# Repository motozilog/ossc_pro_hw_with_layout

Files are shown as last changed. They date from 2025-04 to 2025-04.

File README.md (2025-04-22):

# OSSC Pro HW with layout
==============

## No actual PCB was built from these files to validate the manufacturing.

This PCB full routing without DRC error, but I don't know how to make the trace length equal within a byte group. And the power doesn't optimized.

I share this PCB, may someone can finish it.

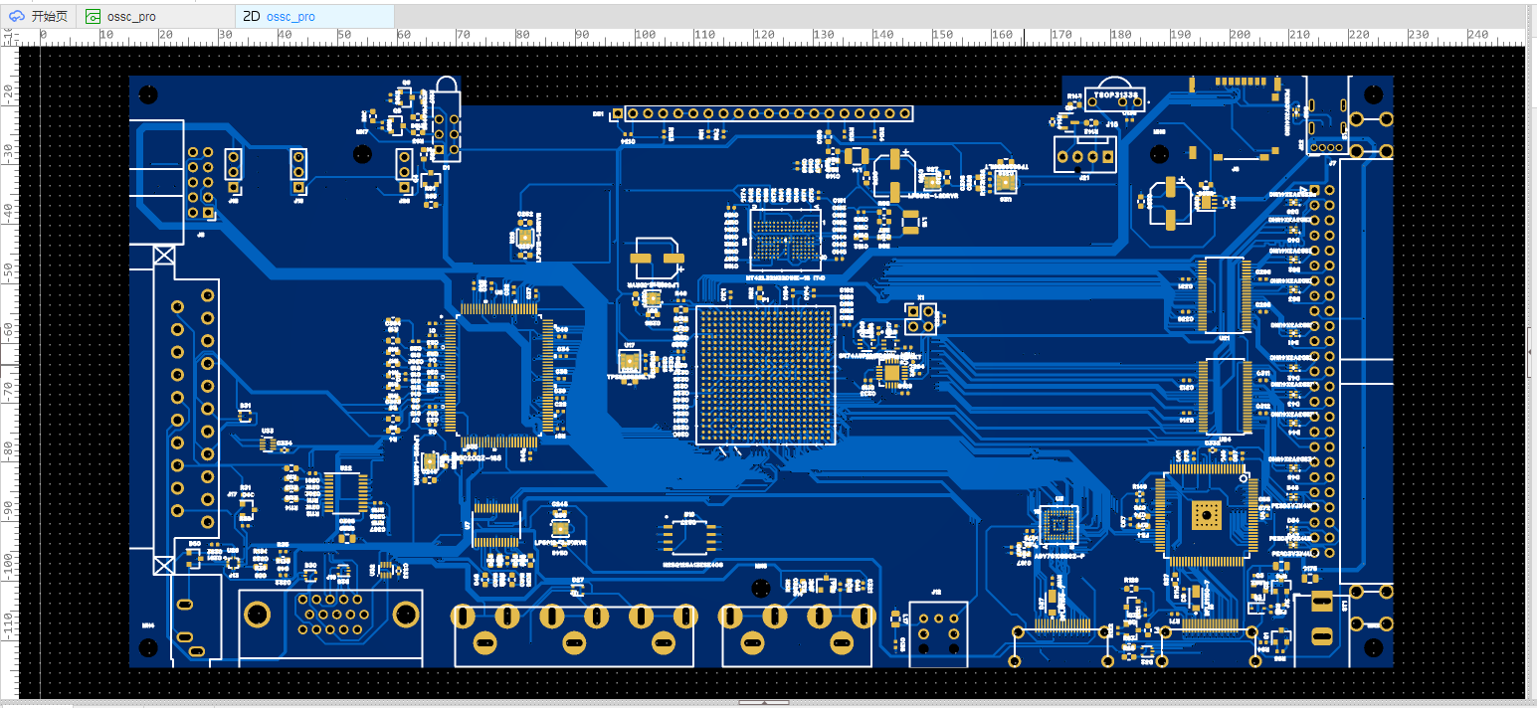
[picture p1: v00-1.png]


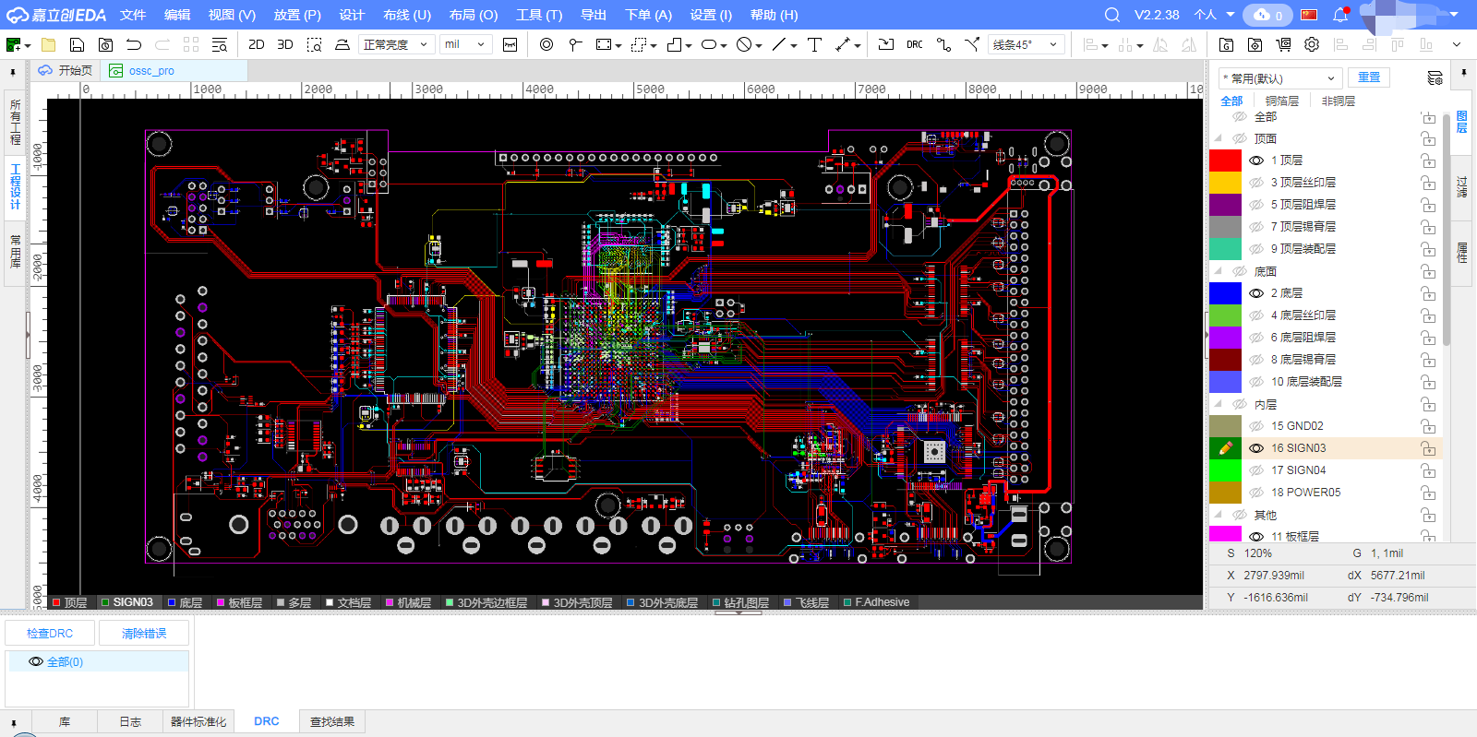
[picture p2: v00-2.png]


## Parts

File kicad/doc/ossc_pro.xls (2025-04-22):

Ref | Qnty | Value | Footprint | MPN | Alternative part | Supplier URL (if exists) | New part / updated MPN In v1.3 | New part / updated MPN In v1.4 | New part / updated MPN In v1.4-r2 | New part / updated MPN In v1.5 | New part / updated MPN In v1.6
C1, C2, C4, C22, C23, C24, C25, C26, C27, C28, C29, C32, C33, C34, C35, C36, C37, C38, C39, C40, C52, C55, C57, C58, C59, C60, C63, C64, C65, C67, C68, C70, C72, C73, C74, C75, C76, C79, C81, C82, C83, C87, C88, C89, C90, C95, C96, C97, C98, C99, C100, C101, C108, C109, C110, C111, C132, C133, C134, C135, C136, C137, C139, C140, C141, C142, C143, C144, C145, C146, C147, C148, C149, C151, C153, C154, C155, C156, C157, C158, C159, C160, C161, C162, C163, C164, C165, C166, C167, C168, C169, C170, C171, C172, C173, C174, C179, C180, C181, C182, C183, C184, C185, C186, C187, C188, C189, C190, C191, C192, C193, C194, C195, C198, C199, C200, C201, C202, C203, C204, C205, C206, C207, C208, C209, C210, C211, C212, C213, C214, C215, C216, C217, C219, C220, C221, C222, C223, C224, C225, C226, C227, C228, C229, C230, C231, C232, C233, C234, C235, C236, C237, C238, C239, C240, C241, C242, C243, C244, C256, C257, C258, C259, C260, C261, C269, C270, C271, C272, C274, C275, C276, C277, C278, C279, C280, C281, C282, C283, C284, C285, C291, C292, C293, C294, C295, C296, C298, C299, C301, C302, C303, C304, C309, C311, C312, C313, C314, C315, C316, C317, C324, C325, C326, C330, C331, C332, C333, C334, | 209 | 0.1u | Capacitor_SMD:C_0402_1005Metric | GCM155R71C104JA55D | CC0402JRX7R7BB104 | https://www.digikey.fi/product-detail/en/murata-electronics/GCM155R71C104JA55D/490-16433-1-ND/7363415
C7, C8, C9, C13, C14, C15, C16, C17, C18, C19, C20, C77, C78, C80, C84, C85, C86, C91, C92, C93, C94, C102, C103, C104, C300, C305, C318, C319, C320, C321, C322, C323, | 32 | 10n | Capacitor_SMD:C_0402_1005Metric | GCM155R71H103JA55D | CC0402JRX7R9BB103 | https://www.digikey.fi/product-detail/en/murata-electronics/GCM155R71H103JA55D/490-14352-1-ND/6606813
C45, C46, C47, C48, C49, C50, C53, C56, C61, C62, C69, C71, C105, C106, C107, C273, C327, | 17 | 10u | Capacitor_SMD:C_0603_1608Metric | GRM188R61A106KE69D | CC0603KRX5R6BB106 | https://www.digikey.fi/product-detail/en/murata-electronics/GRM188R61A106KE69D/490-10474-1-ND/5026392
C51, C54, C176, C177, C245, C246, C248, C249, C251, C252, C286, C287, | 12 | 2.2u | Capacitor_SMD:C_0603_1608Metric | GRM188R61E225KA12D | CC0603KRX5R8BB225 | https://www.digikey.fi/product-detail/en/murata-electronics/GRM188R61E225KA12D/490-10731-1-ND/5251369
C150, C152, C289, C290, | 4 | 4.7u | Capacitor_SMD:C_0603_1608Metric | GRM188R61C475KAAJD | CC0603KRX5R7BB475 | https://www.digikey.fi/product-detail/en/murata-electronics/GRM188R61C475KAAJD/490-10481-1-ND/5026399
C175, C306, | 2 | 47u | Capacitor_SMD:C_0805_2012Metric | GRM21BR61A476ME15L | CC0805MKX5R6BB476 | https://www.digikey.fi/product-detail/en/murata-electronics/GRM21BR61A476ME15L/490-9961-1-ND/5026442
C196, C197, C218, | 3 | 100u | Capacitor_SMD:CP_Elec_6.3x5.4 | EEE-0JA101SP |  | https://www.digikey.fi/product-detail/en/panasonic-electronic-components/EEE-0JA101SP/PCE3852CT-ND/766228
C254, C329, | 2 | 10u | Capacitor_SMD:C_0805_2012Metric | GRM21BR71A106KA73K | CC0805KKX7R6BB106 | https://www.digikey.fi/product-detail/en/murata-electronics/GRM21BR71A106KA73K/490-14381-1-ND/6606842
C255, C328, | 2 | 22u | Capacitor_SMD:C_0805_2012Metric | GRM21BR61A226ME51L | CC0805MKX5R6BB226 | https://www.digikey.fi/product-detail/en/murata-electronics/GRM21BR61A226ME51L/490-10511-1-ND/5026441
C307, C308, | 2 | 22p | Capacitor_SMD:C_0402_1005Metric | GCM1555C1H220JA16D | CC0402JRNPO9BN220 | https://www.digikey.fi/product-detail/en/murata-electronics/GCM1555C1H220JA16D/490-9648-1-ND/4879138
D1, | 1 | 5640100833F |  | 5640100833F |  | https://www.digikey.fi/products/en?keywords=5640100833F | X
D3, | 1 | BZX84C5V1/SOT | Package_TO_SOT_SMD:SOT-23 | BZX84C5V1-7-F |  | https://www.digikey.fi/product-detail/en/diodes-incorporated/BZX84C5V1-7-F/BZX84C5V1-FDICT-ND/827988
D5, D37, | 2 | DFLS1150-7 |  | DFLS1150-7 |  | https://www.digikey.fi/product-detail/en/diodes-incorporated/DFLS1150-7/DFLS1150DICT-ND/765635
D8, D9, D10, D11, | 4 | CPDA10R5V0P-HF |  | CPDA10R5V0P-HF | TPD4E02B04DQAR | https://www.digikey.fi/product-detail/en/comchip-technology/CPDA10R5V0P-HF/641-1750-1-ND/5400853 |  |  |  | X
D27, D28, D31, | 3 | PESD5V0U4BW | Package_TO_SOT_SMD:SOT-665 | PESD5V0U4BW,115 |  | https://www.digikey.fi/product-detail/en/nexperia-usa-inc/PESD5V0U4BW-115/1727-5804-1-ND/2697692
D30, D32, D33, | 3 | PESD5V0V4UW | Package_TO_SOT_SMD:SOT-665 | PESD5V0V4UW,115 |  | https://www.digikey.fi/product-detail/en/nexperia-usa-inc/PESD5V0V4UW-115/1727-5811-1-ND/2697758
D34, D35, D36, D38, D39, D40, D41, D42, D43, D44, D45, D46, D47, D48, D52, D53, D54, | 17 | PESD3V3X4UHC |  | PESD3V3X4UHCYL |  | https://www.digikey.fi/product-detail/en/nexperia-usa-inc/PESD3V3X4UHCYL/1727-8587-1-ND/10261013
D49, D50, D51, | 3 | PESD12VL2BT | Package_TO_SOT_SMD:SOT-23 | PESD12VL2BT,215 |  | https://www.digikey.fi/product-detail/en/nexperia-usa-inc/PESD12VL2BT-215/1727-3809-1-ND/1530813
DS1, | 1 | NHD-0220CW-AW3 | Connector_PinHeader_2.54mm:PinHeader_1x20_P2.54mm_Vertical | TSW-120-15-T-S |  | https://www.digikey.fi/product-detail/en/samtec-inc/TSW-120-15-T-S/SAM10361-ND/6679098
F1, | 1 | MF-FSMF020X-2 | Fuse:Fuse_0603_1608Metric | MF-FSMF020X-2 |  | https://www.digikey.fi/product-detail/en/bourns-inc/MF-FSMF020X-2/MF-FSMF020X-2CT-ND/2039387
FB1, FB2, FB3, FB4, FB5, FB6, FB7, | 7 | MPZ1608R391ATA00 | Inductor_SMD:L_0603_1608Metric | MPZ1608R391ATA00 |  | https://www.digikey.fi/product-detail/en/tdk-corporation/MPZ1608R391ATA00/445-2982-1-ND/1084525 |  | X
J2, J3, | 2 | 10029449-111RLF | custom_components:HDMI_CONN-10029449-111RLF | 10029449-111RLF |  | https://www.digikey.fi/product-detail/en/amphenol-icc-fci/10029449-111RLF/609-4614-1-ND/2785376
J5, | 1 | 503182-1852 | custom_components:MOLEX_503182-1852 | 503182-1852 |  | https://www.digikey.fi/product-detail/en/molex/5031821852/WM12834CT-ND/5823232
J7, | 1 | 30350-5002HB | Connector_IDC:IDC-Header_2x25_P2.54mm_Horizontal | 30350-5002HB |  | https://www.digikey.fi/products/en?keywords=30350-5002HB | X
J8, | 1 | 30310-5002HB | Connector_IDC:IDC-Header_2x05_P2.54mm_Horizontal | 30310-5002HB |  | https://www.digikey.fi/products/en?keywords=30310-5002HB
J10, | 1 | ICD15S13E4GX00LF | custom_components:VGA_CONN | ICD15S13E4GV00LF |  | https://www.digikey.fi/products/en?keywords=ICD15S13E4GV00LF |  |  |  | X
J11, | 1 | PJRAN3X1U03X | custom_components:3xRCA_CONN | PJRAN3X1U03X |  | https://www.digikey.fi/products/en?keywords=PJRAN3X1U03X
J12, | 1 | EAPLRAA4 | custom_components:EAPLRAA4 | FCR684208R |  | https://www.digikey.fi/products/en?keywords=FCR684208R |  |  |  | X
J13, | 1 | SJ1-3533NG | Connector_Audio:Jack_3.5mm_CUI_SJ1-3533NG_Horizontal | SJ1-3533NG |  | https://www.digikey.fi/products/en?keywords=SJ1-3533NG
J14, | 1 | PJRAN2X1U01X | custom_components:2xRCA_CONN | PJRAN2X1U02X |  | https://www.digikey.fi/products/en?keywords=PJRAN2X1U02X |  | X
J15, | 1 | TSOP31338 | custom_components:TSOP31..._1 | TSOP31338 |  | https://www.digikey.fi/products/en?keywords=TSOP31338
J16, | 1 | PJ-037A | Connector_BarrelJack:BarrelJack_Horizontal | PJ-037A |  | https://www.digikey.fi/product-detail/en/cui-devices/PJ-037A/CP-037A-ND/1644545 |  | X
J17, | 1 | K-SCARTX-022 | custom_components:SCART_CONN | SCART-17 NINIGI | K-SCARTX-022 | https://www.tme.eu/fi/en/details/scart-17/euro-hdmi-connectors/ninigi/ |  |  |  | X
J21, | 1 | 470531000 | Conn_01x04_Male | 470531000 |  | https://www.digikey.fi/fi/products/detail/molex/0470531000/2421261?s=N4IgTCBcDaIAwBYDscCsBmAjHHIC6AvkA |  |  | X
J22 | 1 | 673298000 | 673298000 | 673298000 |  | https://www.digikey.fi/en/products/detail/molex/0673298000/1243712?s=N4IgTCBcDaIAwDYDsBmMBOAHHHIC6AvkA |  |  |  | X
L14, L15, | 2 | 10u | Inductor_SMD:L_1210_3225Metric | LQH3NPN100MMEL |  | https://www.digikey.fi/product-detail/en/murata-electronics/LQH3NPN100MMEL/490-15945-1-ND/6800610
L17, | 1 | 47u | Inductor_SMD:L_0805_2012Metric | MLZ2012M470WT000 |  | https://www.digikey.fi/product-detail/en/tdk-corporation/MLZ2012M470WT000/445-6400-1-ND/2465726
P1, | 1 | 5CEFA5F23 | custom_components:5CEFA5F23 | 5CEFA5F23I7N |  | https://www.win-source.net/products/detail/altera/5cefa5f23i7n.html |  | X | X | X
Q1, Q2, Q7, | 3 | AOSS21115C | Package_TO_SOT_SMD:SOT-23 | AOSS21115C |  | https://www.digikey.fi/product-detail/en/alpha-omega-semiconductor-inc/AOSS21115C/785-AOSS21115CCT-ND/12327570 |  | X
Q3, | 1 | DSS20200L-7 | Package_TO_SOT_SMD:SOT-23 | DSS20200L-7 |  | https://www.digikey.fi/product-detail/en/diodes-incorporated/DSS20200L-7/DSS20200LDICT-ND/2044547 |  | X
Q4, Q5, Q6, Q8, Q9, | 5 | BC847 | Package_TO_SOT_SMD:SOT-23 | BC847C,215 |  | https://www.digikey.fi/product-detail/en/nexperia-usa-inc/BC847C-215/1727-2924-6-ND/1857745
R4, R5, R6, R10, R12, R13, R14, R17, R18, R19, R110, R113, R114, | 13 | 75 | Resistor_SMD:R_0603_1608Metric | RG1608P-750-D-T5 | RT0603DRE0775RL | https://www.digikey.fi/products/en?keywords=RG1608P-750-D-T5
R15, R111, R112, | 3 | 500 | Resistor_SMD:R_0402_1005Metric | RR0510P-4990-D | RC0402FR-07499RL | https://www.digikey.fi/product-detail/en/susumu/RR0510P-4990-D/RR05P499DCT-ND/969117
R52, R81, R123, R140, | 4 | 1k | Resistor_SMD:R_0402_1005Metric | RR0510P-102-D | RC0402DR-071KL | https://www.digikey.fi/product-detail/en/susumu/RR0510P-102-D/RR05P1-0KDCT-ND/432937
R31, R32, R33, R34, R35, R36, R98, R136, R137, R141, | 10 | 100k | Resistor_SMD:R_0402_1005Metric | RR0510P-104-D | RT0402DRE07100KL | https://www.digikey.fi/product-detail/en/susumu/RR0510P-104-D/RR05P100KDCT-ND/432982
R37, | 1 | 4.02k | Resistor_SMD:R_0603_1608Metric | RR0816P-4021-D-59H | RT0603DRD074K02L | https://www.digikey.fi/product-detail/en/susumu/RR0816P-4021-D-59H/RR08P4-02KDCT-ND/567286 |  | X
R45, R46, R49, R50, R51, R53, R54, R55, R56, R57, R58, R59, R63, R64, R71, R89, R91, R103, R104, R108, R121, R122, R124, R125, R126, R127, R128, R144, | 28 | 10k | Resistor_SMD:R_0402_1005Metric | CRCW040210K0FKEDC | RC0402FR-0710KL | https://www.digikey.fi/product-detail/en/vishay-dale/CRCW040210K0FKEDC/541-3959-1-ND/7928642
R47, R60, R61, R62, | 4 | 2.2k | Resistor_SMD:R_0402_1005Metric | RR0510P-222-D | RT0402DRE072K2L | https://www.digikey.fi/product-detail/en/susumu/RR0510P-222-D/RR05P2-2KDCT-ND/432944
R65, R66, R106, R107, R143, | 5 | 300 | Resistor_SMD:R_0603_1608Metric | CRCW0603300RFKEA | RC0603FR-07300RL | https://www.digikey.fi/product-detail/en/vishay-dale/CRCW0603300RFKEA/541-300HCT-ND/1179747
R67, R68, R100, R120, R142, | 5 | 2k | Resistor_SMD:R_0603_1608Metric | RR0816P-202-D | RC0603DR-072KL | https://www.digikey.fi/product-detail/en/susumu/RR0816P-202-D/RR08P2-0KDCT-ND/432731
R69, R70, R138, | 3 | 47k | Resistor_SMD:R_0402_1005Metric | RR0510P-473-D | RT0402DRD0747KL | https://www.digikey.fi/product-detail/en/susumu/RR0510P-473-D/RR05P47-0KDCT-ND/432975
R77, R78, R82, | 3 | 240 | Resistor_SMD:R_0603_1608Metric | RR0816P-241-D | RT0603DRE07240RL | https://www.digikey.fi/product-detail/en/susumu/RR0816P-241-D/RR08P240DCT-ND/432709
R79, | 1 | 4.7k | Resistor_SMD:R_0402_1005Metric | RR0510P-472-D | RT0402DRE074K7L | https://www.digikey.fi/product-detail/en/susumu/RR0510P-472-D/RR05P4-7KDCT-ND/432952
R83, R84, R87, R88, R117, | 5 | 1.5k | Resistor_SMD:R_0603_1608Metric | RR0816P-152-D | RT0603DRD071K5L | https://www.digikey.fi/product-detail/en/susumu/RR0816P-152-D/RR08P1-5KDCT-ND/432728
R85, R86, | 2 | 1 | Resistor_SMD:R_0603_1608Metric | CRCW06031R00FKEA | RC0603FR-071RL | https://www.digikey.fi/product-detail/en/vishay-dale/CRCW06031R00FKEA/541-1-00HHCT-ND/1961997
R92, R93, | 2 | 100 | Resistor_SMD:R_0603_1608Metric | RR0816P-101-D | RT0603DRE07100RL | https://www.digikey.fi/product-detail/en/susumu/RR0816P-101-D/RR08P100DCT-ND/432700 | X
R94, R95, R118, R119, | 4 | 27k | Resistor_SMD:R_0402_1005Metric | RR0510P-273-D | RT0402DRE0727KL | https://www.digikey.fi/product-detail/en/susumu/RR0510P-273-D/RR05P27-0KDCT-ND/432969
R96, | 1 | 330 | Resistor_SMD:R_0805_2012Metric | CRCW0805330RFKEAHP |  | https://www.digikey.fi/product-detail/en/vishay-dale/CRCW0805330RFKEAHP/541-330TCT-ND/5326905 | X
R97, R99, | 2 | 6.8k | Resistor_SMD:R_0402_1005Metric | RR0510P-682-D | RC0402DR-076K8L | https://www.digikey.fi/product-detail/en/susumu/RR0510P-682-D/RR05P6-8KDCT-ND/432956
R115, R116, R129, R130, R131, R132, R133, R134, | 8 | 100 | Resistor_SMD:R_0402_1005Metric | RR0510P-101-D | RC0402DR-07100RL | https://www.digikey.fi/product-detail/en/susumu/RR0510P-101-D/RR05P100DCT-ND/432914
R135, | 1 | 37.4k | Resistor_SMD:R_0402_1005Metric | RT0402BRD0737K4L | RT0402BRD0737K4L | https://www.digikey.fi/product-detail/en/yageo/RT0402BRD0737K4L/YAG4250CT-ND/6616406 | X
R145, R146, | 2 | 15k | Resistor_SMD:R_0402_1005Metric | RC0402FR-0715KL |  | https://www.digikey.fi/en/products/detail/yageo/RC0402FR-0715KL/726541 |  |  |  | X
ST1, ST2, | 2 | 7774 |  | 7774 |  | https://www.digikey.fi/product-detail/en/keystone-electronics/7774/36-7774-ND/2745944 |  | X | X
U2, | 1 | Si5351C | custom_components:QFN-20-1EP_4x4mm_Pitch0.5mm_Handsoldering | SI5351C-B-GM |  | https://www.digikey.fi/product-detail/en/silicon-labs/SI5351C-B-GM/336-2402-ND/3679850
U3, | 1 | ADV7610BBCZ-P | custom_components:ADV7610BBCZ | ADV7610BBCZ-P-RL |  | https://www.digikey.fi/products/en?keywords=ADV7610BBCZ-P-RL
U4, | 1 | SiI1136 | custom_components:TQFP-100_thermal | SII1136CTU |  | https://www.digikey.fi/products/en?keywords=SiI1136 |  | X
U7, | 1 | PCM1863 | Package_SO:TSSOP-30_4.4x7.8mm_P0.5mm | PCM1863DBTR |  | https://www.digikey.fi/product-detail/en/texas-instruments/PCM1863DBTR/296-47817-1-ND/8133166
U8, | 1 | ISL51002CQZ-165 | custom_components:ISL51002CQZ-165 | ISL51002CQZ-165 | ISL51002CQZ-150 | https://www.win-source.net/data-acquisition-analog-front-endafe-isl51002cqz-165.html |  |  |  | X
U9, | 1 | MT42L64M32D2HE-18 AAT:D | custom_components:EDB1332BDBH-1DAAT-F | MT42L32M32D1HE-18 IT:D | MT42L32M32D1HE-18 AAT:D | https://www.digikey.fi/en/products/detail/micron-technology-inc/MT42L32M32D1HE-18-IT-D/11193910 | X |  |  | X
U10, | 1 | N25Q128A13ESE40G | custom_components:N25Q128A13ESE40G | MT25QL128ABA1ESE-0SIT | N25Q128A13ESE40G | https://www.digikey.fi/product-detail/en/micron-technology-inc/MT25QL128ABA1ESE-0SIT-TR/557-1772-1-ND/6595653 |  |  | X
U17, U26 | 2 | TPS82085SILT | custom_components:TPS82084SILT | TPS82085SILT |  | https://www.digikey.fi/product-detail/en/texas-instruments/TPS82085SILT/296-42112-1-ND/5253913 | X |  | X
U19, | 1 | AP7361C-33FGE-7 |  | AP7361C-33FGE-7 |  | https://www.digikey.fi/product-detail/en/diodes-incorporated/AP7361C-33FGE-7/AP7361C-33FGE-7DICT-ND/5638334
U20, | 1 | FSA2275UMX |  | FSA2275UMX |  | https://www.digikey.fi/product-detail/en/on-semiconductor/FSA2275UMX/FSA2275UMXCT-ND/5322308
U21, U24, | 2 | SN74AVC16T245DGGR | Package_SO:TSSOP-48_6.1x12.5mm_P0.5mm | SN74AVC16T245DGGR |  | https://www.digikey.fi/product-detail/en/texas-instruments/SN74AVC16T245DGGR/296-18197-1-ND/770751
U22, | 1 | THS7353 | Package_SO:TSSOP-20_4.4x6.5mm_P0.65mm | THS7353PWR |  | https://www.digikey.fi/product-detail/en/texas-instruments/THS7353PWR/296-31937-1-ND/3506189
U23, U25, | 2 | SN74AUP1G17DCKT | DCK5_TEX | SN74AUP1G17DCKT |  | https://www.digikey.fi/product-detail/en/texas-instruments/SN74AUP1G17DCKT/296-SN74AUP1G17DCKTCT-ND/10665699
U27, | 1 | LP5912-1.2DRVR | custom_components:LP5912-1.2DRVR | LP5912-1.2DRVR |  | https://www.digikey.fi/product-detail/en/texas-instruments/LP5912-1-2DRVR/296-48301-1-ND/8347720
U28, U29, | 2 | LP5912-1.8DRVR | custom_components:LP5912-1.2DRVR | LP5912-1.8DRVR |  | https://www.digikey.fi/product-detail/en/texas-instruments/LP5912-1-8DRVR/296-47213-1-ND/7688223
U30, | 1 | LP5912-3.3DRVR | custom_components:LP5912-1.2DRVR | LP5912-3.3DRVR |  | https://www.digikey.fi/product-detail/en/texas-instruments/LP5912-3-3DRVR/296-47214-1-ND/7688224
U31, | 1 | LP5912-2.5DRVR | custom_components:LP5912-1.2DRVR | LP5912-2.5DRVR |  | https://www.digikey.fi/product-detail/en/texas-instruments/LP5912-2-5DRVR/296-53181-1-ND/9860179
U32, U33, | 2 | SN74LVC2G17 |  | SN74LVC2G17DCKR |  | https://www.digikey.fi/fi/products/detail/texas-instruments/SN74LVC2G17DCKR/479737 |  |  |  |  | X
X1, | 1 | FNSURV027 |  | FNSURV027 |  | https://www.digikey.fi/product-detail/en/diodes-incorporated/FNSURV027/FNSURV027CT-ND/2273416
Display assembly
DS-DS1 | 1 |  |  | REA002002A | NHD-0220CW-AB3 | https://www.raystar-optronics.com/oled-character-display-module/2.93-oled.html |  |  |  | X
DS-J1 | 1 |  |  | PPTC201LGBN-RC |  | https://www.digikey.fi/product-detail/en/sullins-connector-solutions/PPTC201LGBN-RC/S5456-ND/775914
Button panel assembly
J18, J19, J20, | 3 | TSW-101-08-T-T-RA | Connector_PinHeader_2.54mm:PinHeader_1x03_P2.54mm_Vertical | TSW-101-08-T-T-RA | TSW-101-08-G-T-RA | https://www.digikey.fi/products/en?KeyWords=TSW-101-08-T-T-RA | X
BP-SW1 | 1 |  |  | 311110004 | SKQUCAA010 | https://www.digikey.fi/products/en?keywords=311110004
BP-SW2 | 1 |  |  | B3F-4050 |  | https://www.digikey.fi/products/en?keywords=B3F-4050 | X
BP-CV1 | 1 |  |  | 4697 |  | https://www.digikey.fi/product-detail/en/adafruit-industries-llc/4697/1528-4697-ND/12760929
BP-CV2 | 1 |  |  | B32-1610 |  | https://www.digikey.fi/products/en?keywords=B32-1610 | X
Heatsinks
HS-P1 | 1 |  |  | HSB18-232310 | ATS-52230B-C1-R0 | https://www.digikey.fi/en/products/detail/cui-devices/HSB18-232310/14567081 |  |  |  | X
HS-U8 | 1 |  |  | GD024 |  | https://www.aliexpress.com/item/32245171440.html |  |  |  | X

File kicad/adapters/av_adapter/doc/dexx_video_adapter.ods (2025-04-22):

Ref | Qnty | Value | MPN | Vendor URL
D1, | 1 | 1N4148W | 1N4148W | https://www.digikey.fi/en/products/detail/diotec-semiconductor/1N4148W/18833653
J1, | 1 | SCART-F | SCART-17 | https://www.tme.eu/en/details/scart-17/euro-hdmi-connectors/ninigi/
J2, | 1 | Pr | RCJ-022 | https://www.digikey.fi/en/products/detail/cui-devices/RCJ-022/408494
J3, | 1 | Y | RCJ-026 | https://www.digikey.fi/en/products/detail/cui-devices/RCJ-026/408498
J4, | 1 | Pb | RCJ-025 | https://www.digikey.fi/en/products/detail/cui-devices/RCJ-025/408497
J5, | 1 | AudioJack3 | SJ1-3533NG | https://www.digikey.fi/en/products/detail/cui-devices/SJ1-3533NG/738701
J6, | 1 | DB15_Female_HighDensity | ICD15S13E4GV00LF | https://www.digikey.fi/en/products/detail/amphenol-cs-fci/ICD15S13E4GV00LF/1536418
R1 | 1 | 150 | RC0603FR-07150RL | https://www.digikey.fi/en/products/detail/yageo/RC0603FR-07150RL/726958
R2 | 1 | 470 | RC0603FR-07470RL | https://www.digikey.fi/fi/products/detail/yageo/RC0603FR-07470RL/727256
SW1, SW2 | 1 | SW_DPDT | OS202011MA0QS1 | https://www.digikey.fi/en/products/detail/c-k/OS202011MA0QS1/1981435

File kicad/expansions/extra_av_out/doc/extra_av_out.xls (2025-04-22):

Source: | /home/markus/Code/ossc_pro/pcb/expansions/extra_av_out/extra_av_out.kicad_sch
Date: | 2023-12-11T22:49:20 EET
Tool: | Eeschema 7.0.8+dfsg-1
Generator: | /usr/share/kicad/plugins/bom_csv_grouped_by_value_with_fp.py
Component Count: | 48
Ref | Qnty | Value | Footprint | MPN | Supplier URL (if exists)
C1, C3, C5, C8, C10, C15, C16, C18, C21, C22, | 10 | 0.1u | custom_components:SM0603_Capa_libcms | CC0603JRX7R7BB104 | https://www.digikey.fi/product-detail/en/yageo/CC0603JRX7R7BB104/311-1776-1-ND/5195678
C2, C17, C19, | 3 | 10n | custom_components:SM0603_Capa_libcms | CC0603JRX7R9BB103 | https://www.digikey.fi/product-detail/en/yageo/CC0603JRX7R9BB103/311-1778-1-ND/5195680
C4 | 1 | 10u | custom_components:SM0603_Capa_libcms | CC0603MPX5R5BB106 | https://www.digikey.fi/product-detail/en/yageo/CC0603MPX5R5BB106/13-CC0603MPX5R5BB106CT-ND/13900022
C7, C9, | 2 | 2.2u | custom_components:SM0603_Capa_libcms | CC0603KRX5R5BB225 | https://www.digikey.fi/product-detail/en/yageo/CC0603KRX5R5BB225/311-1449-2-ND/2833614
C11, C13, | 2 | 2.2n | custom_components:SM0603_Capa_libcms | CC0603JRX7R9BB222 | https://www.digikey.fi/product-detail/en/yageo/CC0603JRX7R9BB222/311-3618-1-ND/7648545
C20, | 1 | 1u | custom_components:SM0603_Capa_libcms | CC0603JRX7R6BB105 | https://www.digikey.fi/product-detail/en/yageo/CC0603JRX7R6BB105/311-3484-1-ND/7164505
D1, | 1 | AD1580 | Package_TO_SOT_SMD:SOT-23_Handsoldering | AD1580BRTZ-REEL7 | https://www.digikey.fi/product-detail/en/analog-devices-inc/AD1580BRTZ-REEL7/AD1580BRTZ-REEL7CT-ND/936749
D2 | 1 | PESD5V0V4UW | Package_TO_SOT_SMD:SOT-665 | PESD5V0V4UW,115 | https://www.digikey.fi/en/products/detail/nexperia-usa-inc/PESD5V0V4UW-115/1157473
D3 | 1 | PESD12VL2BT | Package_TO_SOT_SMD:SOT-23 | PESD12VL2BT,215 | https://www.digikey.fi/en/products/detail/nexperia-usa-inc/PESD12VL2BT-215/1157413
D4 | 1 | PESD5V0U4BW | Package_TO_SOT_SMD:SOT-665 | PESD5V0U4BW,115 | https://www.digikey.fi/en/products/detail/nexperia-usa-inc/PESD5V0U4BW-115/2119845
FB1, FB2 | 2 | MPZ1608S102ATA00 | custom_components:SM0603_Resistor_libcms | MPZ1608S102ATA00 | https://www.digikey.fi/en/products/detail/tdk-corporation/MPZ1608S102ATA00/3078621
J1, | 1 | Conn_02x25_Odd_Even | Connector_PinSocket_2.54mm:PinSocket_2x25_P2.54mm_Horizontal | SFH11-PBPC-D25-RA-BK | https://www.digikey.fi/product-detail/en/sullins-connector-solutions/SFH11-PBPC-D25-RA-BK/S9209-ND/1990102
J2, | 1 | SJ1-3533NG | Connector_Audio:Jack_3.5mm_CUI_SJ1-3533NG_Horizontal | SJ1-3533NG | https://www.digikey.fi/products/en?keywords=SJ1-3533NG
J3, | 1 | PLT133/T10W | custom_components:EAPLRAA4 | PLT133/T10W | https://www.digikey.fi/products/en?keywords=PLT133%2FT10W
J4, | 1 | VGA | custom_components:VGA_CONN | ICD15S13E4GV00LF | https://www.digikey.fi/products/en?keywords=ICD15S13E4GX00LF
Q1 | 1 | BC847 | Package_TO_SOT_SMD:SOT-23_Handsoldering | BC847C,215 | https://www.digikey.fi/en/products/detail/nexperia-usa-inc/BC847C-215/763240
R1, R12 | 2 | 10k | custom_components:SM0603_Resistor_libcms | RC0603FR-0710KL | https://www.digikey.fi/product-detail/en/yageo/RC0603FR-0710KL/311-10-0KHRCT-ND/729827
R2, R3, | 2 | 470 | custom_components:SM0603_Resistor_libcms | RC0603FR-07470RL | https://www.digikey.fi/product-detail/en/yageo/RC0603FR-07470RL/311-470HRCT-ND/730203
R4, | 1 | 530 | custom_components:SM0603_Resistor_libcms | RN73R1JTTD5300F100 | https://www.digikey.fi/product-detail/en/koa-speer-electronics-inc/RN73R1JTTD5300F100/2019-RN73R1JTTD5300F100CT-ND/12573885
R5, R6, R7, | 3 | 75 | custom_components:SM0603_Resistor_libcms | RG1608P-750-D-T5 | https://www.digikey.fi/products/en?keywords=RG1608P-750-D-T5
R8, | 1 | 1k | custom_components:SM0603_Resistor_libcms | RC0603FR-071KL | https://www.digikey.fi/product-detail/en/yageo/RC0603FR-071KL/311-1-00KHRCT-ND/729790
R9, R10, R11 | 3 | 47 | custom_components:SM0603_Resistor_libcms | RC0603FR-0747RL | https://www.digikey.fi/en/products/detail/yageo/RC0603FR-0747RL/727252
R13 | 1 | 4.7k | custom_components:SM0603_Resistor_libcms | RC0603FR-074K7L | https://www.digikey.fi/en/products/detail/yageo/RC0603FR-074K7L/727212
ST1, ST2, | 2 | Screw_Terminal_01x01 | custom_components:7773 | 7773 | https://www.digikey.fi/product-detail/en/keystone-electronics/7773/36-7773-ND/4499350
U1, | 1 | ADV7125KSTZ140 | Package_QFP:LQFP-48_7x7mm_P0.5mm | ADV7125KSTZ140 | https://www.digikey.fi/products/en?keywords=ADV7125KSTZ140
U2, | 1 | PCM5142PW | Package_SO:TSSOP-28_4.4x9.7mm_P0.65mm | PCM5142PWR | https://www.digikey.fi/product-detail/en/texas-instruments/PCM5142PWR/296-35528-1-ND/3789781
U3, | 1 | 74HCT2G17GW | Package_SO:TSOP-6_1.65x3.05mm_P0.95mm | 74HCT2G17GV,125 | https://www.digikey.fi/product-detail/en/nexperia-usa-inc/74HCT2G17GV-125/1727-8407-1-ND/9747975
screw | 2 |  |  | 21403 | https://www.digikey.fi/product-detail/en/keystone-electronics/21403/36-21403-ND/13968029

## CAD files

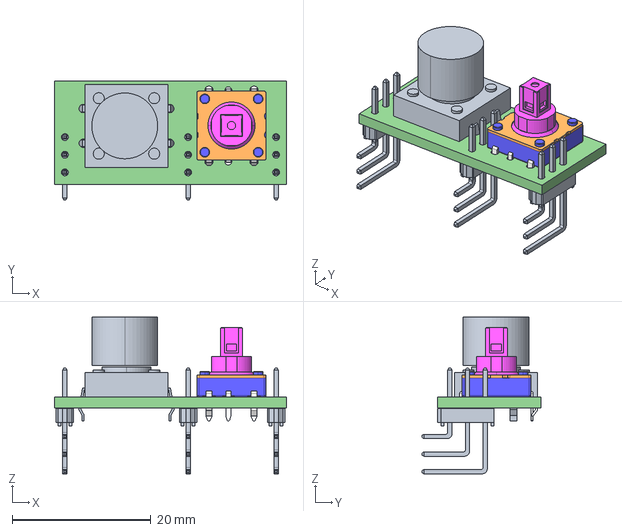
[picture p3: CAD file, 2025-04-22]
kicad/buttonpanel/panel.step
33.5 x 17.2 x 22.6 mm

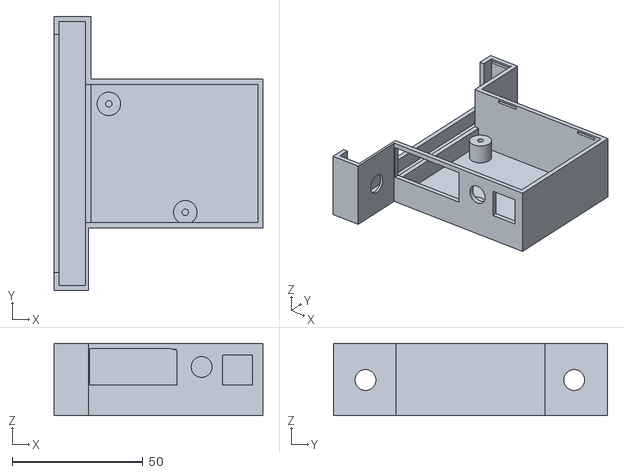
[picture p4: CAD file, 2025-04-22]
kicad/expansions/extra_av_out/case/extra_av_bot.stl
80.0 x 105.0 x 27.6

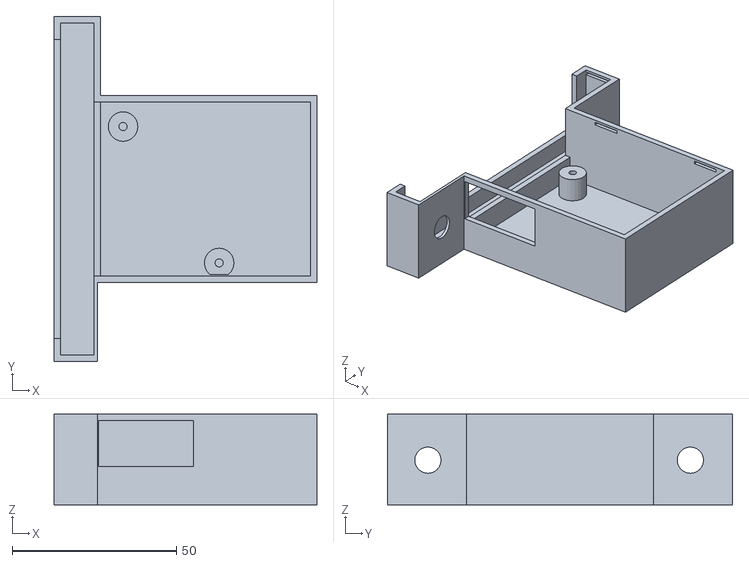
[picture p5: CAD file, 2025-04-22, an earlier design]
kicad/expansions/legacy_av_in/case/legacy_av_in_bot.stl
80.0 x 105.0 x 27.6

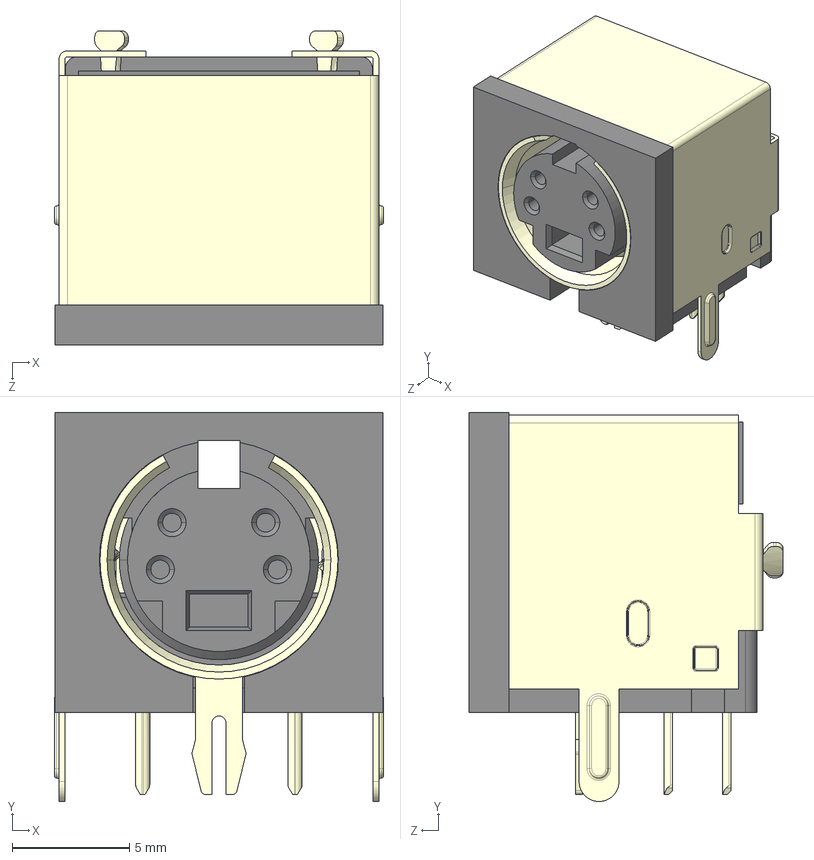
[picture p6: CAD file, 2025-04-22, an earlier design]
kicad/expansions/legacy_av_in/model-3d/CUI_DEVICES_MD-40SM.step
14.1 x 16.6 x 13.4 mm

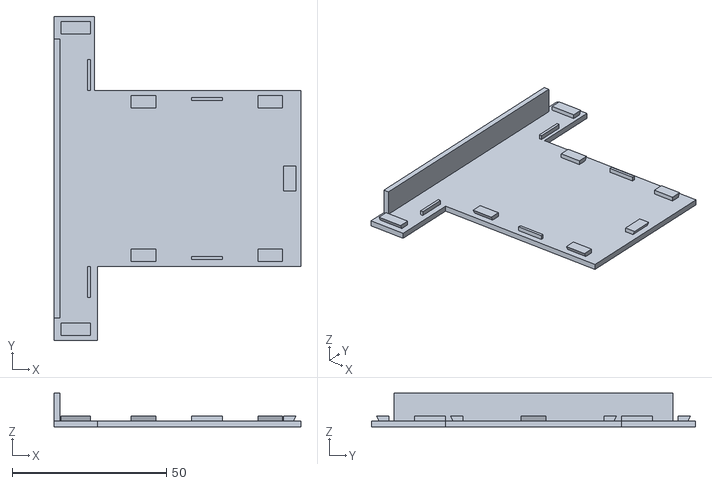
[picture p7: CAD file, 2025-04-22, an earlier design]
kicad/expansions/legacy_av_in/case/legacy_av_in_top.stl
80.0 x 105.0 x 11.0

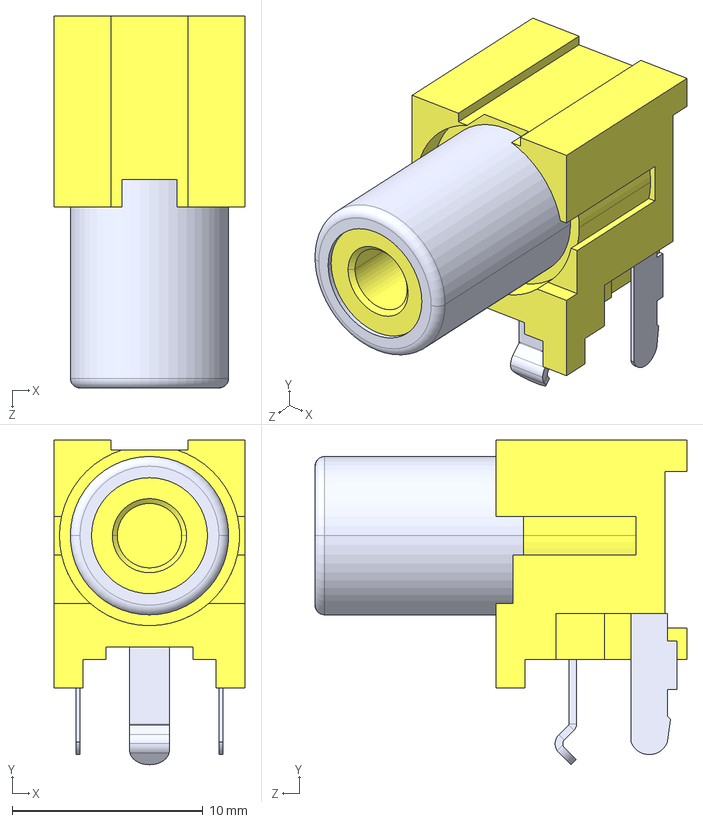
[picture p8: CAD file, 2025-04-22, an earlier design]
kicad/expansions/legacy_av_in/model-3d/PJRAN1X1U04X.step
10.0 x 17.0 x 19.5 mm

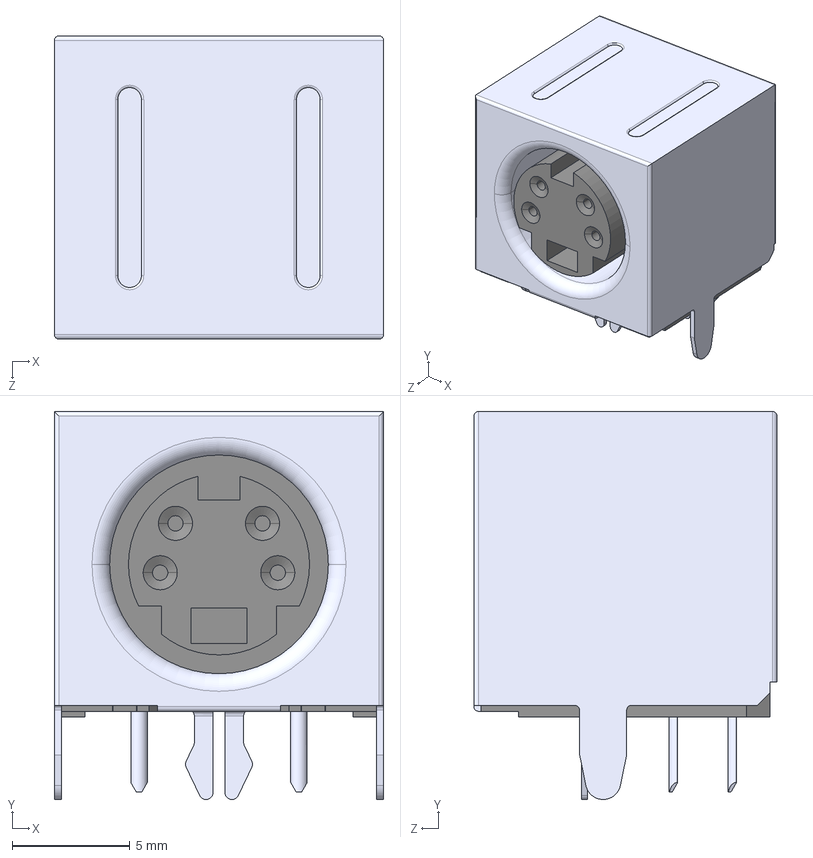
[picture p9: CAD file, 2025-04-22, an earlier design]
kicad/expansions/legacy_av_in/model-3d/KMDGX-4S-BS_rC6.STEP
14.0 x 16.5 x 12.9 mm

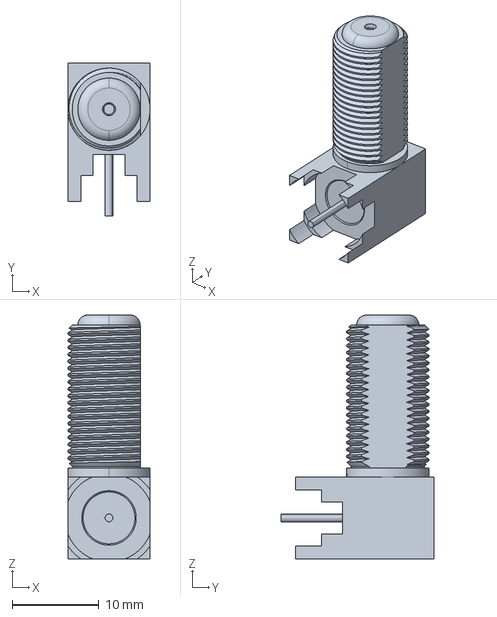
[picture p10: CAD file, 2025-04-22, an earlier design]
kicad/expansions/legacy_av_in/model-3d/733300030.stp
9.50 x 17.7 x 28.2 mm

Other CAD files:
kicad/expansions/extra_av_out/case/extra_av_top.stl

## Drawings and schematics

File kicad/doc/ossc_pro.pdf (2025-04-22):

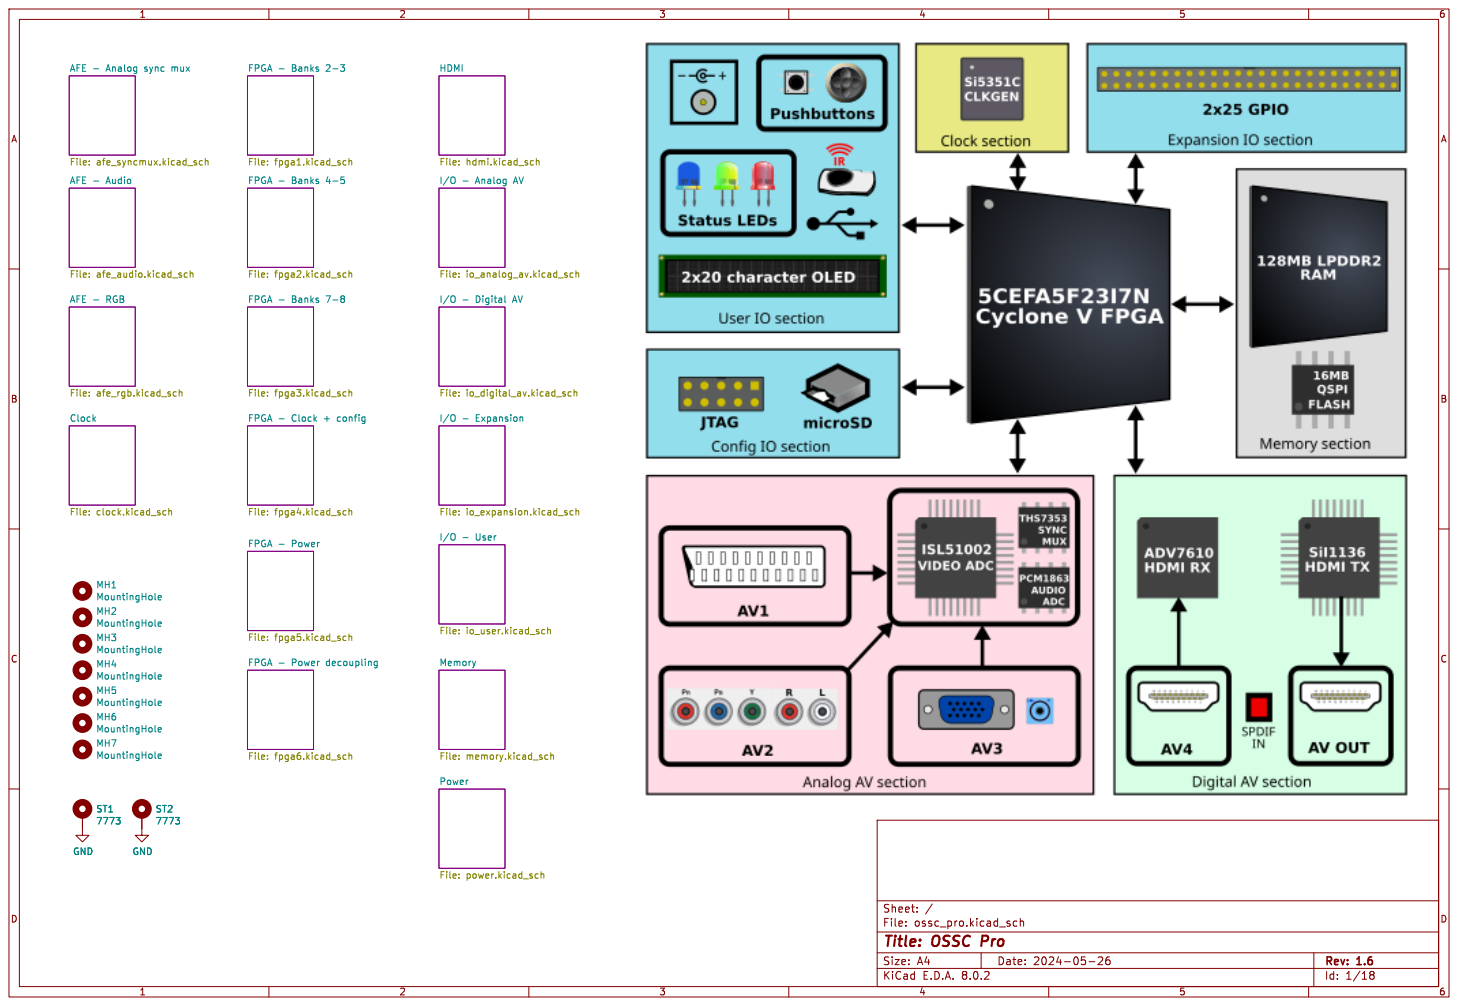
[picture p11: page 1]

AFE - Audio File: afe_audio.kicad_sch AFE - RGB

7773 MH1 MountingHole ST1
7773 MH7 MountingHole GND MH6 MountingHole MH4 MountingHole MH5 MountingHole GND MH2 MountingHole MH3 MountingHole GND

File: ossc_pro.kicad_sch Sheet: /
Id: 1/18 Title: OSSC Pro

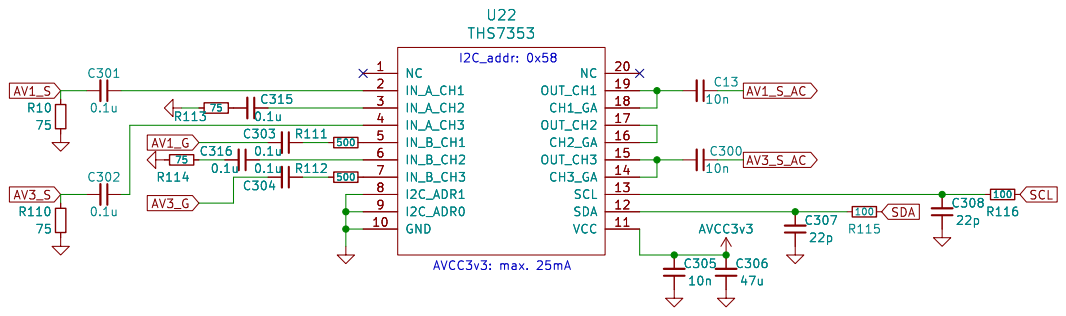
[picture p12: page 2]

File: afe_syncmux.kicad_sch Sheet: /AFE - Analog sync mux/
Id: 2/18 Title: OSSC Pro

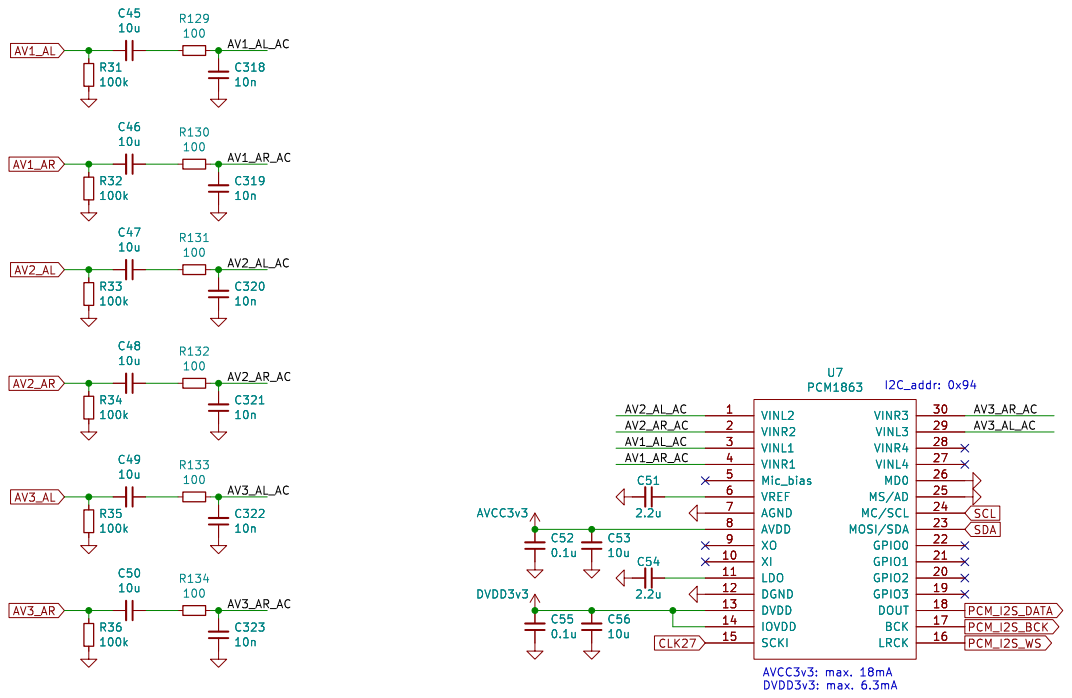
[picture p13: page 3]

File: afe_audio.kicad_sch Sheet: /AFE - Audio/
Id: 3/18 Title: OSSC Pro

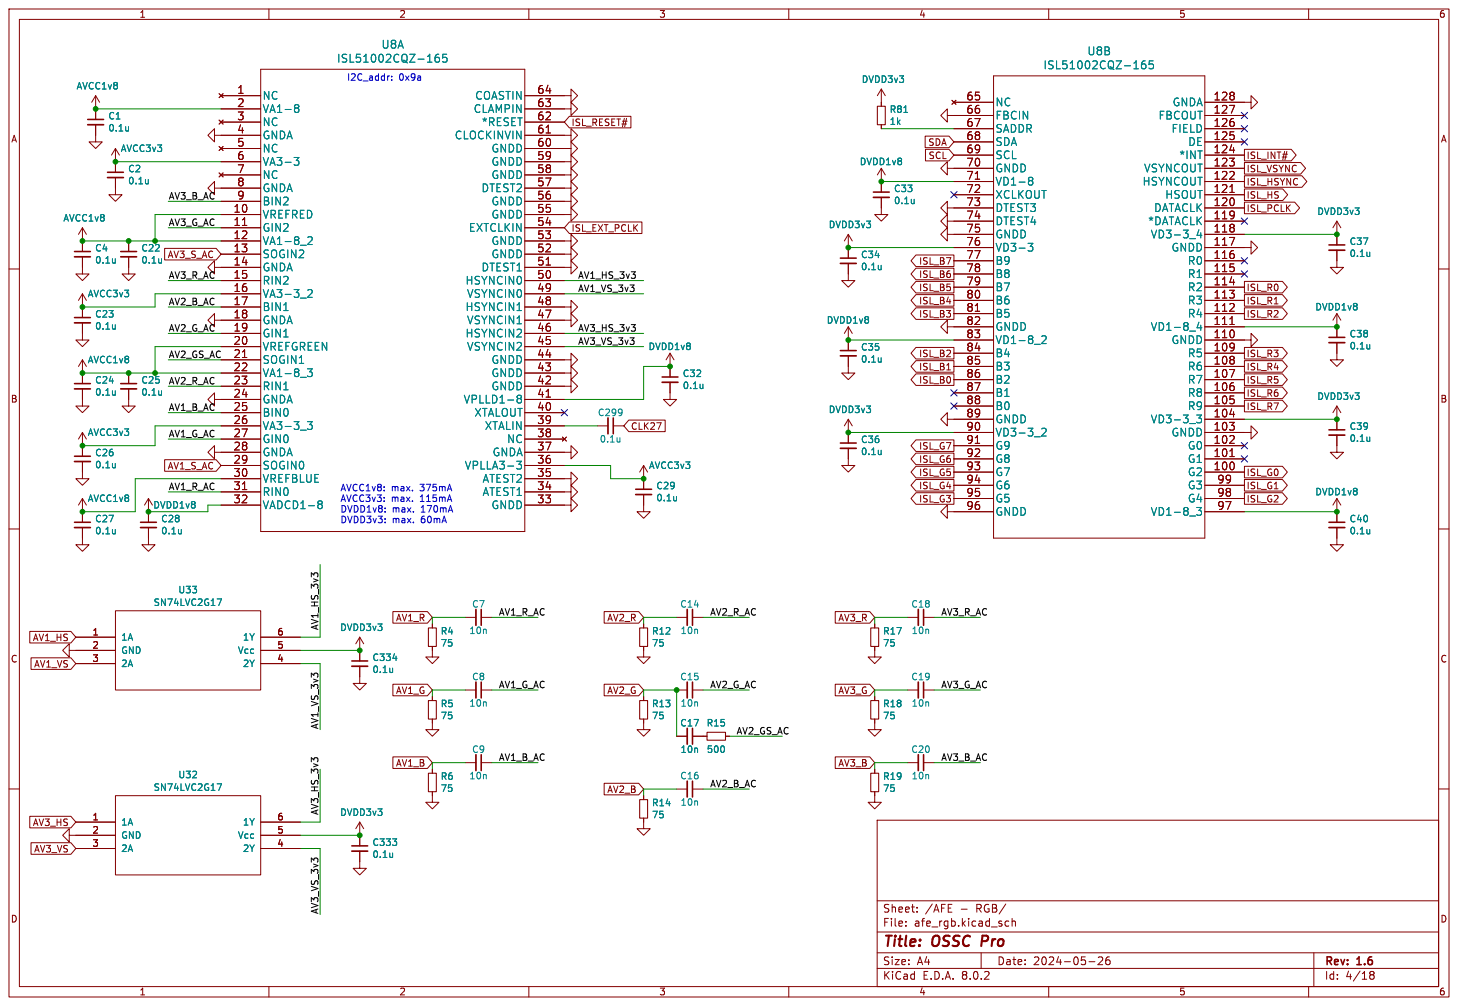
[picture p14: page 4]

Id: 4/18 Title: OSSC Pro

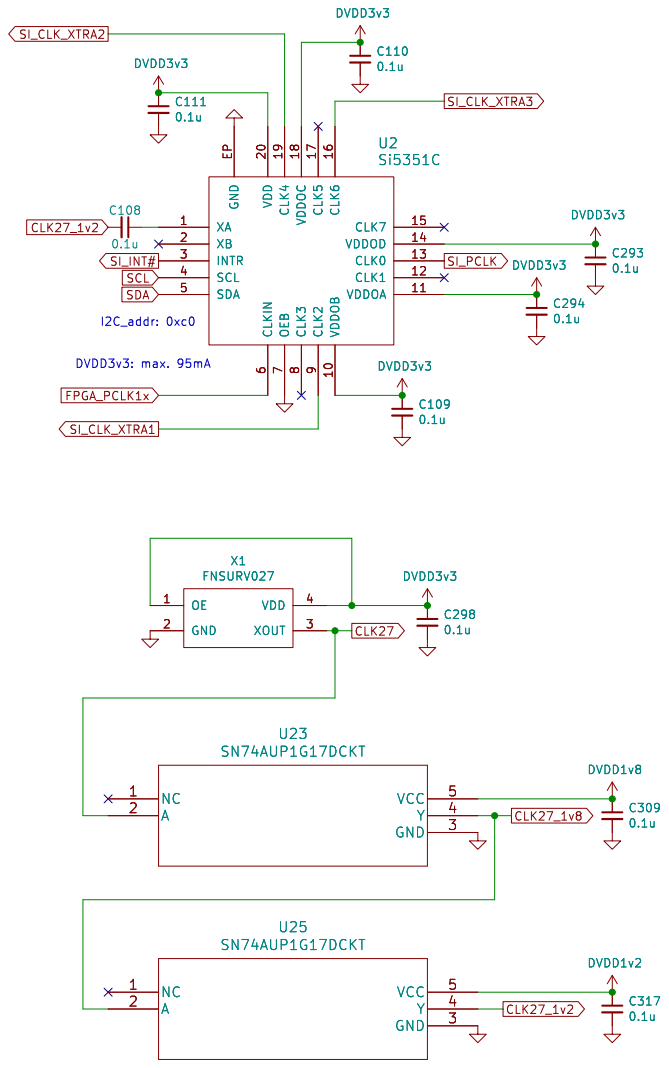
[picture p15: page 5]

File: clock.kicad_sch Sheet: /Clock/
Id: 5/18 Title: OSSC Pro

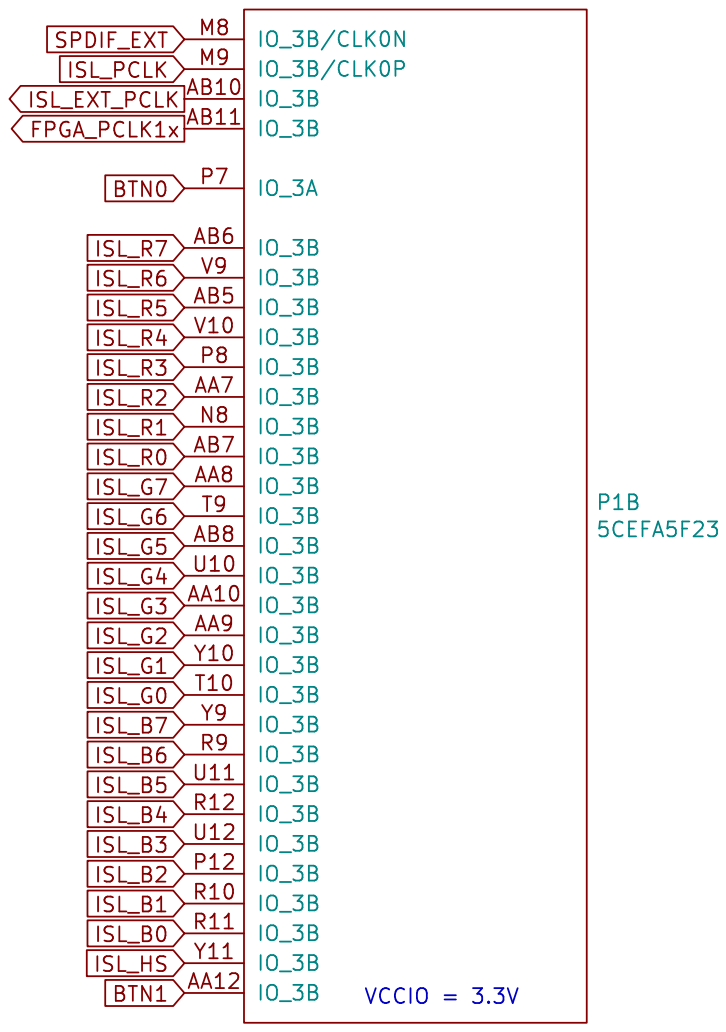
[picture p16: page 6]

Id: 6/18 Title: OSSC Pro

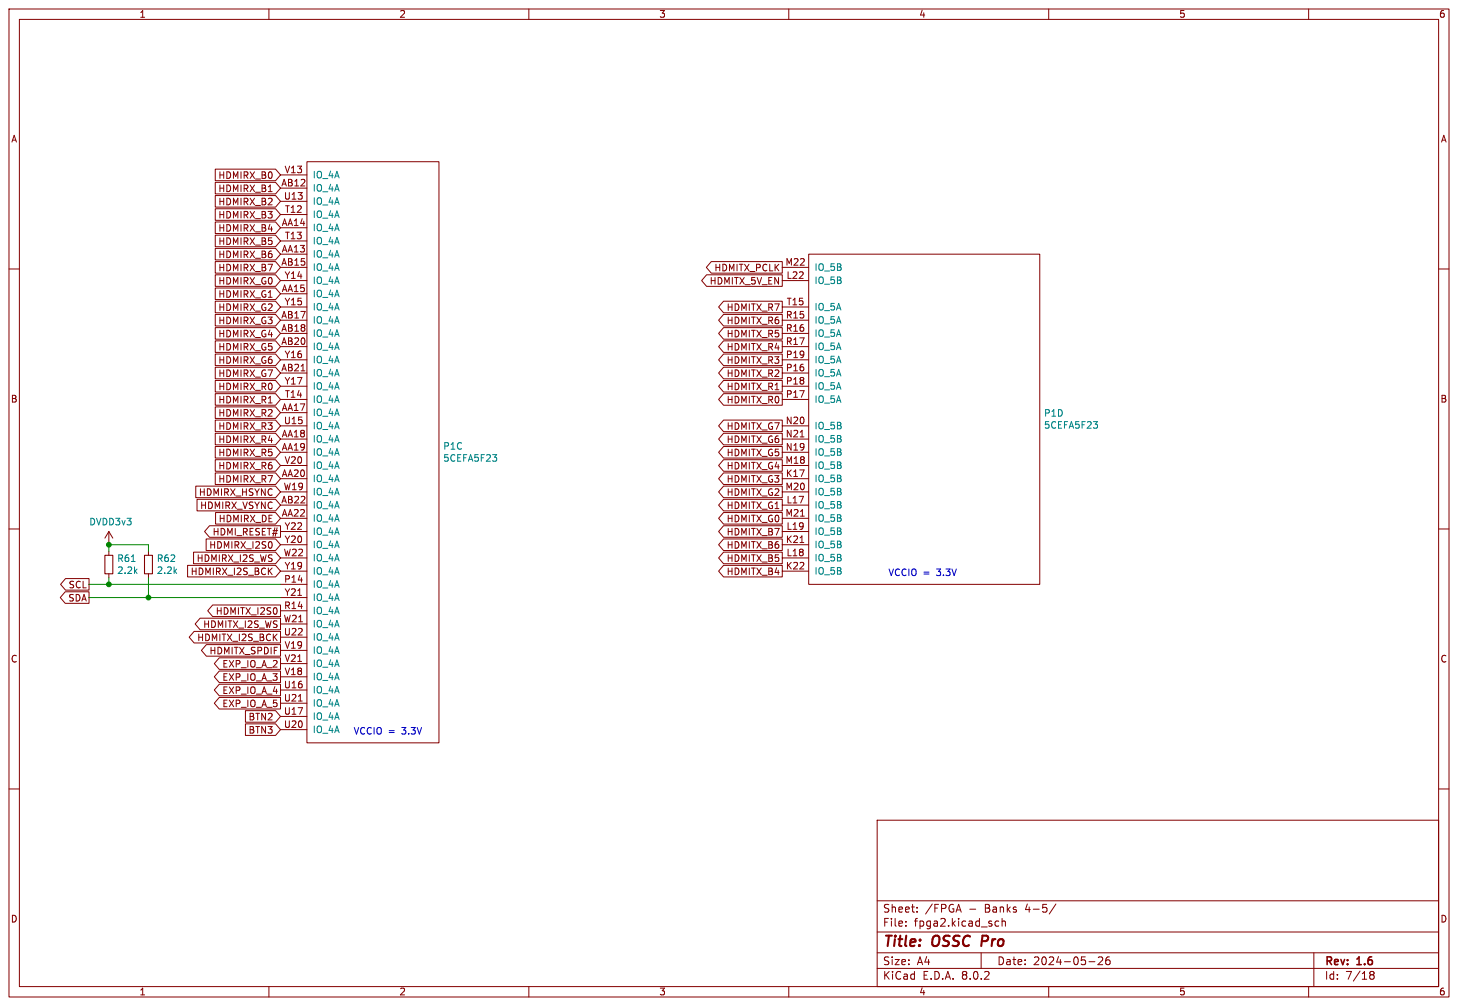
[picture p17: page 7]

Id: 7/18 Title: OSSC Pro

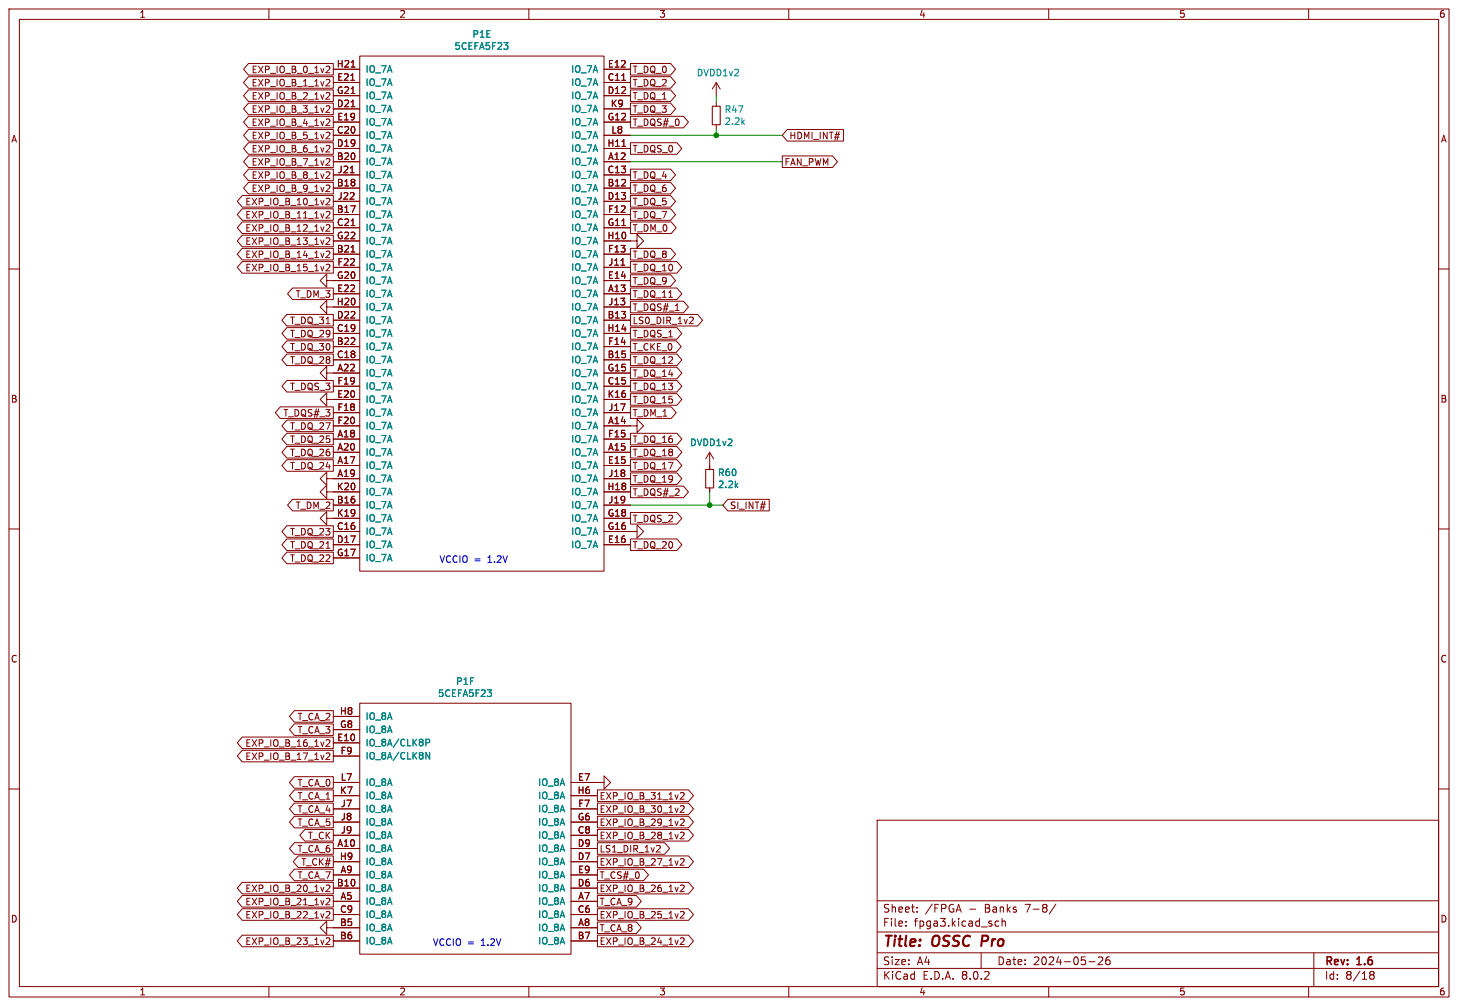
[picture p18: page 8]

Id: 8/18 Title: OSSC Pro

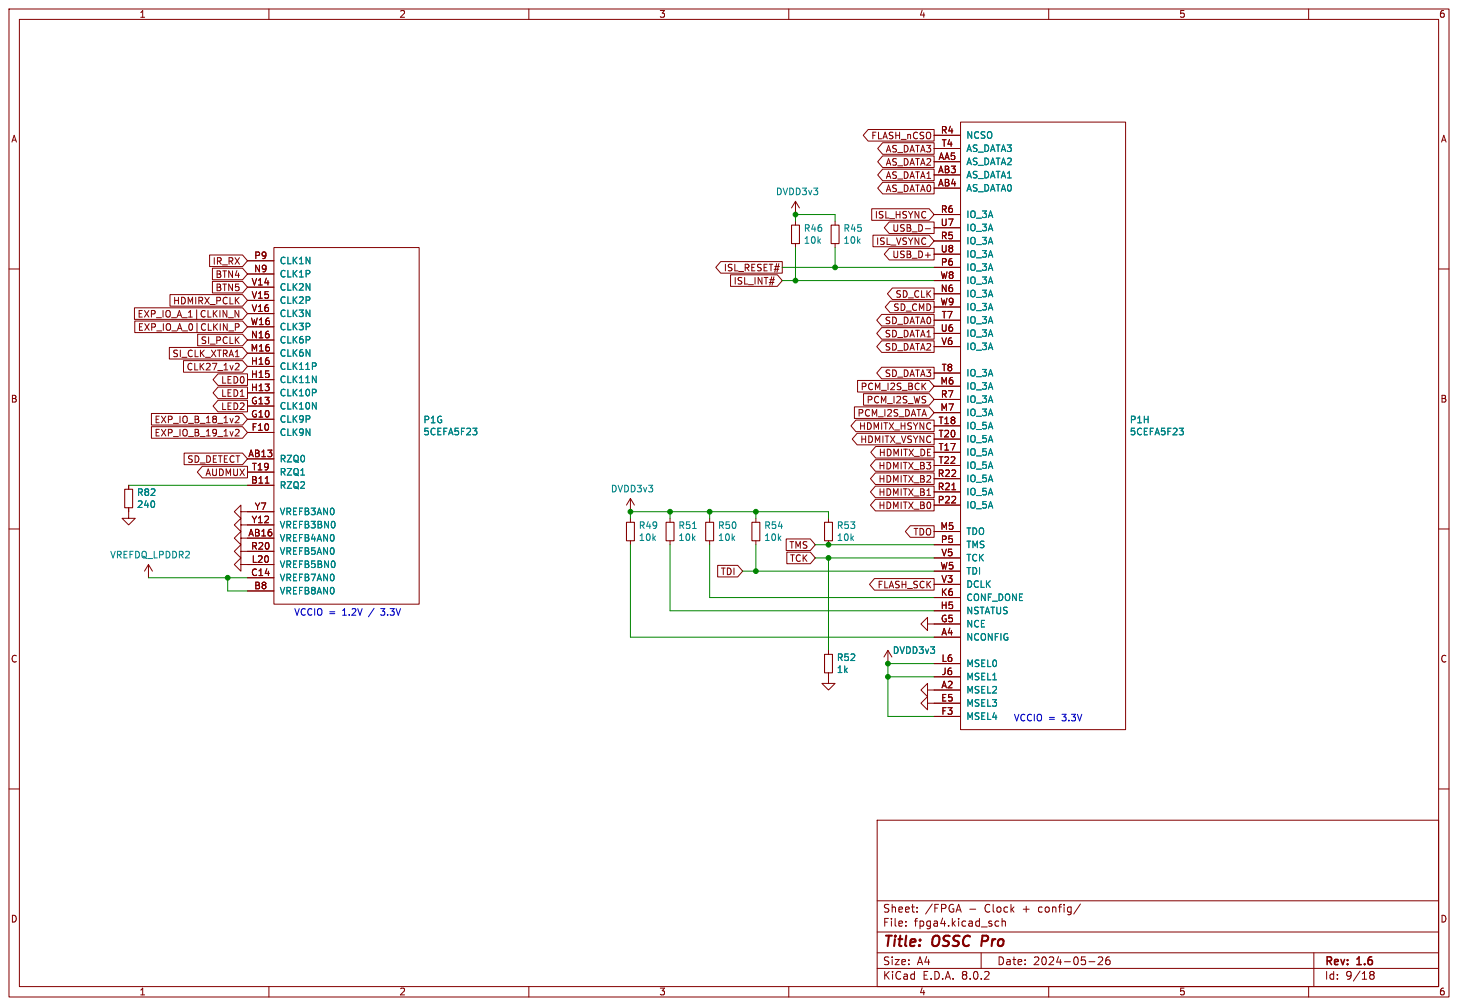
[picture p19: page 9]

Id: 9/18 Title: OSSC Pro

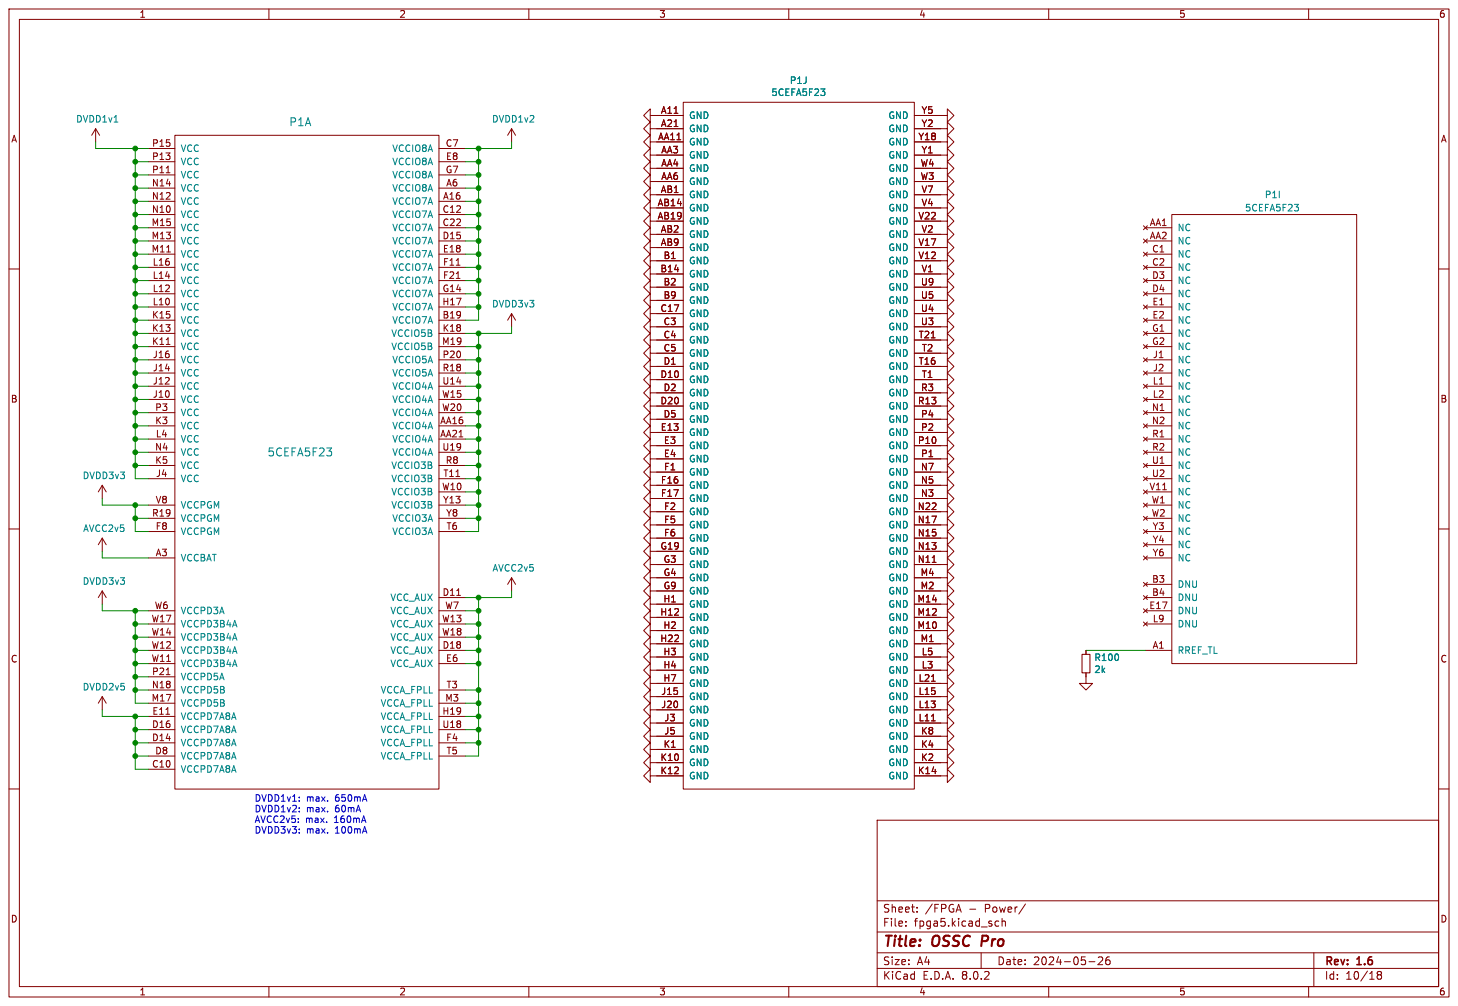
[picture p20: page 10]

Id: 10/18 Title: OSSC Pro

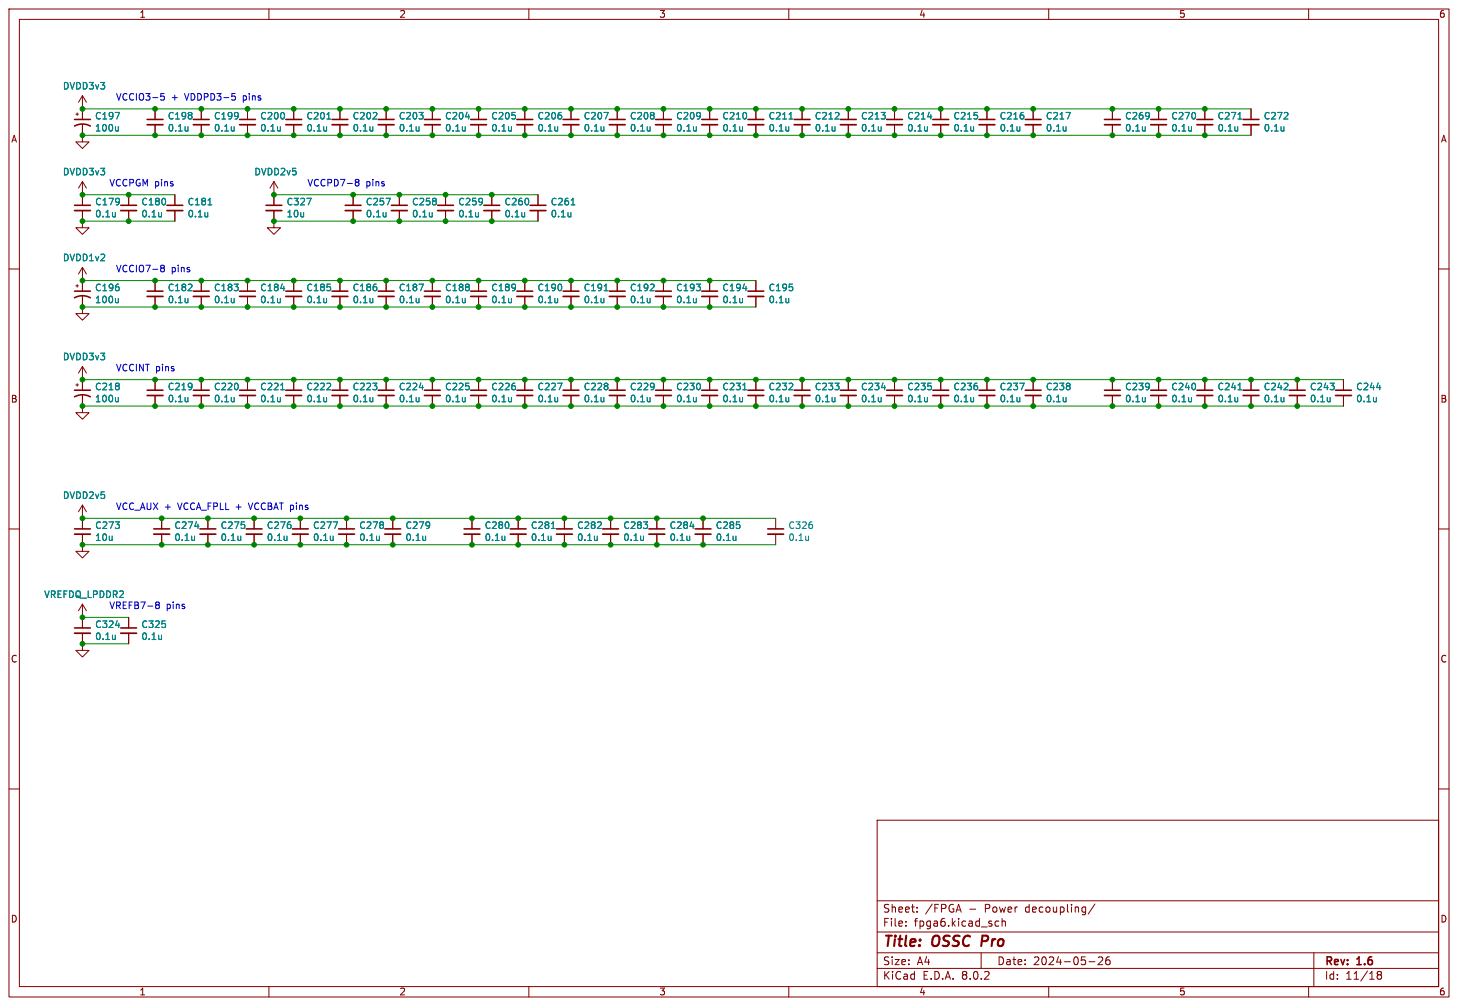
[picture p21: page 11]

Id: 11/18 Title: OSSC Pro

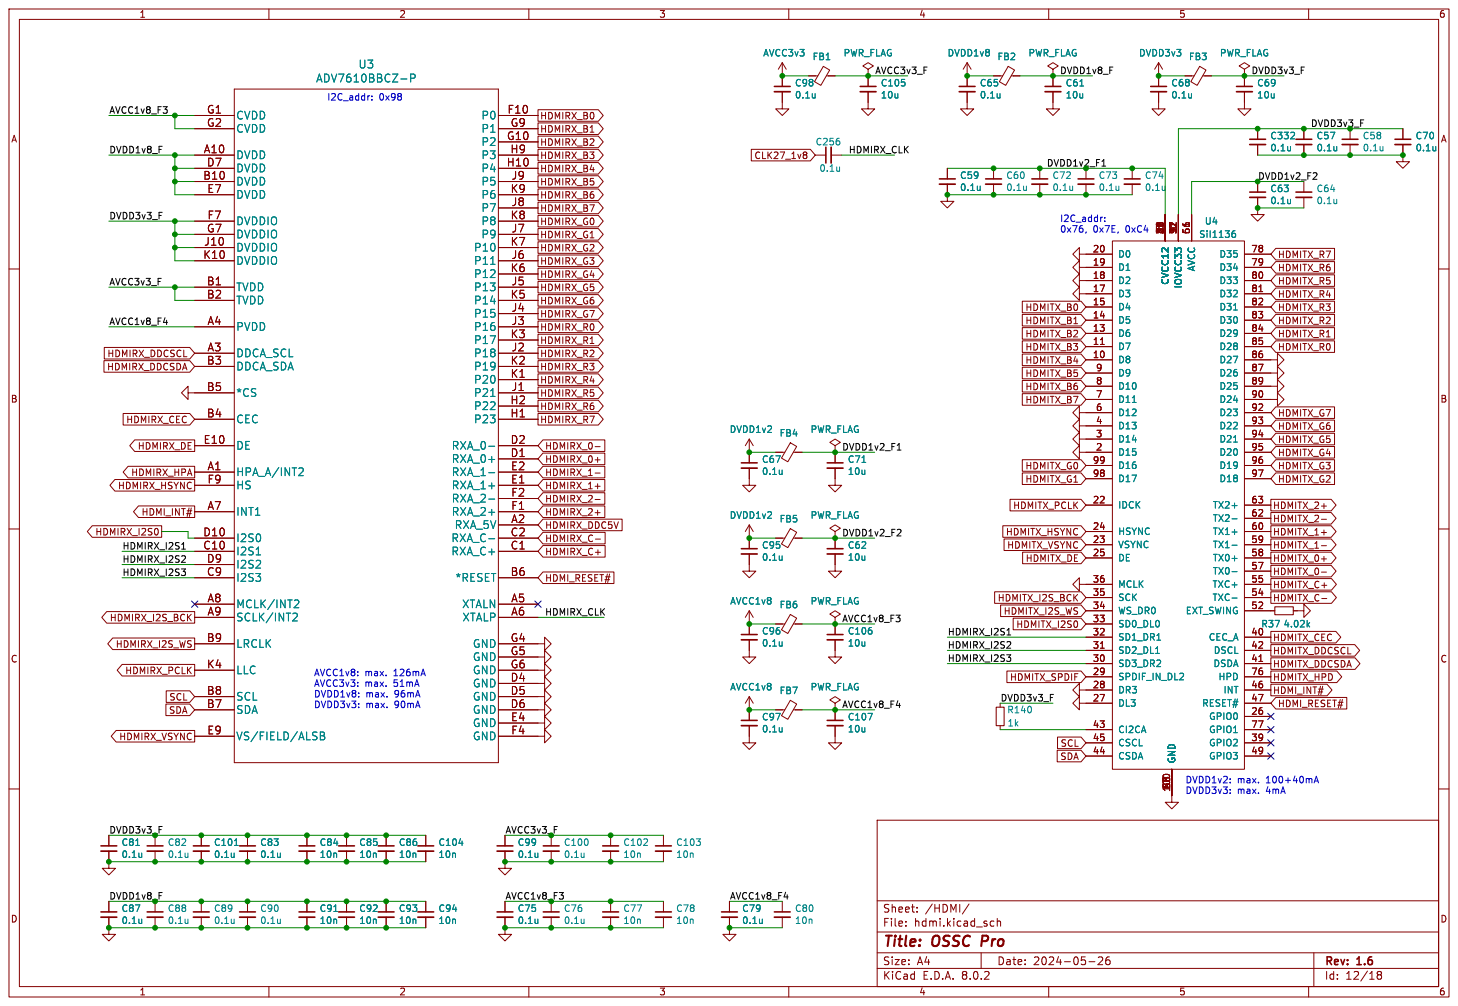
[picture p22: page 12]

File: hdmi.kicad_sch Sheet: /HDMI/ PWR_FLAG

5 EXT_SWING 52 GND 53 TXC- 54 TXC+ 55 AVCC 56 TX0- 57 TX0+ 58 TX1- 59 D12 6 TX1+ 60 AVCC 61 TX2- 62 TX2+ 63 D11 7 HPD 76 GPIO1 77

Id: 12/18 Title: OSSC Pro


Id: 13/18 Title: OSSC Pro


Id: 14/18 Title: OSSC Pro


Id: 15/18 Title: OSSC Pro


Id: 16/18 Title: OSSC Pro


File: memory.kicad_sch Sheet: /Memory/ VREFDQ_LPDDR2 C168

Id: 17/18 Title: OSSC Pro


2 3 Q3 DSS20200L-7 OUT 1 NC 2 PG 3 EN 4 GND 5

output draw rated up to 3A

File: power.kicad_sch Sheet: /Power/
Id: 18/18 Title: OSSC Pro

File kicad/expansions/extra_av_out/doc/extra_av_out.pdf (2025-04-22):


2 3 U1 ADV7125KSTZ140 GND 1 G7 10 BLANK* 11 SYNC* 12 VAA 13 GND 14 GND 15 B0 16 B1 17 B2 18 B3 19 GND 2 B4 20 B5 21 B6 22 B7 23 CLOCK 24 GND 25 GND 26 IOB* 27 IOB 28 VAA 29 G0 3 VAA 30 IOG* 31 IOG 32 IOR* 33 IOR 34 COMP 35 VREF 36 RSET 37 PSAVE* 38 GND 39 G1 4 GND 40 R0 41 R1 42 R2 43 R3 44 R4 45 R5 46 R6 47 R7 48 G2 5 G3 6 G4 7 G5 8 G6 9

LDOO 26 DGND 27 DVDD 28 CPGND

1 VCOM/DEMP 10 SDA/MOSI/ATT2 11 SCL/MC/ATT1 12 GPIO5/ATT0 13 GPIO4/MAST 14 GPIO3/AGNS 15 ADR2/GPIO2/DOUT 16 MODE1 17 MODE2/MS 18 GPIO6/FLT 19 CAPP 2 SCK 20 BCK 21 DIN 22

3 CAPM 4 VNEG 5 OUTL 6 OUTR 7 AVDD

Id: 1/1 Title: Extra AV out board

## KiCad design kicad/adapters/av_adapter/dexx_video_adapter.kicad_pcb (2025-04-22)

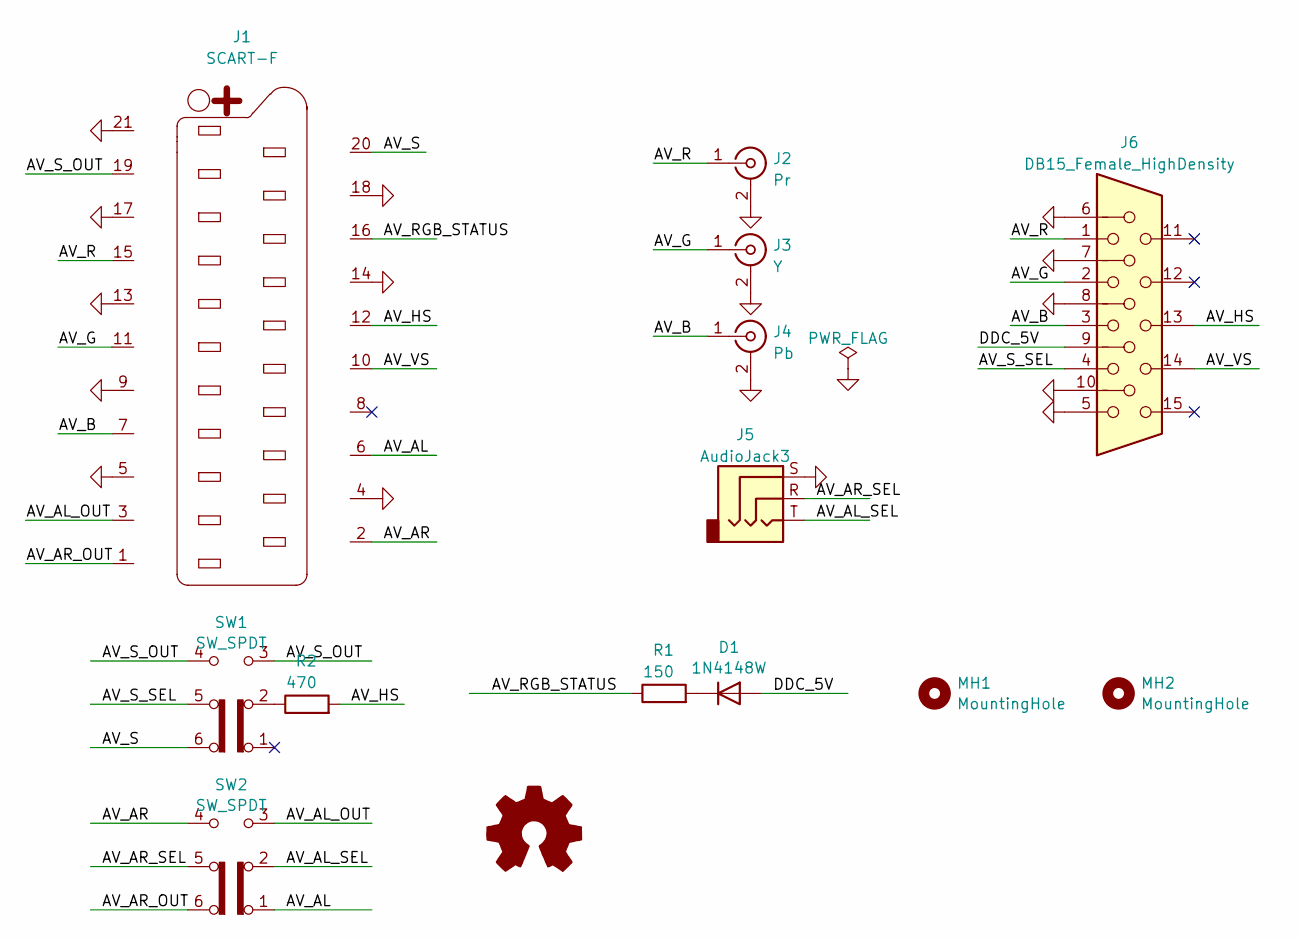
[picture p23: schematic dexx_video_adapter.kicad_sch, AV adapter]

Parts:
D1: 1N4148W; D_SOD-123
J1: SCART-F; SCART_CONN
J2: Pr; CUI_RCJ-022
J3: Y; CUI_RCJ-022
J4: Pb; CUI_RCJ-022
J5: AudioJack3; Jack_3.5mm_CUI_SJ1-3533NG_Horizontal
J6: DB15_Female_HighDensity; VGA_CONN
MH1, MH2: MountingHole; MountingHole_3.2mm_M3_ISO14580_Pad
R1: 150; SM0603_Resistor_libcms
R2: 470; SM0603_Resistor_libcms
SW1, SW2: SW_SPDT; SW6_OS202011MA0QS1_CNK
SYM1: Logo_Open_Hardware_Small; WEEE-Logo_4.2x6mm_SilkScreen

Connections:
/AV_AL: J1.6, SW2.1 (A)
/AV_AL_OUT: J1.3, SW2.3 (C)
/AV_AL_SEL: J5.T, SW2.2 (B)
/AV_AR: J1.2, SW2.4 (A)
/AV_AR_OUT: J1.1, SW2.6 (C)
/AV_AR_SEL: J5.R, SW2.5 (B)
/AV_B: J1.7, J4.1 (In), J6.3
/AV_G: J1.11, J3.1 (In), J6.2
/AV_HS: J1.12, J6.13, R2.2
/AV_R: J1.15, J2.1 (In), J6.1
/AV_RGB_STATUS: J1.16, R1.1
/AV_S: J1.20, SW1.6 (C)
/AV_S_OUT: J1.19, SW1.3 (C), SW1.4 (A)
/AV_S_SEL: J6.4, SW1.5 (B)
/AV_VS: J1.10, J6.14
/DDC_5V: D1.2 (A), J6.9
GND: J1.4, J1.5, J1.9, J1.13, J1.14, J1.17, J1.18, J1.21, J2.2 (Ext), J3.2 (Ext), J4.2 (Ext), J5.S, J6.5, J6.6, J6.7, J6.8, J6.10
unnamed: D1.1 (K), R1.2
unnamed: R2.1, SW1.2 (B)

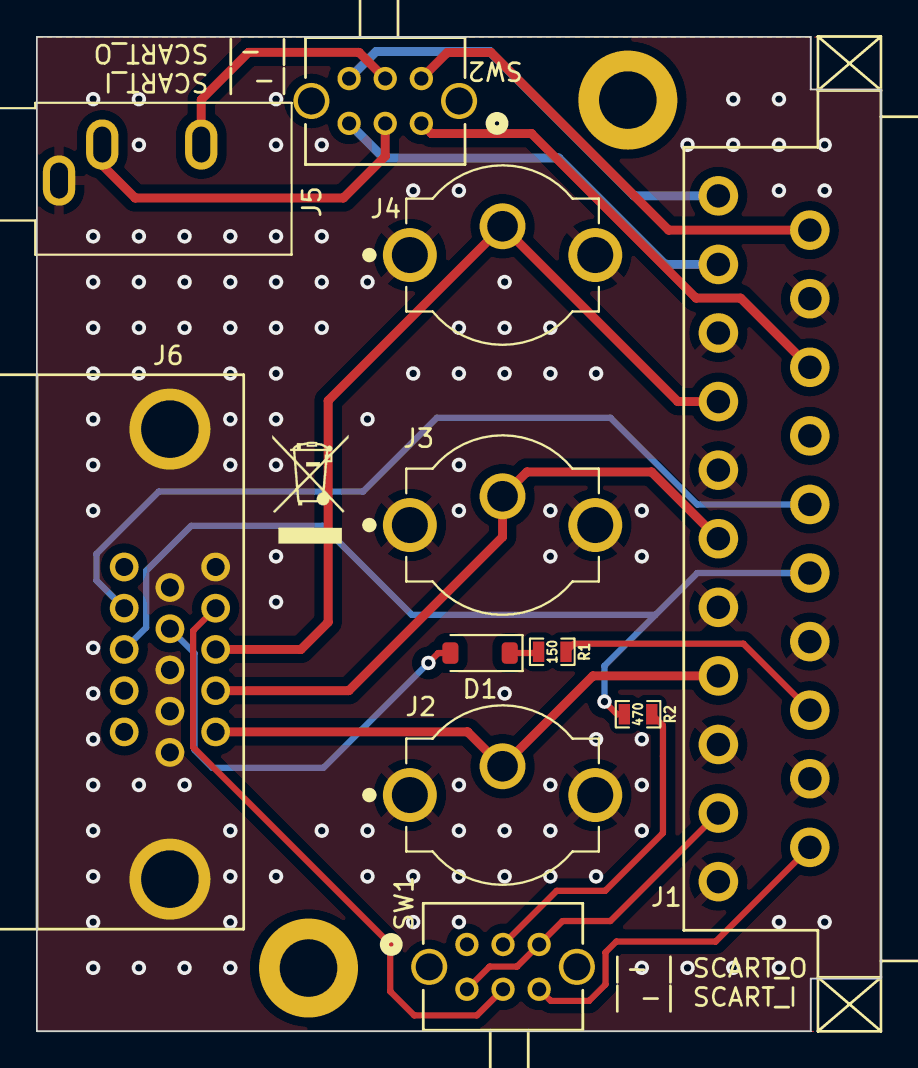
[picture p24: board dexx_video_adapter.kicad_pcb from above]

Board: 2 copper layers, 46.9 x 55.2 mm, 14 parts (0 on the bottom side), 19 nets.

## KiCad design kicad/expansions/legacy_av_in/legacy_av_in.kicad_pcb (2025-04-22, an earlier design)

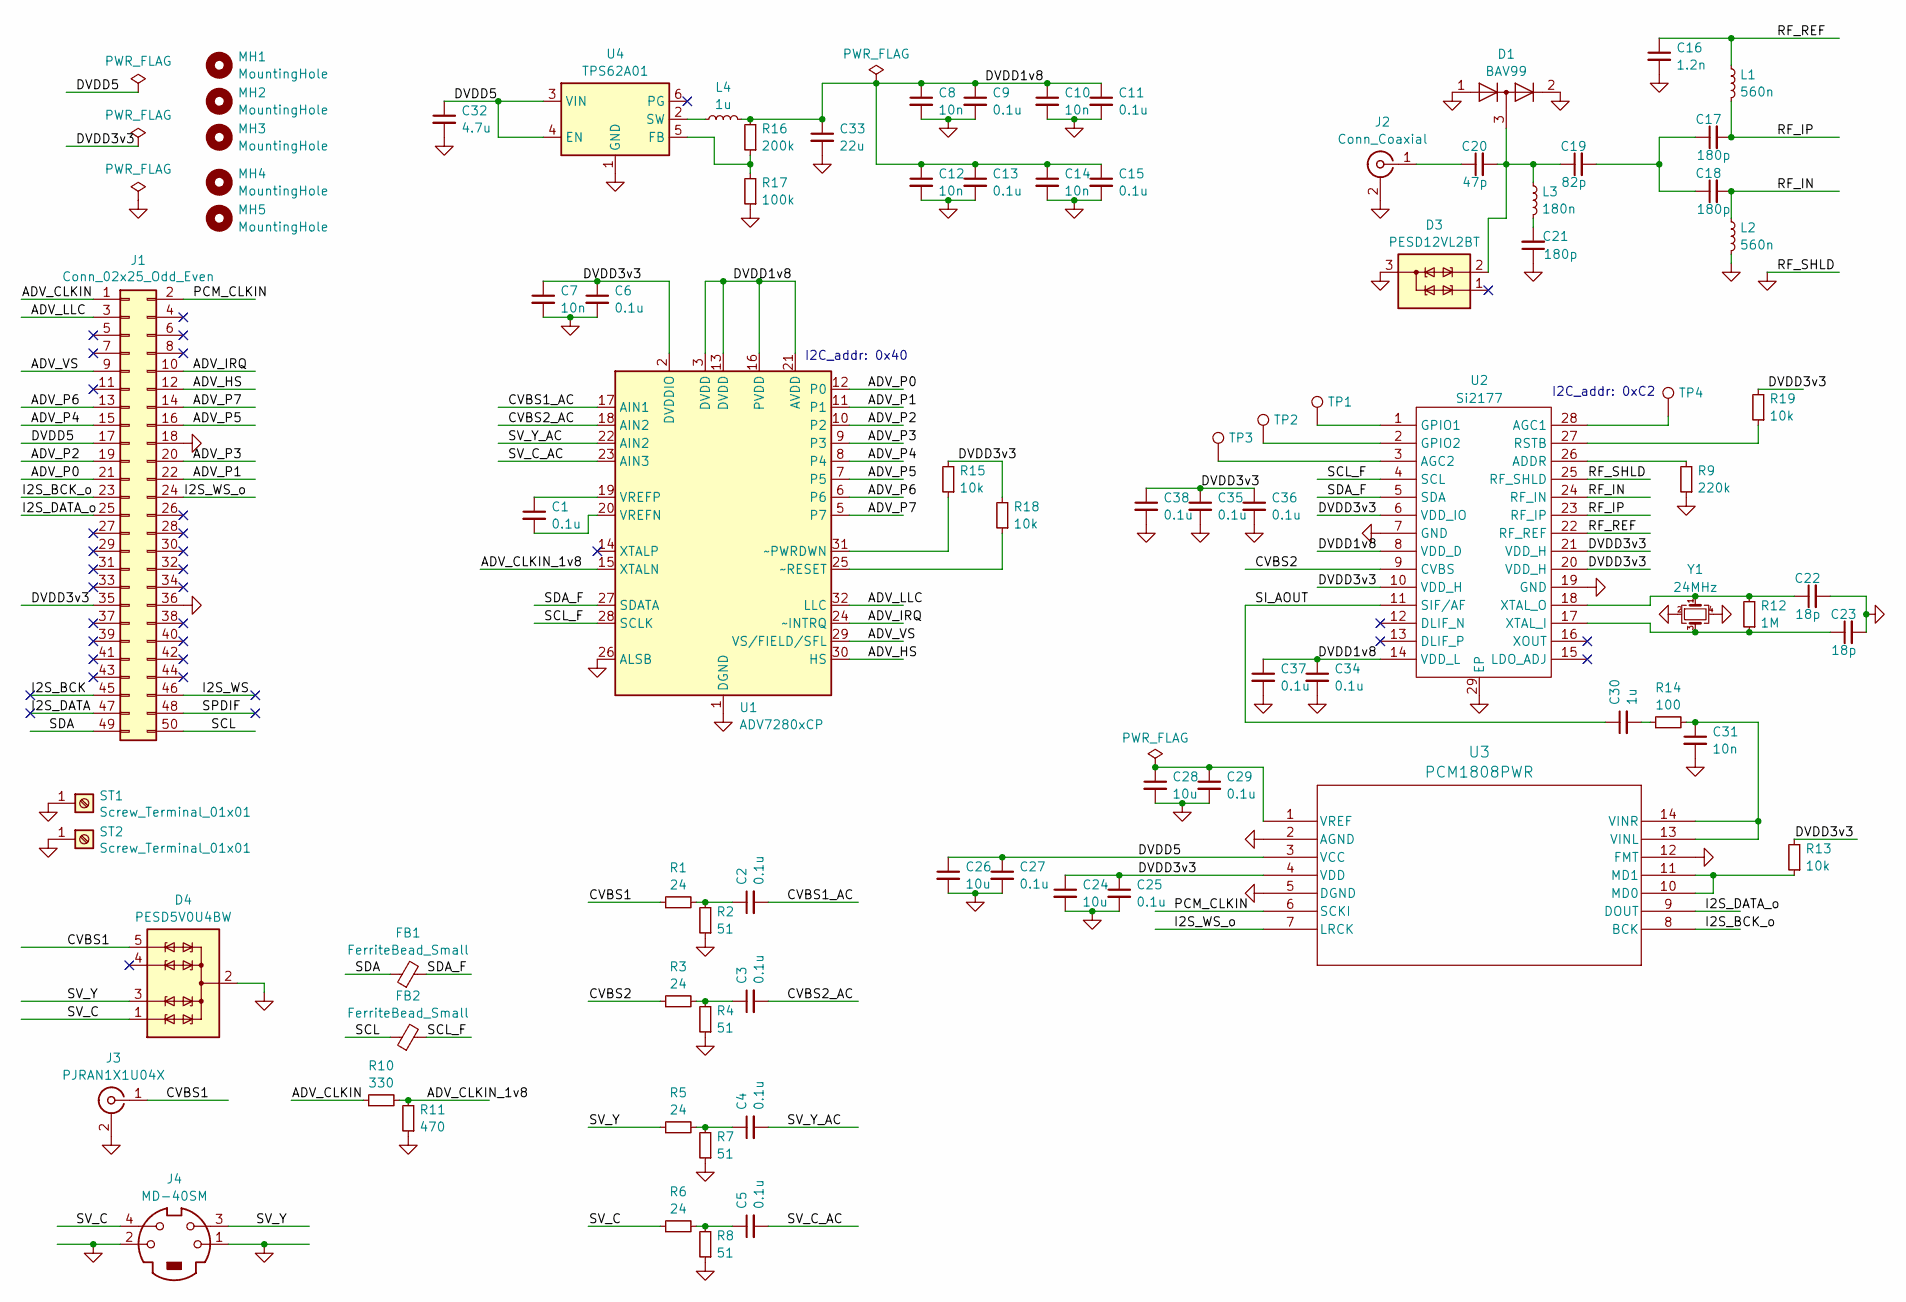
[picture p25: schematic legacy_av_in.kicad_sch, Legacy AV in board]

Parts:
C1, C6, C9, C11, C13, C15, C25, C27, C29, C34, C35, C36, C37, C38: 0.1u; C_0402_1005Metric_Pad0.74x0.62mm_HandSolder
C2, C3, C4, C5: 0.1u; SM0603_Capa_libcms
C7, C8, C10, C12, C14: 10n; C_0402_1005Metric_Pad0.74x0.62mm_HandSolder
C16: 1.2n; SM0603_Capa_libcms
C17, C18, C21: 180p; SM0603_Capa_libcms
C19: 82p; SM0603_Capa_libcms
C20: 47p; SM0603_Capa_libcms
C22, C23: 18p; C_0402_1005Metric_Pad0.74x0.62mm_HandSolder
C24, C26, C28: 10u; SM0603_Capa_libcms
C30: 1u; SM0603_Capa_libcms
C31: 10n; SM0603_Capa_libcms
C32: 4.7u; SM0603_Capa_libcms
C33: 22u; SM0603_Capa_libcms
D1: BAV99; SOT-23
D3: PESD12VL2BT; SOT-23
D4: PESD5V0U4BW; SOT-665
FB1, FB2: FerriteBead_Small; SM0603_Resistor_libcms
J1: Conn_02x25_Odd_Even; PinSocket_2x25_P2.54mm_Horizontal
J2: Conn_Coaxial; F_Molex_73330-0030_Horizontal
J3: PJRAN1X1U04X
J4: MD-40SM; CUI_MD-40SM
L1, L2: 560n; SM0603_Resistor_libcms
L3: 180n; SM0603_Resistor_libcms
L4: 1u; L_1008_2520Metric_Pad1.43x2.20mm_HandSolder
MH1, MH2, MH3: MountingHole; MountingHole_3.2mm_M3_ISO14580
MH4, MH5: MountingHole; MountingHole_3.2mm_M3_ISO14580_Pad
R1, R3, R5, R6: 24; SM0603_Resistor_libcms
R2, R4, R7, R8: 51; SM0603_Resistor_libcms
R9: 220k; SM0603_Resistor_libcms
R10: 330; SM0603_Resistor_libcms
R11: 470; SM0603_Resistor_libcms
R12: 1M; R_0402_1005Metric_Pad0.72x0.64mm_HandSolder
R13, R15, R18, R19: 10k; SM0603_Resistor_libcms
R14: 100; SM0603_Resistor_libcms
R16: 200k; R_0402_1005Metric_Pad0.72x0.64mm_HandSolder
R17: 100k; R_0402_1005Metric_Pad0.72x0.64mm_HandSolder
ST1, ST2: Screw_Terminal_01x01; 7773
TP1, TP2, TP3, TP4: TestPoint; TestPoint_Pad_1.0x1.0mm
U1: ADV7280xCP; LFCSP-32-1EP_5x5mm_P0.5mm_EP3.6x3.6mm_ThermalVias
U2: Si2177; QFN-28-1EP_4x4mm_Silabs
U3: PCM1808PWR; TSSOP-14_4.4x5mm_P0.65mm
U4: TPS62A01; SOT-563
Y1: 24MHz; Crystal_SMD_SeikoEpson_FA128-4Pin_2.0x1.6mm

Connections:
/ADV_CLKIN: J1.1, R10.1
/ADV_CLKIN_1v8: R10.2, R11.2, U1.15 (XTALN)
/ADV_HS: J1.12, U1.30 (HS)
/ADV_IRQ: J1.10, U1.24 (~INTRQ)
/ADV_LLC: J1.3, U1.32 (LLC)
/ADV_P0: J1.21, U1.12 (P0)
/ADV_P1: J1.22, U1.11 (P1)
/ADV_P2: J1.19, U1.10 (P2)
/ADV_P3: J1.20, U1.9 (P3)
/ADV_P4: J1.15, U1.8 (P4)
/ADV_P5: J1.16, U1.7 (P5)
/ADV_P6: J1.13, U1.6
/ADV_P7: J1.14, U1.5 (P7)
/ADV_VS: J1.9, U1.29 (VS/FIELD/SFL)
/CVBS1: D4.5 (TVS4), J3.1 (In), R1.1
/CVBS1_AC: C2.2, U1.17 (AIN1)
/CVBS2: R3.1, U2.9 (CVBS)
/CVBS2_AC: C3.2, U1.18 (AIN2)
/DVDD1v8: C8.1, C9.1, C10.1, C11.1, C12.1, C13.1, C14.1, C15.1, C33.1, C34.1, C37.1, L4.2, R16.2, U1.3 (DVDD), U1.13 (DVDD), U1.16 (PVDD), U1.21 (AVDD), U2.8 (VDD_D), U2.14 (VDD_L)
/DVDD3v3: C6.1, C7.1, C24.1, C25.1, C35.1, C36.1, C38.1, J1.35, R13.2, R15.2, R18.2, R19.2, U1.2 (DVDDIO), U2.6 (VDD_IO), U2.10 (VDD_H), U2.20 (VDD_H), U2.21 (VDD_H), U3.4 (VDD)
/DVDD5: C26.1, C27.1, C32.1, J1.17, U3.3 (VCC), U4.3 (VIN), U4.4 (EN)
/I2S_BCK: J1.45
/I2S_BCK_o: J1.23, U3.8 (BCK)
/I2S_DATA: J1.47
/I2S_DATA_o: J1.25, U3.9 (DOUT)
/I2S_WS: J1.46
/I2S_WS_o: J1.24, U3.7 (LRCK)
/PCM_CLKIN: J1.2, U3.6 (SCKI)
/RF_IN: C18.2, L2.1, U2.24 (RF_IN)
/RF_IP: C17.2, L1.2, U2.23 (RF_IP)
/RF_REF: C16.1, L1.1, U2.22 (RF_REF)
/SCL: FB2.1, J1.50
/SCL_F: FB2.2, U1.28 (SCLK), U2.4 (SCL)
/SDA: FB1.1, J1.49
/SDA_F: FB1.2, U1.27 (SDATA), U2.5 (SDA)
/SI_AOUT: C30.1, U2.11 (SIF/AF)
/SPDIF: J1.48
/SV_C: D4.1 (TVS1), J4.4, R6.1
/SV_C_AC: C5.2, U1.23 (AIN3)
/SV_Y: D4.3 (TVS2), J4.3, R5.1
/SV_Y_AC: C4.2, U1.22 (AIN2)
GND: C6.2, C7.2, C8.2, C9.2, C10.2, C11.2, C12.2, C13.2, C14.2, C15.2, C16.2, C21.1, C22.2, C23.2, C24.2, C25.2, C26.2, C27.2, C28.2, C29.2, C31.2, C32.2, C33.2, C34.2, C35.2, C36.2, C37.2, C38.2, D1.1 (K), D1.2 (A), D3.3 (COM), D4.2 (COM), J1.18, J1.36, J2.2 (Ext), J3.2 (Ext), J4.1, J4.2, L2.2, R2.1, R4.1, R7.1, R8.1, R9.1, R11.1, R17.1, ST1.1, ST2.1, U1.1 (DGND), U1.4 (DGND), U1.26 (ALSB), U1.33 (DGND), U2.7 (GND), U2.19 (GND), U2.25 (RF_SHLD), U2.29 (EP), U3.2 (AGND), U3.5 (DGND), U3.12 (FMT), U4.1 (GND), Y1.2, Y1.4
unnamed: C2.1, R1.2, R2.2
unnamed: C3.1, R3.2, R4.2
unnamed: C4.1, R5.2, R7.2
unnamed: C5.1, R6.2, R8.2
unnamed: C17.1, C18.1, C19.2
unnamed: C21.2, L3.2
unnamed: C30.2, R14.1
unnamed: C19.1, C20.2, D1.3 (K), D3.2 (TVS2), L3.1
unnamed: C20.1, J2.1 (In)
unnamed: C1.2, U1.20 (VREFN)
unnamed: C1.1, U1.19 (VREFP)
unnamed: R15.1, U1.31 (~PWRDWN)
unnamed: R18.1, U1.25 (~RESET)
unnamed: R9.2, U2.26 (ADDR)
unnamed: TP4.1, U2.28 (AGC1)
unnamed: TP3.1, U2.3 (AGC2)
unnamed: TP1.1, U2.1 (GPIO1)
unnamed: TP2.1, U2.2 (GPIO2)
unnamed: R19.1, U2.27 (RSTB)
unnamed: C23.1, R12.1, U2.17 (XTAL_I), Y1.3
unnamed: C22.1, R12.2, U2.18 (XTAL_O), Y1.1
unnamed: R13.1, U3.10 (MD0), U3.11 (MD1)
unnamed: C31.1, R14.2, U3.13 (VINL), U3.14 (VINR)
unnamed: C28.1, C29.1, U3.1 (VREF)
unnamed: R16.1, R17.2, U4.5 (FB)
unnamed: L4.1, U4.2 (SW)

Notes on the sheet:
I2C_addr: 0x40
I2C_addr: 0xC2

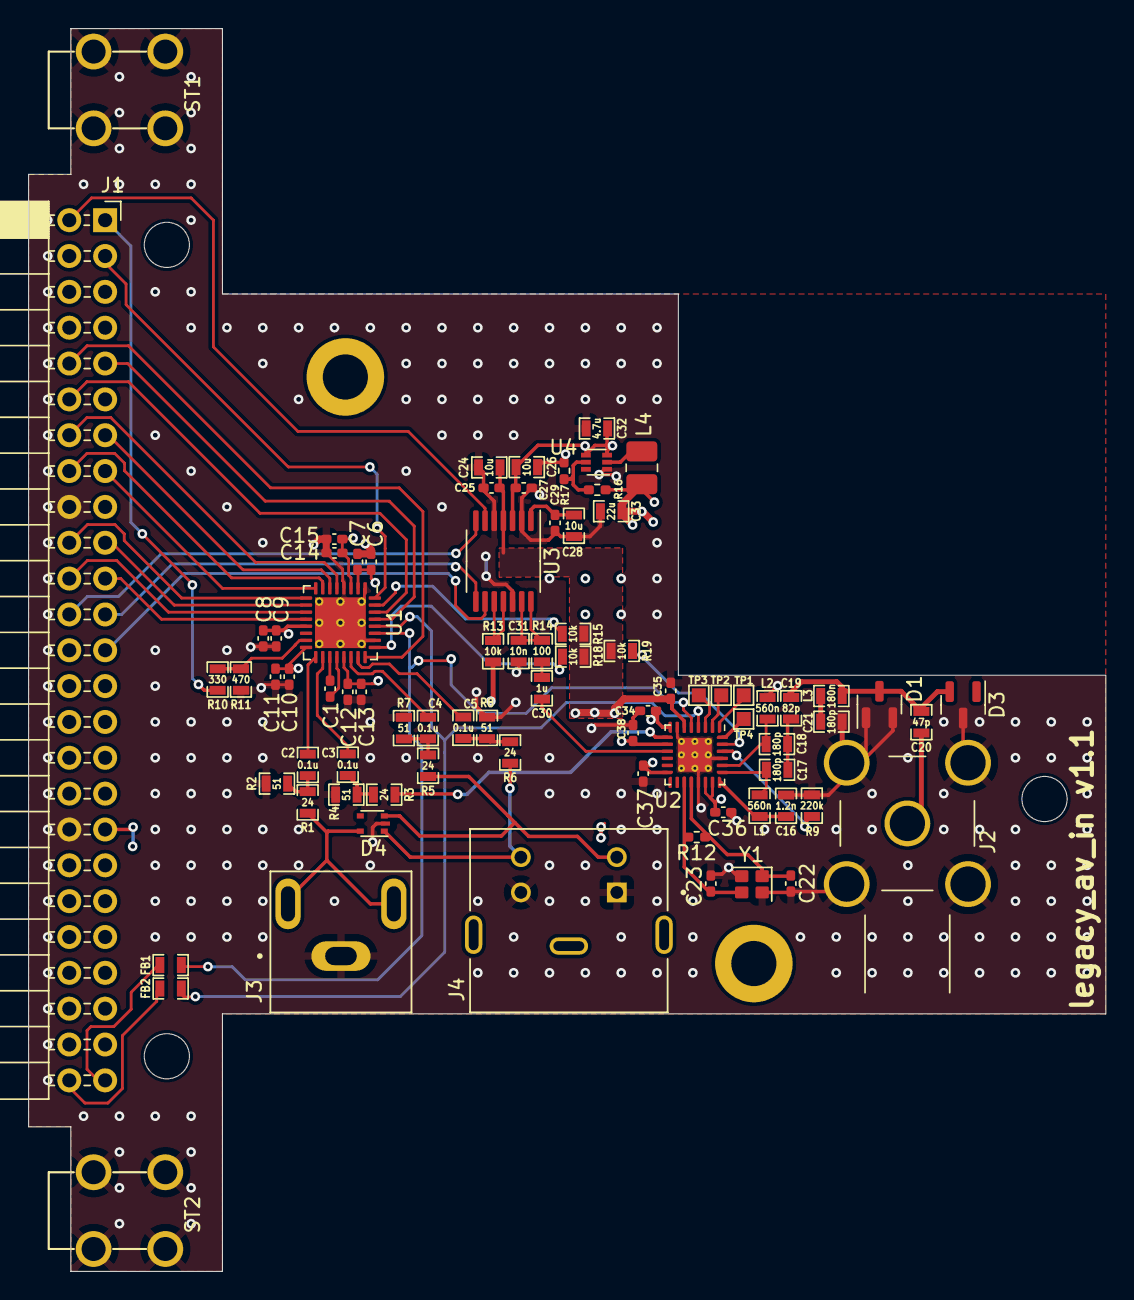
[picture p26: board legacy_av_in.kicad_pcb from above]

Board: 4 copper layers, 76.3 x 88.1 mm, 86 parts (0 on the bottom side), 64 nets.

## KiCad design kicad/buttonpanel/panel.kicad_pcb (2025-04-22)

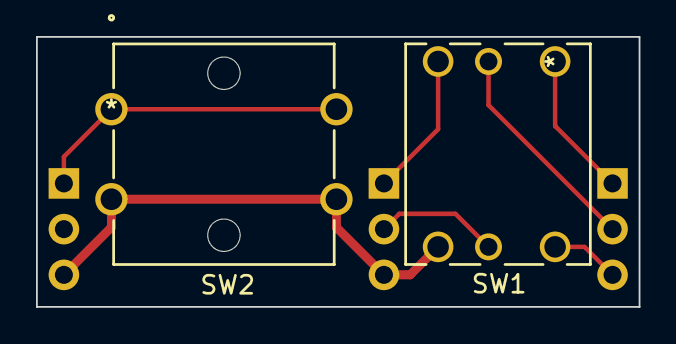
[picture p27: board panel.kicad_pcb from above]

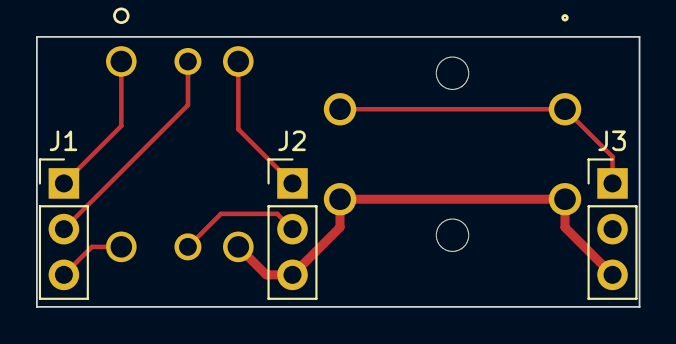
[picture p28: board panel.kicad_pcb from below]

Board: 2 copper layers, 33.5 x 15.0 mm, 5 parts (3 on the bottom side), 7 nets.

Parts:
J1, J2, J3: TSW-101-08-T-T-RA; PinHeader_1x03_P2.54mm_Vertical
SW1: SKQUCAA010
SW2: B3F-4050

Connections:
/J_COM: J2.3, J3.3, SW1.4, SW2.3, SW2.4
/J_DOWN: J2.2, SW1.5
/J_LEFT: J2.1, SW1.3
/J_PUSH: J1.3, SW1.6
/J_RIGHT: J1.1, SW1.1
/J_UP: J1.2, SW1.2
/SW: J3.1, SW2.1, SW2.2

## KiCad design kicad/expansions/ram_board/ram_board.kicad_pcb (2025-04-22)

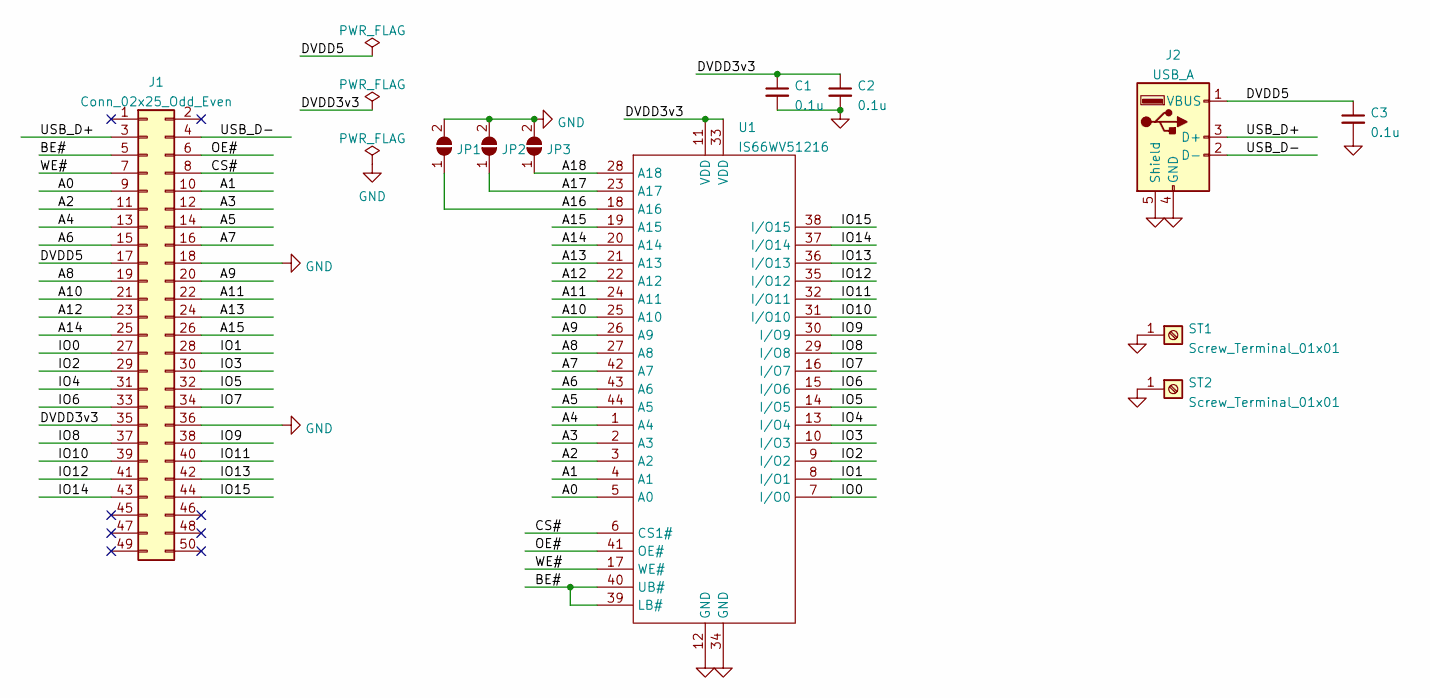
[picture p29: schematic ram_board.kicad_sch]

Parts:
C1, C2, C3: 0.1u; C_0603_1608Metric_Pad1.08x0.95mm_HandSolder
J1: Conn_02x25_Odd_Even; PinSocket_2x25_P2.54mm_Horizontal
J2: USB_A; USB_A_Molex_067329-8000
JP1, JP2, JP3: SolderJumper_2_Open; SolderJumper-2_P1.3mm_Open_Pad1.0x1.5mm
ST1, ST2: Screw_Terminal_01x01; 7773
U1: IS66WV51216; TSOP-II-44_10.16x18.41mm_P0.8mm

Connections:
/A0: J1.9, U1.5 (A0)
/A1: J1.10, U1.4 (A1)
/A2: J1.11, U1.3 (A2)
/A3: J1.12, U1.2 (A3)
/A4: J1.13, U1.1 (A4)
/A5: J1.14, U1.44 (A5)
/A6: J1.15, U1.43 (A6)
/A7: J1.16, U1.42 (A7)
/A8: J1.19, U1.27 (A8)
/A9: J1.20, U1.26 (A9)
/A10: J1.21, U1.25 (A10)
/A11: J1.22, U1.24 (A11)
/A12: J1.23, U1.22 (A12)
/A13: J1.24, U1.21 (A13)
/A14: J1.25, U1.20 (A14)
/A15: J1.26, U1.19 (A15)
/A16: JP1.1 (A), U1.18 (A16)
/A17: JP2.1 (A), U1.23 (A17)
/A18: JP3.1 (A), U1.28 (A18)
/BE#: J1.5, U1.39 (LB#), U1.40 (UB#)
/CS#: J1.8, U1.6 (CS1#)
/DVDD3v3: C1.1, C2.1, J1.35, U1.11 (VDD), U1.33 (VDD)
/DVDD5: C3.1, J1.17, J2.1 (VBUS)
/IO0: J1.27, U1.7 (I/O0)
/IO1: J1.28, U1.8 (I/O1)
/IO2: J1.29, U1.9 (I/O2)
/IO3: J1.30, U1.10 (I/O3)
/IO4: J1.31, U1.13 (I/O4)
/IO5: J1.32, U1.14 (I/O5)
/IO6: J1.33, U1.15 (I/O6)
/IO7: J1.34, U1.16 (I/O7)
/IO8: J1.37, U1.29 (I/O8)
/IO9: J1.38, U1.30 (I/O9)
/IO10: J1.39, U1.31 (I/O10)
/IO11: J1.40, U1.32 (I/O11)
/IO12: J1.41, U1.35 (I/O12)
/IO13: J1.42, U1.36 (I/O13)
/IO14: J1.43, U1.37 (I/O14)
/IO15: J1.44, U1.38 (I/O15)
/OE#: J1.6, U1.41 (OE#)
/USB_D+: J1.3, J2.3 (D+)
/USB_D-: J1.4, J2.2 (D-)
/WE#: J1.7, U1.17 (WE#)
GND: C1.2, C2.2, C3.2, J1.18, J1.36, J2.4 (GND), J2.5 (Shield), JP1.2 (B), JP2.2 (B), JP3.2 (B), ST1.1, ST2.1, U1.12 (GND), U1.34 (GND)

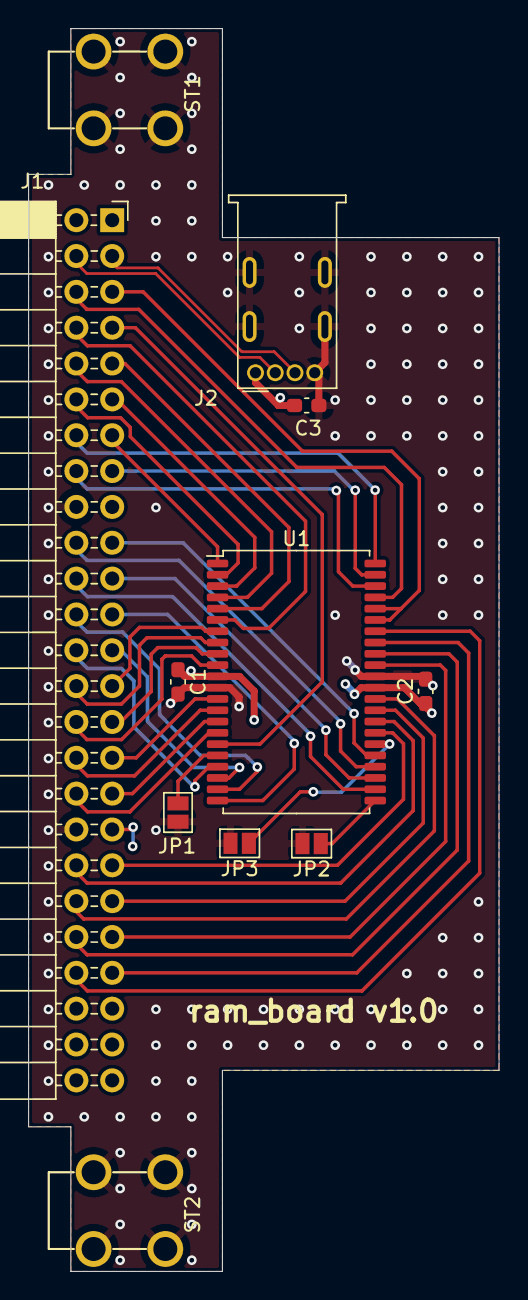
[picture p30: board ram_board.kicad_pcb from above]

Board: 4 copper layers, 33.3 x 88.1 mm, 11 parts (0 on the bottom side), 44 nets.

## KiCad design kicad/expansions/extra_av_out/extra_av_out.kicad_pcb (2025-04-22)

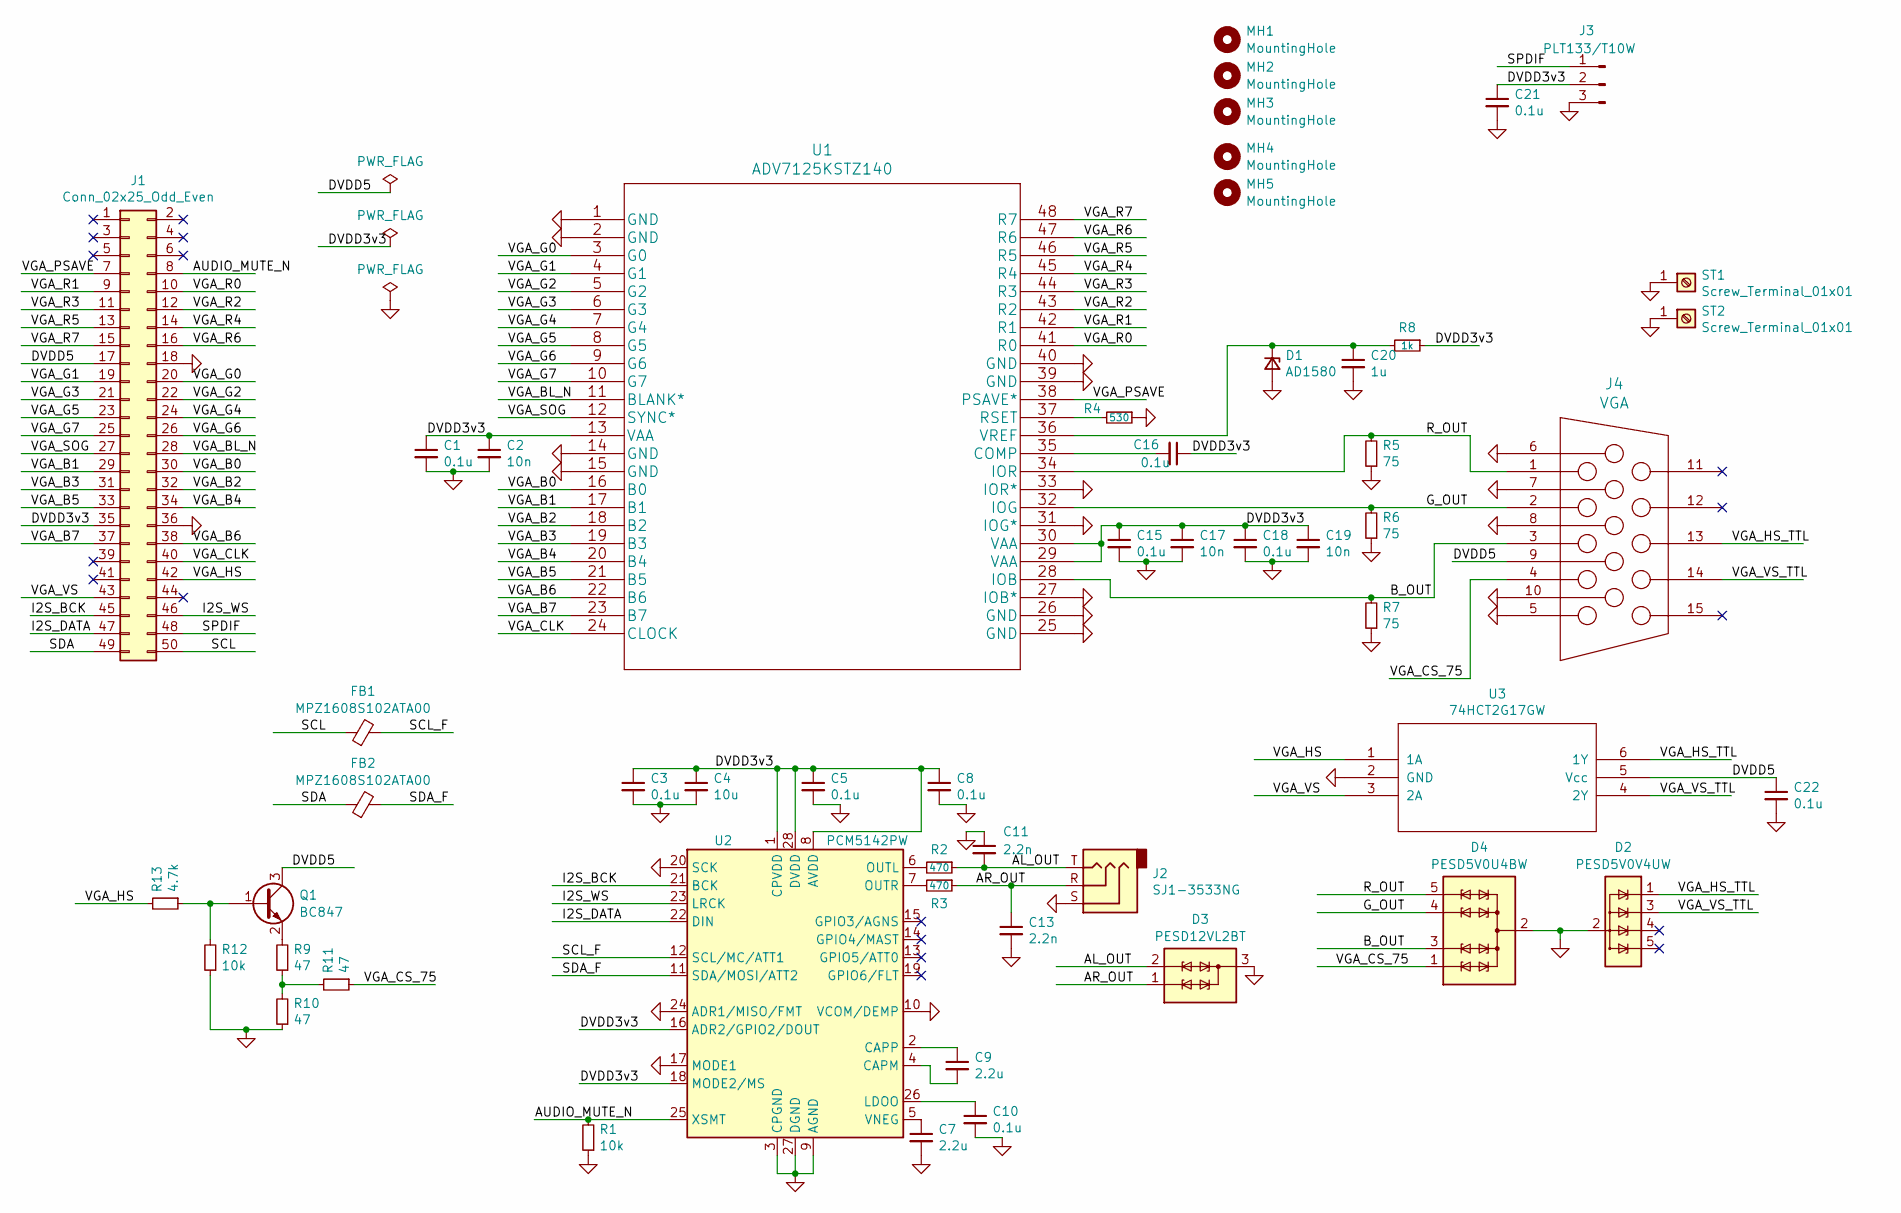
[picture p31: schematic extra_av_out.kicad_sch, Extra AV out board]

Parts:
C1, C3, C5, C8, C10, C15, C16, C18, C21, C22: 0.1u; SM0603_Capa_libcms
C2, C17, C19: 10n; SM0603_Capa_libcms
C4: 10u; SM0603_Capa_libcms
C7, C9: 2.2u; SM0603_Capa_libcms
C11, C13: 2.2n; SM0603_Capa_libcms
C20: 1u; SM0603_Capa_libcms
D1: AD1580; SOT-23_Handsoldering
D2: PESD5V0V4UW; SOT-665
D3: PESD12VL2BT; SOT-23
D4: PESD5V0U4BW; SOT-665
FB1, FB2: MPZ1608S102ATA00; SM0603_Resistor_libcms
J1: Conn_02x25_Odd_Even; PinSocket_2x25_P2.54mm_Horizontal
J2: SJ1-3533NG; Jack_3.5mm_CUI_SJ1-3533NG_Horizontal
J3: PLT133/T10W; PLT133
J4: VGA; VGA_CONN
MH1, MH2, MH3: MountingHole; MountingHole_3.2mm_M3_ISO14580
MH4, MH5: MountingHole; MountingHole_3.2mm_M3_ISO14580_Pad
Q1: BC847; SOT-23
R1, R12: 10k; SM0603_Resistor_libcms
R2, R3: 470; SM0603_Resistor_libcms
R4: 530; SM0603_Resistor_libcms
R5, R6, R7: 75; SM0603_Resistor_libcms
R8: 1k; SM0603_Resistor_libcms
R9, R10, R11: 47; SM0603_Resistor_libcms
R13: 4.7k; SM0603_Resistor_libcms
ST1, ST2: Screw_Terminal_01x01; 7773
U1: ADV7125KSTZ140; LQFP-48_7x7mm_P0.5mm
U2: PCM5142PW; TSSOP-28_4.4x9.7mm_P0.65mm
U3: 74HCT2G17GW; TSOP-6_1.65x3.05mm_P0.95mm

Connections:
/AL_OUT: C11.2, D3.2 (TVS2), J2.T, R2.1
/AR_OUT: C13.1, D3.1 (TVS1), J2.R, R3.1
/AUDIO_MUTE_N: J1.8, R1.2, U2.25 (XSMT)
/B_OUT: D4.3 (TVS2), J4.3 (BLUE), R7.2, U1.28 (IOB)
/DVDD3v3: C1.1, C2.1, C3.1, C4.1, C5.1, C8.1, C15.1, C16.1, C17.1, C18.1, C19.1, C21.1, J1.35, J3.2, R8.1, U1.13 (VAA), U1.29 (VAA), U1.30 (VAA), U2.1 (CPVDD), U2.8 (AVDD), U2.16 (ADR2/GPIO2/DOUT), U2.18 (MODE2/MS), U2.28 (DVDD)
/DVDD5: C22.1, J1.17, J4.9 (KEY/PWR), Q1.3 (C), U3.5 (Vcc)
/G_OUT: D4.4 (TVS3), J4.2 (GREEN), R6.2, U1.32 (IOG)
/I2S_BCK: J1.45, U2.21 (BCK)
/I2S_DATA: J1.47, U2.22 (DIN)
/I2S_WS: J1.46, U2.23 (LRCK)
/R_OUT: D4.5 (TVS4), J4.1 (RED), R5.2, U1.34 (IOR)
/SCL: FB1.1, J1.50
/SCL_F: FB1.2, U2.12 (SCL/MC/ATT1)
/SDA: FB2.1, J1.49
/SDA_F: FB2.2, U2.11 (SDA/MOSI/ATT2)
/SPDIF: J1.48, J3.1
/VGA_B0: J1.30, U1.16 (B0)
/VGA_B1: J1.29, U1.17 (B1)
/VGA_B2: J1.32, U1.18 (B2)
/VGA_B3: J1.31, U1.19 (B3)
/VGA_B4: J1.34, U1.20 (B4)
/VGA_B5: J1.33, U1.21 (B5)
/VGA_B6: J1.38, U1.22 (B6)
/VGA_B7: J1.37, U1.23 (B7)
/VGA_BL_N: J1.28, U1.11 (BLANK*)
/VGA_CLK: J1.40, U1.24 (CLOCK)
/VGA_CS_75: D4.1 (TVS1), J4.4 (ID2/RES), R11.1
/VGA_G0: J1.20, U1.3 (G0)
/VGA_G1: J1.19, U1.4 (G1)
/VGA_G2: J1.22, U1.5 (G2)
/VGA_G3: J1.21, U1.6 (G3)
/VGA_G4: J1.24, U1.7 (G4)
/VGA_G5: J1.23, U1.8 (G5)
/VGA_G6: J1.26, U1.9 (G6)
/VGA_G7: J1.25, U1.10 (G7)
/VGA_HS: J1.42, R13.2, U3.1 (1A)
/VGA_HS_TTL: D2.1 (IO1), J4.13 (HSYNC), U3.6 (1Y)
/VGA_PSAVE: J1.7, U1.38 (PSAVE*)
/VGA_R0: J1.10, U1.41 (R0)
/VGA_R1: J1.9, U1.42 (R1)
/VGA_R2: J1.12, U1.43 (R2)
/VGA_R3: J1.11, U1.44 (R3)
/VGA_R4: J1.14, U1.45 (R4)
/VGA_R5: J1.13, U1.46 (R5)
/VGA_R6: J1.16, U1.47 (R6)
/VGA_R7: J1.15, U1.48 (R7)
/VGA_SOG: J1.27, U1.12 (SYNC*)
/VGA_VS: J1.43, U3.3 (2A)
/VGA_VS_TTL: D2.3 (IO2), J4.14 (VSYNC), U3.4 (2Y)
GND: C1.2, C2.2, C3.2, C4.2, C5.2, C7.2, C8.2, C10.2, C11.1, C13.2, C15.2, C17.2, C18.2, C19.2, C20.2, C21.2, C22.2, D1.2 (A), D2.2 (GND), D3.3 (COM), D4.2 (COM), J1.18, J1.36, J2.S, J3.3, J4.5 (GND_HSYNC), J4.6 (RED_RTN), J4.7 (GREEN_RTN), J4.8 (BLUE_RTN), J4.10 (GND_VSYNC), R1.1, R4.1, R5.1, R6.1, R7.1, R10.1, R12.1, ST1.1, ST2.1, U1.1 (GND), U1.2 (GND), U1.14 (GND), U1.15 (GND), U1.25 (GND), U1.26 (GND), U1.27 (IOB*), U1.31 (IOG*), U1.33 (IOR*), U1.39 (GND), U1.40 (GND), U2.3 (CPGND), U2.9 (AGND), U2.10 (VCOM/DEMP), U2.17 (MODE1), U2.20 (SCK), U2.24 (ADR1/MISO/FMT), U2.27 (DGND), U3.2 (GND)
unnamed: C20.1, D1.1 (K), R8.2, U1.36 (VREF)
unnamed: Q1.1 (B), R12.2, R13.1
unnamed: Q1.2 (E), R9.2
unnamed: R9.1, R10.2, R11.2
unnamed: C16.2, U1.35 (COMP)
unnamed: R4.2, U1.37 (RSET)
unnamed: C9.2, U2.4 (CAPM)
unnamed: C9.1, U2.2 (CAPP)
unnamed: C10.1, U2.26 (LDOO)
unnamed: R2.2, U2.6 (OUTL)
unnamed: R3.2, U2.7 (OUTR)
unnamed: C7.1, U2.5 (VNEG)

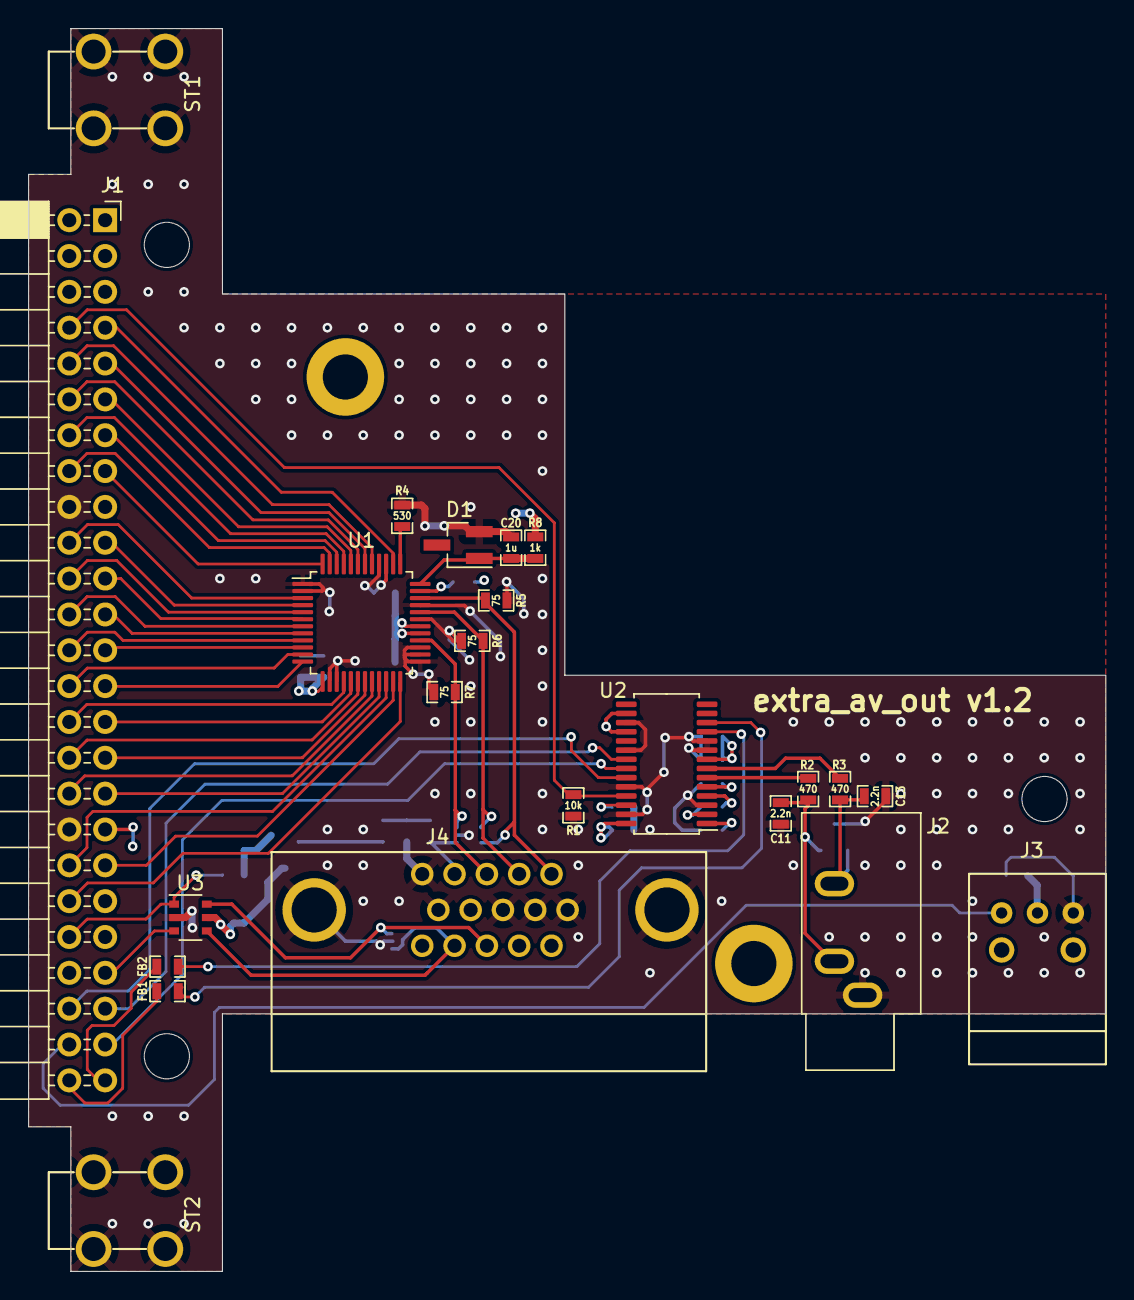
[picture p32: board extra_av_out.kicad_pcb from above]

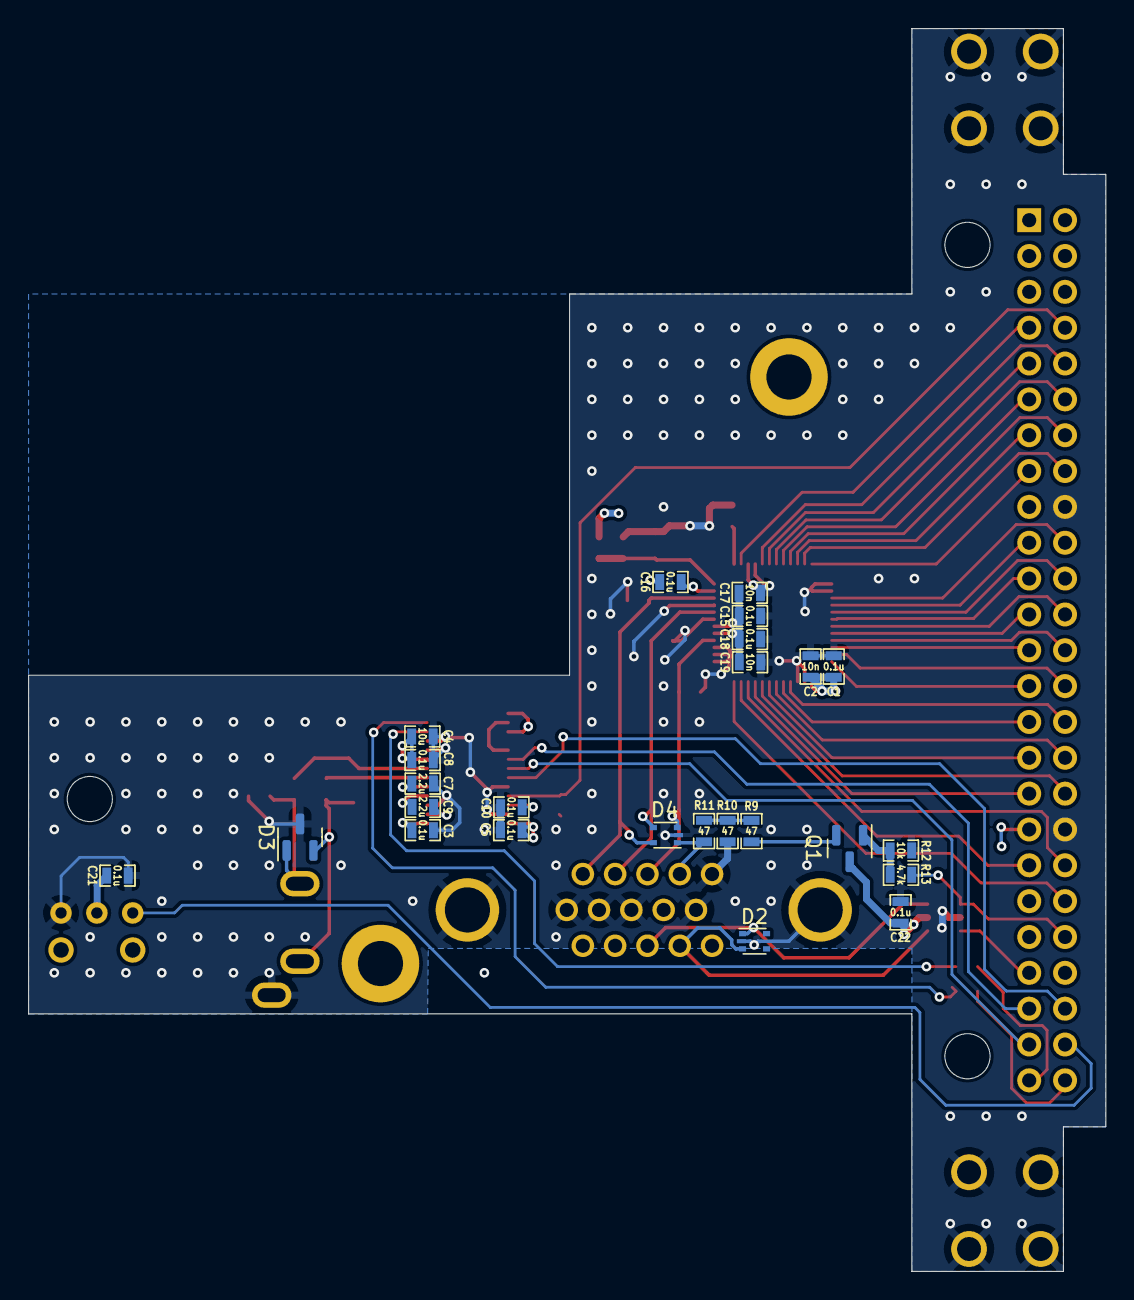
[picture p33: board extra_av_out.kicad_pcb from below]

Board: 4 copper layers, 76.3 x 88.1 mm, 53 parts (25 on the bottom side), 62 nets.

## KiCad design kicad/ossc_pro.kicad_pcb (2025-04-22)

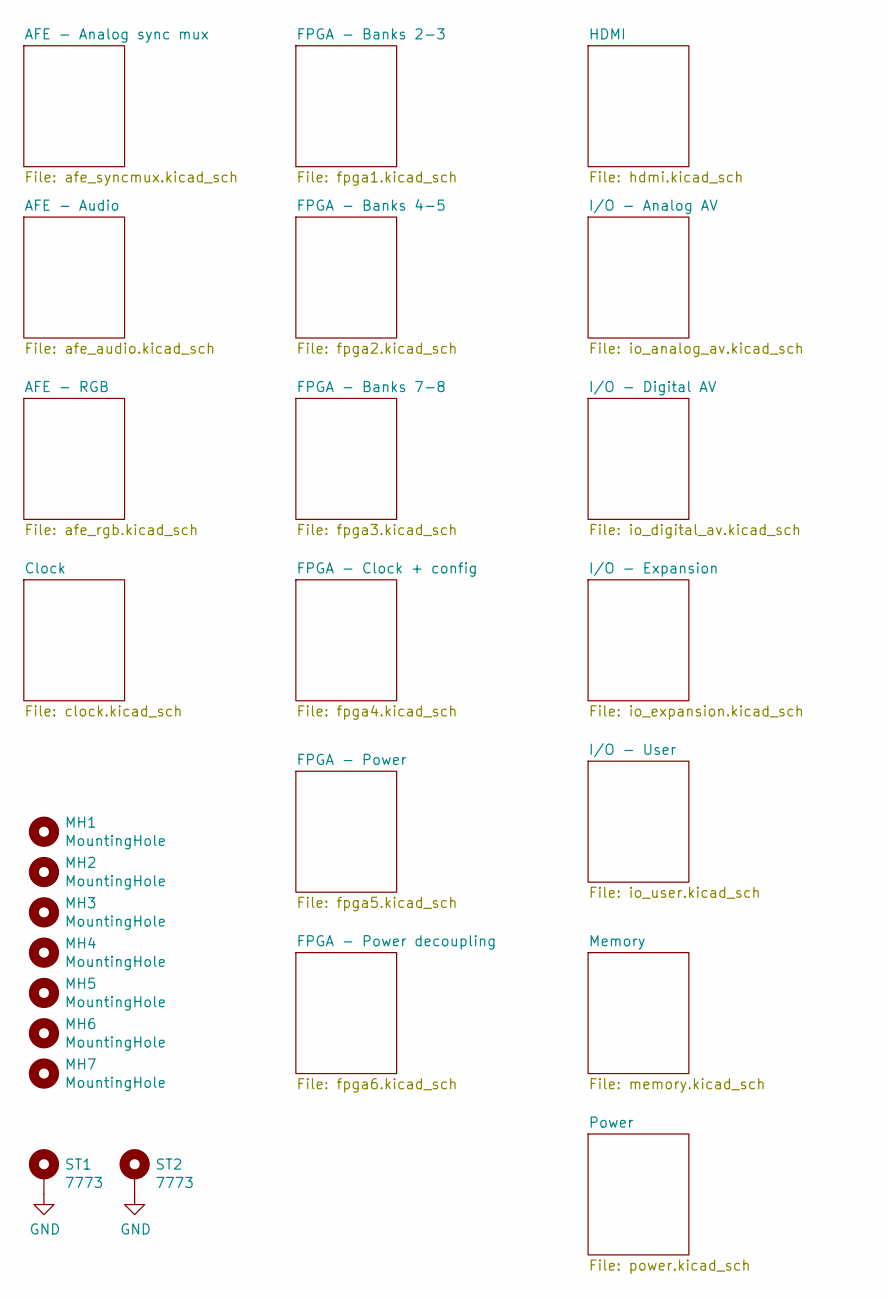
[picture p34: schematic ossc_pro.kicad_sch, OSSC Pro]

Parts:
MH1, MH2, MH3, MH4, MH5, MH6, MH7: MountingHole; MountingHole_3.2mm_M3_ISO14580
ST1, ST2: 7773

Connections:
GND: ST1.1, ST2.1; also elsewhere on the board

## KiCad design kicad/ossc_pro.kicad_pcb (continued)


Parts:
C13, C300, C305: 10n; C_0402_1005Metric
C301, C302, C303, C304, C315, C316: 0.1u; C_0402_1005Metric
C306: 47u; C_0805_2012Metric
C307, C308: 22p; C_0402_1005Metric
R10, R110, R113, R114: 75; R_0603_1608Metric
R111, R112: 500; R_0402_1005Metric
R115, R116: 100; R_0402_1005Metric
U22: THS7353; TSSOP-20_4.4x6.5mm_P0.65mm

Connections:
AV1_G: C303.2; also elsewhere on the board
AV1_S: C301.2, R10.1; also elsewhere on the board
AV1_S_AC: C13.1; also elsewhere on the board
AV3_G: C304.2; also elsewhere on the board
AV3_S: C302.2, R110.1; also elsewhere on the board
AV3_S_AC: C300.1; also elsewhere on the board
AVCC3v3: C305.2, C306.2, U22.11 (VCC); also elsewhere on the board
GND: C305.1, C306.1, C307.1, C308.1, R10.2, R110.2, R113.2, R114.2, U22.8 (I2C_ADR1), U22.9 (I2C_ADR0), U22.10 (GND); also elsewhere on the board
unnamed: C303.1, R111.2
unnamed: C304.1, R112.2
unnamed: C315.2, R113.1
unnamed: C316.2, R114.1
unnamed: C13.2, U22.18 (CH1_GA), U22.19 (OUT_CH1)
unnamed: U22.16 (CH2_GA), U22.17 (OUT_CH2)
unnamed: C300.2, U22.14 (CH3_GA), U22.15 (OUT_CH3)
unnamed: C301.1, U22.2 (IN_A_CH1)
unnamed: C315.1, U22.3 (IN_A_CH2)
unnamed: C302.1, U22.4 (IN_A_CH3)
unnamed: R111.1, U22.5 (IN_B_CH1)
unnamed: C316.1, U22.6 (IN_B_CH2)
unnamed: R112.1, U22.7 (IN_B_CH3)
unnamed: C308.2, R116.2, U22.13 (SCL)
unnamed: C307.2, R115.2, U22.12 (SDA)
SCL: R116.1; also elsewhere on the board
SDA: R115.1; also elsewhere on the board

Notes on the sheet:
AVCC3v3: max. 25mA
I2C_addr: 0x58


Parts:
C45, C46, C47, C48, C49, C50, C53, C56: 10u; C_0603_1608Metric
C51, C54: 2.2u; C_0603_1608Metric
C52, C55: 0.1u; C_0402_1005Metric
C318, C319, C320, C321, C322, C323: 10n; C_0402_1005Metric
R31, R32, R33, R34, R35, R36: 100k; R_0402_1005Metric
R129, R130, R131, R132, R133, R134: 100; R_0402_1005Metric
U7: PCM1863; TSSOP-30_4.4x7.8mm_P0.5mm

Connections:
/AFE - Audio/AV1_AL_AC: C318.2, R129.1, U7.3 (VINL1)
/AFE - Audio/AV1_AR_AC: C319.2, R130.1, U7.4 (VINR1)
/AFE - Audio/AV2_AL_AC: C320.2, R131.1, U7.1 (VINL2)
/AFE - Audio/AV2_AR_AC: C321.2, R132.1, U7.2 (VINR2)
/AFE - Audio/AV3_AL_AC: C322.2, R133.1, U7.29 (VINL3)
/AFE - Audio/AV3_AR_AC: C323.2, R134.1, U7.30 (VINR3)
AV1_AL: C45.2, R31.1; also elsewhere on the board
AV1_AR: C46.2, R32.1; also elsewhere on the board
AV2_AL: C47.2, R33.1; also elsewhere on the board
AV2_AR: C48.2, R34.1; also elsewhere on the board
AV3_AL: C49.2, R35.1; also elsewhere on the board
AV3_AR: C50.2, R36.1; also elsewhere on the board
AVCC3v3: C52.2, C53.2, U7.8 (AVDD); also elsewhere on the board
CLK27: U7.15 (SCKI); also elsewhere on the board
DVDD3v3: C55.2, C56.2, U7.13 (DVDD), U7.14 (IOVDD); also elsewhere on the board
GND: C51.2, C52.1, C53.1, C54.2, C55.1, C56.1, C318.1, C319.1, C320.1, C321.1, C322.1, C323.1, R31.2, R32.2, R33.2, R34.2, R35.2, R36.2, U7.7 (AGND), U7.12 (DGND), U7.25 (MS/AD), U7.26 (MD0); also elsewhere on the board
unnamed: C45.1, R129.2
unnamed: C46.1, R130.2
unnamed: C47.1, R131.2
unnamed: C48.1, R132.2
unnamed: C49.1, R133.2
unnamed: C50.1, R134.2
unnamed: C54.1, U7.11 (LDO)
unnamed: C51.1, U7.6 (VREF)
PCM_I2S_BCK: U7.17 (BCK); also elsewhere on the board
PCM_I2S_DATA: U7.18 (DOUT); also elsewhere on the board
PCM_I2S_WS: U7.16 (LRCK); also elsewhere on the board
SCL: U7.24 (MC/SCL); also elsewhere on the board
SDA: U7.23 (MOSI/SDA); also elsewhere on the board

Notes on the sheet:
AVCC3v3: max. 18mA DVDD3v3: max. 6.3mA
I2C_addr: 0x94


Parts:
C1, C2, C4, C22, C23, C24, C25, C26, C27, C28, C29, C32, C33, C34, C35, C36, C37, C38, C39, C40, C299, C333, C334: 0.1u; C_0402_1005Metric
C7, C8, C9, C14, C15, C16, C17, C18, C19, C20: 10n; C_0402_1005Metric
R4, R5, R6, R12, R13, R14, R17, R18, R19: 75; R_0603_1608Metric
R15: 500; R_0402_1005Metric
R81: 1k; R_0402_1005Metric
U8: ISL51002CQZ-165
U32, U33: SN74LVC2G17; SC-70-8

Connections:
/AFE - RGB/AV1_B_AC: C9.1, U8.25 (BIN0)
/AFE - RGB/AV1_G_AC: C8.1, U8.27 (GIN0)
/AFE - RGB/AV1_HS_3v3: U8.50 (HSYNCIN0), U33.6 (1Y)
/AFE - RGB/AV1_R_AC: C7.1, U8.31 (RIN0)
/AFE - RGB/AV1_VS_3v3: U8.49 (VSYNCIN0), U33.4 (2Y)
/AFE - RGB/AV2_B_AC: C16.1, U8.17 (BIN1)
/AFE - RGB/AV2_GS_AC: R15.1, U8.21 (SOGIN1)
/AFE - RGB/AV2_G_AC: C15.1, U8.19 (GIN1)
/AFE - RGB/AV2_R_AC: C14.1, U8.23 (RIN1)
/AFE - RGB/AV3_B_AC: C20.1, U8.9 (BIN2)
/AFE - RGB/AV3_G_AC: C19.1, U8.11 (GIN2)
/AFE - RGB/AV3_HS_3v3: U8.46 (HSYNCIN2), U32.6 (1Y)
/AFE - RGB/AV3_R_AC: C18.1, U8.15 (RIN2)
/AFE - RGB/AV3_VS_3v3: U8.45 (VSYNCIN2), U32.4 (2Y)
AV1_B: C9.2, R6.1; also elsewhere on the board
AV1_G: C8.2, R5.1; also elsewhere on the board
AV1_HS: U33.1 (1A); also elsewhere on the board
AV1_R: C7.2, R4.1; also elsewhere on the board
AV1_S_AC: U8.29 (SOGIN0); also elsewhere on the board
AV1_VS: U33.3 (2A); also elsewhere on the board
AV2_B: C16.2, R14.1; also elsewhere on the board
AV2_G: C15.2, C17.2, R13.1; also elsewhere on the board
AV2_R: C14.2, R12.1; also elsewhere on the board
AV3_B: C20.2, R19.1; also elsewhere on the board
AV3_G: C19.2, R18.1; also elsewhere on the board
AV3_HS: U32.1 (1A); also elsewhere on the board
AV3_R: C18.2, R17.1; also elsewhere on the board
AV3_S_AC: U8.13 (SOGIN2); also elsewhere on the board
AV3_VS: U32.3 (2A); also elsewhere on the board
AVCC1v8: C1.1, C4.1, C22.1, C24.1, C25.1, C27.1, U8.2 (VA1-8), U8.10 (VREFRED), U8.12 (VA1-8_2), U8.20 (VREFGREEN), U8.22 (VA1-8_3), U8.30 (VREFBLUE); also elsewhere on the board
AVCC3v3: C2.1, C23.1, C26.1, C29.1, U8.6 (VA3-3), U8.16 (VA3-3_2), U8.26 (VA3-3_3), U8.36 (VPLLA3-3); also elsewhere on the board
CLK27: C299.1; also elsewhere on the board
DVDD1v8: C28.1, C32.1, C33.1, C35.1, C38.1, C40.1, U8.32 (VADCD1-8), U8.41 (VPLLD1-8), U8.71 (VD1-8), U8.83 (VD1-8_2), U8.97 (VD1-8_3), U8.111 (VD1-8_4); also elsewhere on the board
DVDD3v3: C34.1, C36.1, C37.1, C39.1, C333.1, C334.1, R81.1, U8.76 (VD3-3), U8.90 (VD3-3_2), U8.104 (VD3-3_3), U8.118 (VD3-3_4), U32.5 (Vcc), U33.5 (Vcc); also elsewhere on the board
GND: C1.2, C2.2, C4.2, C22.2, C23.2, C24.2, C25.2, C26.2, C27.2, C28.2, C29.2, C32.2, C33.2, C34.2, C35.2, C36.2, C37.2, C38.2, C39.2, C40.2, C333.2, C334.2, R4.2, R5.2, R6.2, R12.2, R13.2, R14.2, R17.2, R18.2, R19.2, U8.4 (GNDA), U8.8 (GNDA), U8.14 (GNDA), U8.18 (GNDA), U8.24 (GNDA), U8.28 (GNDA), U8.33 (GNDD), U8.34 (ATEST1), U8.35 (ATEST2), U8.37 (GNDA), U8.42 (GNDD), U8.43 (GNDD), U8.44 (GNDD), U8.47 (VSYNCIN1), U8.48 (HSYNCIN1), U8.51 (DTEST1), U8.52 (GNDD), U8.53 (GNDD), U8.55 (GNDD), U8.56 (GNDD), U8.57 (DTEST2), U8.58 (GNDD), U8.59 (GNDD), U8.60 (GNDD), U8.61 (CLOCKINVIN), U8.63 (CLAMPIN), U8.64 (COASTIN), U8.66 (FBCIN), U8.70 (GNDD), U8.73 (DTEST3), U8.74 (DTEST4), U8.75 (GNDD), U8.82 (GNDD), U8.89 (GNDD), U8.96 (GNDD), U8.103 (GNDD), U8.110 (GNDD), U8.117 (GNDD), U8.128 (GNDA), U32.2 (GND), U33.2 (GND); also elsewhere on the board
ISL_B0: U8.86 (B2); also elsewhere on the board
ISL_B1: U8.85 (B3); also elsewhere on the board
ISL_B2: U8.84 (B4); also elsewhere on the board
ISL_B3: U8.81 (B5); also elsewhere on the board
ISL_B4: U8.80 (B6); also elsewhere on the board
ISL_B5: U8.79 (B7); also elsewhere on the board
ISL_B6: U8.78 (B8); also elsewhere on the board
ISL_B7: U8.77 (B9); also elsewhere on the board
ISL_EXT_PCLK: U8.54 (EXTCLKIN); also elsewhere on the board
ISL_G0: U8.100 (G2); also elsewhere on the board
ISL_G1: U8.99 (G3); also elsewhere on the board
ISL_G2: U8.98 (G4); also elsewhere on the board
ISL_G3: U8.95 (G5); also elsewhere on the board
ISL_G4: U8.94 (G6); also elsewhere on the board
ISL_G5: U8.93 (G7); also elsewhere on the board
ISL_G6: U8.92 (G8); also elsewhere on the board
ISL_G7: U8.91 (G9); also elsewhere on the board
ISL_HS: U8.121 (HSOUT); also elsewhere on the board
ISL_HSYNC: U8.122 (HSYNCOUT); also elsewhere on the board
ISL_INT#: U8.124 (*INT); also elsewhere on the board
ISL_PCLK: U8.120 (DATACLK); also elsewhere on the board
ISL_R0: U8.114 (R2); also elsewhere on the board
ISL_R1: U8.113 (R3); also elsewhere on the board
ISL_R2: U8.112 (R4); also elsewhere on the board
ISL_R3: U8.109 (R5); also elsewhere on the board
ISL_R4: U8.108 (R6); also elsewhere on the board
ISL_R5: U8.107 (R7); also elsewhere on the board
ISL_R6: U8.106 (R8); also elsewhere on the board
ISL_R7: U8.105 (R9); also elsewhere on the board
ISL_RESET#: U8.62 (*RESET); also elsewhere on the board
ISL_VSYNC: U8.123 (VSYNCOUT); also elsewhere on the board
unnamed: C17.1, R15.2
unnamed: C299.2, U8.39 (XTALIN)
unnamed: R81.2, U8.67 (SADDR)
SCL: U8.69 (SCL); also elsewhere on the board
SDA: U8.68 (SDA); also elsewhere on the board

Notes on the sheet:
I2C_addr: 0x9a
AVCC1v8: max. 375mA AVCC3v3: max. 115mA DVDD1v8: max. 170mA DVDD3v3: max. 60mA


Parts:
C295, C296, C311, C312, C313, C314, C330, C331: 0.1u; C_0402_1005Metric
D39, D40, D41, D42, D43, D44, D45, D46, D47, D52, D53, D54: PESD3V3X4UHC; PESD3V3X4UHCYL
J7: 30350-5002HB; IDC-Header_2x25_P2.54mm_Horizontal
U21, U24: SN74AVC16T245DGGR; TSSOP-48_6.1x12.5mm_P0.5mm

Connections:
/I/O - Expansion/EXP_IO_B_0: D52.1 (IO1), J7.9, U21.23 (2B8)
/I/O - Expansion/EXP_IO_B_1: D52.3 (IO2), J7.10, U21.22 (2B7)
/I/O - Expansion/EXP_IO_B_2: D52.4 (IO3), J7.11, U21.20 (2B6)
/I/O - Expansion/EXP_IO_B_3: D52.6 (IO4), J7.12, U21.19 (2B5)
/I/O - Expansion/EXP_IO_B_4: D53.1 (IO1), J7.13, U21.17 (2B4)
/I/O - Expansion/EXP_IO_B_5: D53.3 (IO2), J7.14, U21.16 (2B3)
/I/O - Expansion/EXP_IO_B_6: D53.4 (IO3), J7.15, U21.14 (2B2)
/I/O - Expansion/EXP_IO_B_7: D53.6 (IO4), J7.16, U21.13 (2B1)
/I/O - Expansion/EXP_IO_B_8: D41.1 (IO1), J7.19, U21.12 (1B8)
/I/O - Expansion/EXP_IO_B_9: D41.3 (IO2), J7.20, U21.11 (1B7)
/I/O - Expansion/EXP_IO_B_10: D41.4 (IO3), J7.21, U21.9 (1B6)
/I/O - Expansion/EXP_IO_B_11: D41.6 (IO4), J7.22, U21.8 (1B5)
/I/O - Expansion/EXP_IO_B_12: D42.1 (IO1), J7.23, U21.6 (1B4)
/I/O - Expansion/EXP_IO_B_13: D42.3 (IO2), J7.24, U21.5 (1B3)
/I/O - Expansion/EXP_IO_B_14: D42.4 (IO3), J7.25, U21.3 (1B2)
/I/O - Expansion/EXP_IO_B_15: D42.6 (IO4), J7.26, U21.2 (1B1)
/I/O - Expansion/EXP_IO_B_16: D43.1 (IO1), J7.27, U24.23 (2B8)
/I/O - Expansion/EXP_IO_B_17: D43.3 (IO2), J7.28, U24.22 (2B7)
/I/O - Expansion/EXP_IO_B_18: D43.4 (IO3), J7.29, U24.20 (2B6)
/I/O - Expansion/EXP_IO_B_19: D43.6 (IO4), J7.30, U24.19 (2B5)
/I/O - Expansion/EXP_IO_B_20: D44.1 (IO1), J7.31, U24.17 (2B4)
/I/O - Expansion/EXP_IO_B_21: D44.3 (IO2), J7.32, U24.16 (2B3)
/I/O - Expansion/EXP_IO_B_22: D44.4 (IO3), J7.33, U24.14 (2B2)
/I/O - Expansion/EXP_IO_B_23: D44.6 (IO4), J7.34, U24.13 (2B1)
/I/O - Expansion/EXP_IO_B_24: D45.1 (IO1), J7.37, U24.12 (1B8)
/I/O - Expansion/EXP_IO_B_25: D45.3 (IO2), J7.38, U24.11 (1B7)
/I/O - Expansion/EXP_IO_B_26: D45.4 (IO3), J7.39, U24.9 (1B6)
/I/O - Expansion/EXP_IO_B_27: D45.6 (IO4), J7.40, U24.8 (1B5)
/I/O - Expansion/EXP_IO_B_28: D46.1 (IO1), J7.41, U24.6 (1B4)
/I/O - Expansion/EXP_IO_B_29: D46.3 (IO2), J7.42, U24.5 (1B3)
/I/O - Expansion/EXP_IO_B_30: D46.4 (IO3), J7.43, U24.3 (1B2)
/I/O - Expansion/EXP_IO_B_31: D46.6 (IO4), J7.44, U24.2 (1B1)
DVDD1v2: C313.1, C314.1, C330.1, C331.1, U21.31 (VCCA), U21.42 (VCCA), U24.31 (VCCA), U24.42 (VCCA); also elsewhere on the board
DVDD3v3: C295.1, C296.1, C311.1, C312.1, J7.35, U21.7 (VCCB), U21.18 (VCCB), U24.7 (VCCB), U24.18 (VCCB); also elsewhere on the board
DVDD5: J7.17; also elsewhere on the board
EXP_IO_A_0|CLKIN_P: D39.4 (IO3), J7.3; also elsewhere on the board
EXP_IO_A_1|CLKIN_N: D39.6 (IO4), J7.4; also elsewhere on the board
EXP_IO_A_2: D40.1 (IO1), J7.5; also elsewhere on the board
EXP_IO_A_3: D40.3 (IO2), J7.6; also elsewhere on the board
EXP_IO_A_4: D40.4 (IO3), J7.7; also elsewhere on the board
EXP_IO_A_5: D40.6 (IO4), J7.8; also elsewhere on the board
EXP_IO_B_0_1v2: U21.26 (2A8); also elsewhere on the board
EXP_IO_B_1_1v2: U21.27 (2A7); also elsewhere on the board
EXP_IO_B_2_1v2: U21.29 (2A6); also elsewhere on the board
EXP_IO_B_3_1v2: U21.30 (2A5); also elsewhere on the board
EXP_IO_B_4_1v2: U21.32 (2A4); also elsewhere on the board
EXP_IO_B_5_1v2: U21.33 (2A3); also elsewhere on the board
EXP_IO_B_6_1v2: U21.35 (2A2); also elsewhere on the board
EXP_IO_B_7_1v2: U21.36 (2A1); also elsewhere on the board
EXP_IO_B_8_1v2: U21.37 (1A8); also elsewhere on the board
EXP_IO_B_9_1v2: U21.38 (1A7); also elsewhere on the board
EXP_IO_B_10_1v2: U21.40 (1A6); also elsewhere on the board
EXP_IO_B_11_1v2: U21.41 (1A5); also elsewhere on the board
EXP_IO_B_12_1v2: U21.43 (1A4); also elsewhere on the board
EXP_IO_B_13_1v2: U21.44 (1A3); also elsewhere on the board
EXP_IO_B_14_1v2: U21.46 (1A2); also elsewhere on the board
EXP_IO_B_15_1v2: U21.47 (1A1); also elsewhere on the board
EXP_IO_B_16_1v2: U24.26 (2A8); also elsewhere on the board
EXP_IO_B_17_1v2: U24.27 (2A7); also elsewhere on the board
EXP_IO_B_18_1v2: U24.29 (2A6); also elsewhere on the board
EXP_IO_B_19_1v2: U24.30 (2A5); also elsewhere on the board
EXP_IO_B_20_1v2: U24.32 (2A4); also elsewhere on the board
EXP_IO_B_21_1v2: U24.33 (2A3); also elsewhere on the board
EXP_IO_B_22_1v2: U24.35 (2A2); also elsewhere on the board
EXP_IO_B_23_1v2: U24.36 (2A1); also elsewhere on the board
EXP_IO_B_24_1v2: U24.37 (1A8); also elsewhere on the board
EXP_IO_B_25_1v2: U24.38 (1A7); also elsewhere on the board
EXP_IO_B_26_1v2: U24.40 (1A6); also elsewhere on the board
EXP_IO_B_27_1v2: U24.41 (1A5); also elsewhere on the board
EXP_IO_B_28_1v2: U24.43 (1A4); also elsewhere on the board
EXP_IO_B_29_1v2: U24.44 (1A3); also elsewhere on the board
EXP_IO_B_30_1v2: U24.46 (1A2); also elsewhere on the board
EXP_IO_B_31_1v2: U24.47 (1A1); also elsewhere on the board
GND: C295.2, C296.2, C311.2, C312.2, C313.2, C314.2, C330.2, C331.2, D39.2 (GND), D39.5 (GND), D40.2 (GND), D40.5 (GND), D41.2 (GND), D41.5 (GND), D42.2 (GND), D42.5 (GND), D43.2 (GND), D43.5 (GND), D44.2 (GND), D44.5 (GND), D45.2 (GND), D45.5 (GND), D46.2 (GND), D46.5 (GND), D47.2 (GND), D47.5 (GND), D52.2 (GND), D52.5 (GND), D53.2 (GND), D53.5 (GND), D54.2 (GND), D54.5 (GND), J7.18, J7.36, U21.4 (GND), U21.10 (GND), U21.15 (GND), U21.21 (GND), U21.25 (*2OE), U21.28 (GND), U21.34 (GND), U21.39 (GND), U21.45 (GND), U21.48 (*1OE), U24.4 (GND), U24.10 (GND), U24.15 (GND), U24.21 (GND), U24.25 (*2OE), U24.28 (GND), U24.34 (GND), U24.39 (GND), U24.45 (GND), U24.48 (*1OE); also elsewhere on the board
HDMITX_I2S0: D54.4 (IO3), J7.47; also elsewhere on the board
HDMITX_I2S_BCK: D54.1 (IO1), J7.45; also elsewhere on the board
HDMITX_I2S_WS: D54.3 (IO2), J7.46; also elsewhere on the board
HDMITX_SPDIF: D54.6 (IO4), J7.48; also elsewhere on the board
LS0_DIR_1v2: U21.1 (1DIR), U21.24 (2DIR); also elsewhere on the board
LS1_DIR_1v2: U24.1 (1DIR), U24.24 (2DIR); also elsewhere on the board
SCL: D47.6 (IO4), J7.50; also elsewhere on the board
SDA: D47.4 (IO3), J7.49; also elsewhere on the board
SI_CLK_XTRA2: D39.1 (IO1), J7.1; also elsewhere on the board
SI_CLK_XTRA3: D39.3 (IO2), J7.2; also elsewhere on the board


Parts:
C108, C109, C110, C111, C293, C294, C298, C309, C317: 0.1u; C_0402_1005Metric
U2: Si5351C; QFN-20-1EP_4x4mm_Pitch0.5mm_Handsoldering
U23, U25: SN74AUP1G17DCKT
X1: FNSURV027; PinHeader_2x02_P2.54mm_Vertical

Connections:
CLK27: U23.2 (A), X1.3 (XOUT); also elsewhere on the board
CLK27_1v2: C108.2, U25.4 (Y); also elsewhere on the board
CLK27_1v8: U23.4 (Y), U25.2 (A); also elsewhere on the board
DVDD1v2: C317.1, U25.5 (VCC); also elsewhere on the board
DVDD1v8: C309.1, U23.5 (VCC); also elsewhere on the board
DVDD3v3: C109.1, C110.1, C111.1, C293.1, C294.1, C298.1, U2.10 (VDDOB), U2.11 (VDDOA), U2.14 (VDDOD), U2.18 (VDDOC), U2.20 (VDD), X1.1 (OE), X1.4 (VDD); also elsewhere on the board
FPGA_PCLK1x: U2.6 (CLKIN); also elsewhere on the board
GND: C109.2, C110.2, C111.2, C293.2, C294.2, C298.2, C309.2, C317.2, U2.7 (OEB), U2.EP (GND), U23.3 (GND), U25.3 (GND), X1.2 (GND); also elsewhere on the board
unnamed: C108.1, U2.1 (XA)
SCL: U2.4 (SCL); also elsewhere on the board
SDA: U2.5 (SDA); also elsewhere on the board
SI_CLK_XTRA1: U2.9 (CLK2); also elsewhere on the board
SI_CLK_XTRA2: U2.19 (CLK4); also elsewhere on the board
SI_CLK_XTRA3: U2.16 (CLK6); also elsewhere on the board
SI_INT#: U2.3 (INTR); also elsewhere on the board
SI_PCLK: U2.13 (CLK0); also elsewhere on the board

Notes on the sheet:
DVDD3v3: max. 95mA
I2C_addr: 0xc0


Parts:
P1: 5CEFA5F23

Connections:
BTN0: P1.P7 (IO_3A); also elsewhere on the board
BTN1: P1.AA12 (IO_3B); also elsewhere on the board
FPGA_PCLK1x: P1.AB11 (IO_3B); also elsewhere on the board
ISL_B0: P1.R11 (IO_3B); also elsewhere on the board
ISL_B1: P1.R10 (IO_3B); also elsewhere on the board
ISL_B2: P1.P12 (IO_3B); also elsewhere on the board
ISL_B3: P1.U12 (IO_3B); also elsewhere on the board
ISL_B4: P1.R12 (IO_3B); also elsewhere on the board
ISL_B5: P1.U11 (IO_3B); also elsewhere on the board
ISL_B6: P1.R9 (IO_3B); also elsewhere on the board
ISL_B7: P1.Y9 (IO_3B); also elsewhere on the board
ISL_EXT_PCLK: P1.AB10 (IO_3B); also elsewhere on the board
ISL_G0: P1.T10 (IO_3B); also elsewhere on the board
ISL_G1: P1.Y10 (IO_3B); also elsewhere on the board
ISL_G2: P1.AA9 (IO_3B); also elsewhere on the board
ISL_G3: P1.AA10 (IO_3B); also elsewhere on the board
ISL_G4: P1.U10 (IO_3B); also elsewhere on the board
ISL_G5: P1.AB8 (IO_3B); also elsewhere on the board
ISL_G6: P1.T9 (IO_3B); also elsewhere on the board
ISL_G7: P1.AA8 (IO_3B); also elsewhere on the board
ISL_HS: P1.Y11 (IO_3B); also elsewhere on the board
ISL_PCLK: P1.M9 (IO_3B/CLK0P); also elsewhere on the board
ISL_R0: P1.AB7 (IO_3B); also elsewhere on the board
ISL_R1: P1.N8 (IO_3B); also elsewhere on the board
ISL_R2: P1.AA7 (IO_3B); also elsewhere on the board
ISL_R3: P1.P8 (IO_3B); also elsewhere on the board
ISL_R4: P1.V10 (IO_3B); also elsewhere on the board
ISL_R5: P1.AB5 (IO_3B); also elsewhere on the board
ISL_R6: P1.V9 (IO_3B); also elsewhere on the board
ISL_R7: P1.AB6 (IO_3B); also elsewhere on the board
SPDIF_EXT: P1.M8 (IO_3B/CLK0N); also elsewhere on the board

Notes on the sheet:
VCCIO = 3.3V

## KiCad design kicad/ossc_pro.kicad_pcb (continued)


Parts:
C132, C133, C134, C136: 0.1u; C_0402_1005Metric
D1: 5640100833F; WP934SA&slash_LILYLGD
D34, D35, D36, D38, D48: PESD3V3X4UHC; PESD3V3X4UHCYL
DS1: NHD-0220CW-AW3; PinHeader_1x20_P2.54mm_Vertical
J5: 503182-1852; MOLEX_503182-1852
J8: 30310-5002HB; IDC-Header_2x05_P2.54mm_Horizontal
J15: TSOP31338; TSOP31..._1
J18, J19, J20: TSW-101-08-T-T-RA; PinHeader_1x03_P2.54mm_Vertical
J21: 0470531000; FanPinHeader_1x04_P2.54mm_Vertical
J22: 0673298000; USB_A_Molex_067329-8000
Q4, Q5, Q6, Q9: BC847; SOT-23
R55, R56, R57, R58, R59, R63, R64, R89, R91, R103, R104, R108, R124, R125, R126, R127, R128, R144: 10k; R_0402_1005Metric
R65, R66, R106, R107, R143: 300; R_0603_1608Metric
R92, R93: 100; R_0603_1608Metric
R123: 1k; R_0402_1005Metric
R142: 2k; R_0603_1608Metric
R145, R146: 15k; R_0402_1005Metric

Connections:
/I/O - User/LED_B_C: D1.5, R106.1
/I/O - User/LED_G_C: D1.3, R93.1
/I/O - User/LED_R_C: D1.1, R92.1
BTN0: D38.1 (IO1), J18.3, R63.2; also elsewhere on the board
BTN1: D38.3 (IO2), J18.2, R64.2; also elsewhere on the board
BTN2: D38.4 (IO3), J18.1, R125.2; also elsewhere on the board
BTN3: D38.6 (IO4), J19.2, R124.2; also elsewhere on the board
BTN4: D48.1 (IO1), J19.1, R127.2; also elsewhere on the board
BTN5: D48.3 (IO2), J20.1, R126.2; also elsewhere on the board
DVDD3v3: C132.1, C133.1, C134.1, C136.1, D1.2, D1.4, D1.6, DS1.2, J5.4 (VDD), J8.4, J15.2, R55.1, R56.1, R57.1, R58.1, R59.1, R63.1, R64.1, R103.2, R104.2, R123.2, R124.1, R125.1, R126.1, R127.1, R128.2; also elsewhere on the board
DVDD5: J21.2, J22.1 (VBUS), R142.1; also elsewhere on the board
FAN_PWM: R143.2; also elsewhere on the board
GND: C132.2, C133.2, C134.2, C136.2, D34.2 (GND), D34.5 (GND), D35.2 (GND), D35.5 (GND), D36.2 (GND), D36.5 (GND), D38.2 (GND), D38.5 (GND), D48.2 (GND), D48.5 (GND), DS1.1, DS1.3, DS1.5, DS1.6, DS1.10, DS1.11, DS1.12, DS1.13, DS1.14, DS1.15, DS1.17, DS1.19, DS1.20, J5.6 (VSS), J5.P1 (SHIELD), J5.P2 (SHIELD), J5.P3 (SHIELD), J5.P4 (SHIELD), J5.P5 (SHIELD), J5.SW (SWITCH), J8.2, J8.10, J15.1, J19.3, J20.3, J21.1, J22.4 (GND), J22.5 (Shield), Q4.2 (E), Q5.2 (E), Q6.2 (E), Q9.2 (E), R89.2, R91.2, R108.2, R144.2, R145.1, R146.2; also elsewhere on the board
IR_RX: J15.3; also elsewhere on the board
LED0: R65.2; also elsewhere on the board
LED1: R66.2; also elsewhere on the board
LED2: R107.2; also elsewhere on the board
unnamed: DS1.4, R123.1
unnamed: DS1.16, R103.1
unnamed: DS1.18, R104.1
unnamed: J21.4, Q9.3 (C), R142.2
unnamed: Q4.1 (B), R65.1, R91.1
unnamed: Q4.3 (C), R92.2
unnamed: Q5.1 (B), R66.1, R89.1
unnamed: Q5.3 (C), R93.2
unnamed: Q6.1 (B), R107.1, R108.1
unnamed: Q6.3 (C), R106.2
unnamed: Q9.1 (B), R143.1, R144.1
SCL: DS1.7; also elsewhere on the board
SDA: DS1.8, DS1.9; also elsewhere on the board
SD_CLK: D36.1 (IO1), J5.5 (CLK); also elsewhere on the board
SD_CMD: D36.3 (IO2), J5.3 (CMD), R55.2; also elsewhere on the board
SD_DATA0: D35.6 (IO4), J5.7 (DAT0), R58.2; also elsewhere on the board
SD_DATA1: D35.4 (IO3), J5.8 (DAT1), R59.2; also elsewhere on the board
SD_DATA2: D35.3 (IO2), J5.1 (DATA2), R57.2; also elsewhere on the board
SD_DATA3: D35.1 (IO1), J5.2 (CD/DAT3), R56.2; also elsewhere on the board
SD_DETECT: J5.DT (DETECT), R128.1; also elsewhere on the board
TCK: D34.1 (IO1), J8.1; also elsewhere on the board
TDI: D34.4 (IO3), J8.9; also elsewhere on the board
TDO: D34.6 (IO4), J8.3; also elsewhere on the board
TMS: D34.3 (IO2), J8.5; also elsewhere on the board
USB_D+: D36.6 (IO4), J22.3 (D+), R145.2; also elsewhere on the board
USB_D-: D36.4 (IO3), J22.2 (D-), R146.1; also elsewhere on the board

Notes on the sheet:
I2C_addr: 0x7a

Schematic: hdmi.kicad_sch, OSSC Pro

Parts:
C57, C58, C59, C60, C63, C64, C65, C67, C68, C70, C72, C73, C74, C75, C76, C79, C81, C82, C83, C87, C88, C89, C90, C95, C96, C97, C98, C99, C100, C101, C256, C332: 0.1u; C_0402_1005Metric
C61, C62, C69, C71, C105, C106, C107: 10u; C_0603_1608Metric
C77, C78, C80, C84, C85, C86, C91, C92, C93, C94, C102, C103, C104: 10n; C_0402_1005Metric
FB1, FB2, FB3, FB4, FB5, FB6, FB7: MPZ1608R391ATA00; L_0603_1608Metric
R37: 4.02k; R_0603_1608Metric
R140: 1k; R_0402_1005Metric
U3: ADV7610BBCZ-P; ADV7610BBCZ
U4: SiI1136; TQFP-100_thermal

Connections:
/HDMI/AVCC1v8_F3: C75.1, C76.1, C77.1, C78.1, C106.1, FB6.1, U3.G1 (CVDD), U3.G2 (CVDD)
/HDMI/AVCC1v8_F4: C79.1, C80.1, C107.1, FB7.1, U3.A4 (PVDD)
/HDMI/AVCC3v3_F: C99.1, C100.1, C102.1, C103.1, C105.1, FB1.1, U3.B1 (TVDD), U3.B2 (TVDD)
/HDMI/DVDD1v2_F1: C59.1, C60.1, C71.1, C72.1, C73.1, C74.1, FB4.1, U4.5 (CVCC12), U4.16 (CVCC12), U4.21 (CVCC12), U4.38 (CVCC12), U4.88 (CVCC12)
/HDMI/DVDD1v2_F2: C62.1, C63.1, C64.1, FB5.1, U4.56 (AVCC), U4.61 (AVCC)
/HDMI/DVDD1v8_F: C61.1, C87.1, C88.1, C89.1, C90.1, C91.1, C92.1, C93.1, C94.1, FB2.1, U3.A10 (DVDD), U3.B10 (DVDD), U3.D7 (DVDD), U3.E7 (DVDD)
/HDMI/DVDD3v3_F: C57.1, C58.1, C69.1, C70.1, C81.1, C82.1, C83.1, C84.1, C85.1, C86.1, C101.1, C104.1, C332.1, FB3.1, R140.2, U3.F7 (DVDDIO), U3.G7 (DVDDIO), U3.J10 (DVDDIO), U3.K10 (DVDDIO), U4.1 (IOVCC33), U4.12 (IOVCC33), U4.37 (IOVCC33), U4.91 (IOVCC33)
/HDMI/HDMIRX_CLK: C256.2, U3.A6 (XTALP)
/HDMI/HDMIRX_I2S1: U3.C10 (I2S1), U4.32 (SD1_DR1)
/HDMI/HDMIRX_I2S2: U3.D9 (I2S2), U4.31 (SD2_DL1)
/HDMI/HDMIRX_I2S3: U3.C9 (I2S3), U4.30 (SD3_DR2)
AVCC1v8: C96.1, C97.1, FB6.2, FB7.2; also elsewhere on the board
AVCC3v3: C98.1, FB1.2; also elsewhere on the board
CLK27_1v8: C256.1; also elsewhere on the board
DVDD1v2: C67.1, C95.1, FB4.2, FB5.2; also elsewhere on the board
DVDD1v8: C65.1, FB2.2; also elsewhere on the board
DVDD3v3: C68.1, FB3.2; also elsewhere on the board
GND: C57.2, C58.2, C59.2, C60.2, C61.2, C62.2, C63.2, C64.2, C65.2, C67.2, C68.2, C69.2, C70.2, C71.2, C72.2, C73.2, C74.2, C75.2, C76.2, C77.2, C78.2, C79.2, C80.2, C81.2, C82.2, C83.2, C84.2, C85.2, C86.2, C87.2, C88.2, C89.2, C90.2, C91.2, C92.2, C93.2, C94.2, C95.2, C96.2, C97.2, C98.2, C99.2, C100.2, C101.2, C102.2, C103.2, C104.2, C105.2, C106.2, C107.2, C332.2, R37.1, U3.B5 (*CS), U3.D4 (GND), U3.D5 (GND), U3.D6 (GND), U3.E4 (GND), U3.F4 (GND), U3.G4 (GND), U3.G5 (GND), U3.G6 (GND), U4.2 (D15), U4.3 (D14), U4.4 (D13), U4.6 (D12), U4.17 (D3), U4.18 (D2), U4.19 (D1), U4.20 (D0), U4.27 (DL3), U4.28 (DR3), U4.36 (MCLK), U4.48 (GND), U4.53 (GND), U4.86 (D27), U4.87 (D26), U4.89 (D25), U4.90 (D24), U4.100 (GND), U4.EP (GND); also elsewhere on the board
HDMIRX_0+: U3.D1 (RXA_0+); also elsewhere on the board
HDMIRX_0-: U3.D2 (RXA_0-); also elsewhere on the board
HDMIRX_1+: U3.E1 (RXA_1+); also elsewhere on the board
HDMIRX_1-: U3.E2 (RXA_1-); also elsewhere on the board
HDMIRX_2+: U3.F1 (RXA_2+); also elsewhere on the board
HDMIRX_2-: U3.F2 (RXA_2-); also elsewhere on the board
HDMIRX_B0: U3.F10 (P0); also elsewhere on the board
HDMIRX_B1: U3.G9 (P1); also elsewhere on the board
HDMIRX_B2: U3.G10 (P2); also elsewhere on the board
HDMIRX_B3: U3.H9 (P3); also elsewhere on the board
HDMIRX_B4: U3.H10 (P4); also elsewhere on the board
HDMIRX_B5: U3.J9 (P5); also elsewhere on the board
HDMIRX_B6: U3.K9 (P6); also elsewhere on the board
HDMIRX_B7: U3.J8 (P7); also elsewhere on the board
HDMIRX_C+: U3.C1 (RXA_C+); also elsewhere on the board
HDMIRX_C-: U3.C2 (RXA_C-); also elsewhere on the board
HDMIRX_CEC: U3.B4 (CEC); also elsewhere on the board
HDMIRX_DDC5V: U3.A2 (RXA_5V); also elsewhere on the board
HDMIRX_DDCSCL: U3.A3 (DDCA_SCL); also elsewhere on the board
HDMIRX_DDCSDA: U3.B3 (DDCA_SDA); also elsewhere on the board
HDMIRX_DE: U3.E10 (DE); also elsewhere on the board
HDMIRX_G0: U3.K8 (P8); also elsewhere on the board
HDMIRX_G1: U3.J7 (P9); also elsewhere on the board
HDMIRX_G2: U3.K7 (P10); also elsewhere on the board
HDMIRX_G3: U3.J6 (P11); also elsewhere on the board
HDMIRX_G4: U3.K6 (P12); also elsewhere on the board
HDMIRX_G5: U3.J5 (P13); also elsewhere on the board
HDMIRX_G6: U3.K5 (P14); also elsewhere on the board
HDMIRX_G7: U3.J4 (P15); also elsewhere on the board
HDMIRX_HPA: U3.A1 (HPA_A/INT2); also elsewhere on the board
HDMIRX_HSYNC: U3.F9 (HS); also elsewhere on the board
HDMIRX_I2S0: U3.D10 (I2S0); also elsewhere on the board
HDMIRX_I2S_BCK: U3.A9 (SCLK/INT2); also elsewhere on the board
HDMIRX_I2S_WS: U3.B9 (LRCLK); also elsewhere on the board
HDMIRX_PCLK: U3.K4 (LLC); also elsewhere on the board
HDMIRX_R0: U3.J3 (P16); also elsewhere on the board
HDMIRX_R1: U3.K3 (P17); also elsewhere on the board
HDMIRX_R2: U3.J2 (P18); also elsewhere on the board
HDMIRX_R3: U3.K2 (P19); also elsewhere on the board
HDMIRX_R4: U3.K1 (P20); also elsewhere on the board
HDMIRX_R5: U3.J1 (P21); also elsewhere on the board
HDMIRX_R6: U3.H2 (P22); also elsewhere on the board
HDMIRX_R7: U3.H1 (P23); also elsewhere on the board
HDMIRX_VSYNC: U3.E9 (VS/FIELD/ALSB); also elsewhere on the board
HDMITX_0+: U4.58 (TX0+); also elsewhere on the board
HDMITX_0-: U4.57 (TX0-); also elsewhere on the board
HDMITX_1+: U4.60 (TX1+); also elsewhere on the board
HDMITX_1-: U4.59 (TX1-); also elsewhere on the board
HDMITX_2+: U4.63 (TX2+); also elsewhere on the board
HDMITX_2-: U4.62 (TX2-); also elsewhere on the board
HDMITX_B0: U4.15 (D4); also elsewhere on the board
HDMITX_B1: U4.14 (D5); also elsewhere on the board
HDMITX_B2: U4.13 (D6); also elsewhere on the board
HDMITX_B3: U4.11 (D7); also elsewhere on the board
HDMITX_B4: U4.10 (D8); also elsewhere on the board
HDMITX_B5: U4.9 (D9); also elsewhere on the board
HDMITX_B6: U4.8 (D10); also elsewhere on the board
HDMITX_B7: U4.7 (D11); also elsewhere on the board
HDMITX_C+: U4.55 (TXC+); also elsewhere on the board
HDMITX_C-: U4.54 (TXC-); also elsewhere on the board
HDMITX_CEC: U4.40 (CEC_A); also elsewhere on the board
HDMITX_DDCSCL: U4.42 (DSCL); also elsewhere on the board
HDMITX_DDCSDA: U4.41 (DSDA); also elsewhere on the board
HDMITX_DE: U4.25 (DE); also elsewhere on the board
HDMITX_G0: U4.99 (D16); also elsewhere on the board
HDMITX_G1: U4.98 (D17); also elsewhere on the board
HDMITX_G2: U4.97 (D18); also elsewhere on the board
HDMITX_G3: U4.96 (D19); also elsewhere on the board
HDMITX_G4: U4.95 (D20); also elsewhere on the board
HDMITX_G5: U4.94 (D21); also elsewhere on the board
HDMITX_G6: U4.93 (D22); also elsewhere on the board
HDMITX_G7: U4.92 (D23); also elsewhere on the board
HDMITX_HPD: U4.76 (HPD); also elsewhere on the board
HDMITX_HSYNC: U4.24 (HSYNC); also elsewhere on the board
HDMITX_I2S0: U4.33 (SD0_DL0); also elsewhere on the board
HDMITX_I2S_BCK: U4.35 (SCK); also elsewhere on the board
HDMITX_I2S_WS: U4.34 (WS_DR0); also elsewhere on the board
HDMITX_PCLK: U4.22 (IDCK); also elsewhere on the board
HDMITX_R0: U4.85 (D28); also elsewhere on the board
HDMITX_R1: U4.84 (D29); also elsewhere on the board
HDMITX_R2: U4.83 (D30); also elsewhere on the board
HDMITX_R3: U4.82 (D31); also elsewhere on the board
HDMITX_R4: U4.81 (D32); also elsewhere on the board
HDMITX_R5: U4.80 (D33); also elsewhere on the board
HDMITX_R6: U4.79 (D34); also elsewhere on the board
HDMITX_R7: U4.78 (D35); also elsewhere on the board
HDMITX_SPDIF: U4.29 (SPDIF_IN_DL2); also elsewhere on the board
HDMITX_VSYNC: U4.23 (VSYNC); also elsewhere on the board
HDMI_INT#: U3.A7 (INT1), U4.46 (INT); also elsewhere on the board
HDMI_RESET#: U3.B6 (*RESET), U4.47 (RESET#); also elsewhere on the board
unnamed: R140.1, U4.43 (CI2CA)
unnamed: R37.2, U4.52 (EXT_SWING)
SCL: U3.B8 (SCL), U4.45 (CSCL); also elsewhere on the board
SDA: U3.B7 (SDA), U4.44 (CSDA); also elsewhere on the board

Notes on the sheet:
AVCC1v8: max. 126mA AVCC3v3: max. 51mA DVDD1v8: max. 96mA DVDD3v3: max. 90mA
I2C_addr: 0x98
I2C_addr: 0x76, 0x7E, 0xC4
DVDD1v2: max. 100+40mA DVDD3v3: max. 4mA

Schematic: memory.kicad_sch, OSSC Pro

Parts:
C137, C139, C140, C141, C142, C143, C144, C145, C146, C147, C148, C149, C151, C153, C154, C155, C156, C157, C158, C159, C160, C161, C162, C163, C164, C165, C166, C167, C168, C169, C170, C171, C172, C173, C174: 0.1u; C_0402_1005Metric
C150, C152: 4.7u; C_0603_1608Metric
L14, L15: 10u; L_1210_3225Metric
R77, R78: 240; R_0603_1608Metric
R79: 4.7k; R_0402_1005Metric
R83, R84, R87, R88: 1.5k; R_0603_1608Metric
R85, R86: 1; R_0603_1608Metric
U9: MT42L32M32D1HE-18 IT:D; EDB1332BDBH-1DAAT-F
U10: N25Q128A13ESE40G

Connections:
AS_DATA0: U10.5 (DQ0); also elsewhere on the board
AS_DATA1: U10.2 (DQ1); also elsewhere on the board
AS_DATA2: U10.3 (W-/VPP/DQ2); also elsewhere on the board
AS_DATA3: U10.7 (HOLD-/DQ3); also elsewhere on the board
DVDD1v2: C143.1, C144.1, C145.1, C156.1, C157.1, C158.1, C159.1, C160.1, C161.1, C162.1, C163.1, C164.1, C165.1, C166.1, C167.1, C168.1, C169.1, C170.1, C171.1, C172.1, C173.1, C174.1, L14.1, L15.1, U9.B5 (VDD2), U9.C7 (VDDQ), U9.C10 (VDDQ), U9.D2 (VDD2), U9.D5 (VDDQ), U9.E9 (VDDQ), U9.F1 (VDDCA), U9.F10 (VDDQ), U9.G1 (VDD2), U9.H1 (VDDCA), U9.H6 (VDDQ), U9.J6 (VDDQ), U9.J7 (VDD2), U9.K6 (VDDQ), U9.M10 (VDDQ), U9.N2 (VDDCA), U9.N9 (VDDQ), U9.P2 (VDD2), U9.P5 (VDDQ), U9.R7 (VDDQ), U9.R10 (VDDQ), U9.T5 (VDD2); also elsewhere on the board
DVDD1v8: C139.1, C140.1, C141.1, C142.1, U9.B6 (VDD1), U9.C1 (VDD1), U9.R1 (VDD1), U9.T6 (VDD1); also elsewhere on the board
DVDD3v3: C137.1, U10.8 (VCC); also elsewhere on the board
FLASH_SCK: U10.6 (C); also elsewhere on the board
FLASH_nCSO: U10.1 (S-); also elsewhere on the board
GND: C137.2, C139.2, C140.2, C141.2, C142.2, C143.2, C144.2, C145.2, C146.2, C147.2, C148.2, C150.2, C152.2, C153.2, C154.2, C155.2, C156.2, C157.2, C158.2, C159.2, C160.2, C161.2, C162.2, C163.2, C164.2, C165.2, C166.2, C167.2, C168.2, C169.2, C170.2, C171.2, C172.2, C173.2, C174.2, R77.2, R78.2, R79.2, R84.2, R88.2, U9.C2 (VSS), U9.C5 (VSS), U9.C6 (VSSQ), U9.C9 (VSSQ), U9.D1 (VSS), U9.D10 (VSSQ), U9.E1 (VSSCA), U9.E10 (VSSQ), U9.F5 (VSSQ), U9.G10 (VSSQ), U9.H2 (VSS), U9.J1 (VSSCA), U9.J5 (VSSQ), U9.J8 (VSS), U9.L10 (VSSQ), U9.M5 (VSSQ), U9.N1 (VSSCA), U9.N10 (VSSQ), U9.P1 (VSS), U9.P10 (VSSQ), U9.R2 (VSS), U9.R5 (VSS), U9.R6 (VSSQ), U9.R9 (VSSQ), U10.4 (VSS); also elsewhere on the board
unnamed: C149.1, L14.2, R83.1, R85.1
unnamed: C150.1, R85.2
unnamed: C151.1, L15.2, R86.1, R87.1
unnamed: C152.1, R86.2
unnamed: R78.1, U9.D3 (ZQ0)
unnamed: R77.1, U9.C3 (ZQ1)
T_CA_0: U9.P3 (CA0); also elsewhere on the board
T_CA_1: U9.N3 (CA1); also elsewhere on the board
T_CA_2: U9.M3 (CA2); also elsewhere on the board
T_CA_3: U9.M2 (CA3); also elsewhere on the board
T_CA_4: U9.M1 (CA4); also elsewhere on the board
T_CA_5: U9.G2 (CA5); also elsewhere on the board
T_CA_6: U9.F2 (CA6); also elsewhere on the board
T_CA_7: U9.F3 (CA7); also elsewhere on the board
T_CA_8: U9.E3 (CA8); also elsewhere on the board
T_CA_9: U9.E2 (CA9); also elsewhere on the board
T_CK: U9.J3 (CK); also elsewhere on the board
T_CK#: U9.H3 (*CK); also elsewhere on the board
T_CKE_0: R79.1, U9.K1 (CKE); also elsewhere on the board
T_CS#_0: U9.L1 (*CS); also elsewhere on the board
T_DM_0: U9.K5 (DM0); also elsewhere on the board
T_DM_1: U9.H5 (DM1); also elsewhere on the board
T_DM_2: U9.N7 (DM2); also elsewhere on the board
T_DM_3: U9.E7 (DM3); also elsewhere on the board
T_DQS#_0: U9.L5 (*DQS0); also elsewhere on the board
T_DQS#_1: U9.G5 (*DQS1); also elsewhere on the board
T_DQS#_2: U9.P9 (*DQS2); also elsewhere on the board
T_DQS#_3: U9.D9 (*DQS3); also elsewhere on the board
T_DQS_0: U9.L6 (DQS0); also elsewhere on the board
T_DQS_1: U9.G6 (DQS1); also elsewhere on the board
T_DQS_2: U9.P8 (DQS2); also elsewhere on the board
T_DQS_3: U9.D8 (DQS3); also elsewhere on the board
T_DQ_0: U9.N8 (DQ0); also elsewhere on the board
T_DQ_1: U9.M8 (DQ1); also elsewhere on the board
T_DQ_2: U9.M7 (DQ2); also elsewhere on the board
T_DQ_3: U9.M9 (DQ3); also elsewhere on the board
T_DQ_4: U9.M6 (DQ4); also elsewhere on the board
T_DQ_5: U9.L7 (DQ5); also elsewhere on the board
T_DQ_6: U9.L8 (DQ6); also elsewhere on the board
T_DQ_7: U9.L9 (DQ7); also elsewhere on the board
T_DQ_8: U9.G9 (DQ8); also elsewhere on the board
T_DQ_9: U9.G8 (DQ9); also elsewhere on the board
T_DQ_10: U9.G7 (DQ10); also elsewhere on the board
T_DQ_11: U9.F6 (DQ11); also elsewhere on the board
T_DQ_12: U9.F9 (DQ12); also elsewhere on the board
T_DQ_13: U9.F7 (DQ13); also elsewhere on the board
T_DQ_14: U9.F8 (DQ14); also elsewhere on the board
T_DQ_15: U9.E8 (DQ15); also elsewhere on the board
T_DQ_16: U9.T7 (DQ16); also elsewhere on the board
T_DQ_17: U9.P6 (DQ17); also elsewhere on the board
T_DQ_18: U9.T8 (DQ18); also elsewhere on the board
T_DQ_19: U9.N5 (DQ19); also elsewhere on the board
T_DQ_20: U9.P7 (DQ20); also elsewhere on the board
T_DQ_21: U9.T9 (DQ21); also elsewhere on the board
T_DQ_22: U9.R8 (DQ22); also elsewhere on the board
T_DQ_23: U9.N6 (DQ23); also elsewhere on the board
T_DQ_24: U9.E6 (DQ24); also elsewhere on the board
T_DQ_25: U9.C8 (DQ25); also elsewhere on the board
T_DQ_26: U9.B9 (DQ26); also elsewhere on the board
T_DQ_27: U9.D7 (DQ27); also elsewhere on the board
T_DQ_28: U9.E5 (DQ28); also elsewhere on the board
T_DQ_29: U9.B8 (DQ29); also elsewhere on the board
T_DQ_30: U9.D6 (DQ30); also elsewhere on the board
T_DQ_31: U9.B7 (DQ31); also elsewhere on the board
VREFCA_LPDDR2: C146.1, C147.1, C148.1, C149.2, R83.2, R84.1, U9.G3 (VREFCA)
VREFDQ_LPDDR2: C151.2, C153.1, C154.1, C155.1, R87.2, R88.1, U9.J9 (VREFDQ); also elsewhere on the board

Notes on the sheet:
DVDD3v3: max. 20mA
DVDD1v2: max. 201mA DVDD1v8: max. 20mA

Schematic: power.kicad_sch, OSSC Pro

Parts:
C175: 47u; C_0805_2012Metric
C176, C177, C245, C246, C248, C249, C251, C252, C286, C287: 2.2u; C_0603_1608Metric
C254, C329: 10u; C_0805_2012Metric
C255, C328: 22u; C_0805_2012Metric
C289, C290: 4.7u; C_0603_1608Metric
D3: BZX84C5V1/SOT; D_SOD-323
J16: PJ-037A; BarrelJack_2pin_Horizontal
Q1, Q2: AOSS21115C; SOT-23
Q3: DSS20200L-7; SOT-23
R94, R95: 27k; R_0402_1005Metric
R96: 330; R_0805_2012Metric
R97, R99: 6.8k; R_0402_1005Metric
R98, R136, R137, R141: 100k; R_0402_1005Metric
R135: 37.4k; R_0402_1005Metric
R138: 47k; R_0402_1005Metric
U17, U26: TPS82085SILT; TPS82084SILT
U19: AP7361C-33FGE-7; SON65P300X300X63-9N
U27: LP5912-1.2DRVR
U28, U29: LP5912-1.8DRVR; LP5912-1.2DRVR
U30: LP5912-3.3DRVR; LP5912-1.2DRVR
U31: LP5912-2.5DRVR; LP5912-1.2DRVR

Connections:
/Power/PG_DVDD2v5: R141.2, U19.5 (EN), U26.2 (PG)
AVCC1v8: C245.1, U29.1 (OUT); also elsewhere on the board
AVCC2v5: C286.1, U31.1 (OUT); also elsewhere on the board
AVCC3v3: C248.1, U30.1 (OUT); also elsewhere on the board
DVDD1v1: C255.1, R135.1, U17.8 (VOUT); also elsewhere on the board
DVDD1v2: C176.1, U27.1 (OUT); also elsewhere on the board
DVDD1v8: C251.1, U28.1 (OUT); also elsewhere on the board
DVDD2v5: C177.1, C246.1, C252.1, C328.1, R137.1, U26.8 (VOUT), U27.4 (EN), U27.6 (IN), U28.4 (EN), U28.6 (IN), U29.4 (EN), U29.6 (IN); also elsewhere on the board
DVDD3v3: C289.1, U19.1 (OUT); also elsewhere on the board
DVDD5: C175.1, C249.1, C254.1, C287.1, C290.1, C329.1, Q2.3 (D), R141.1, U17.1 (EN), U17.3 (VIN), U17.4 (VIN), U19.8 (IN), U26.1 (EN), U26.3 (VIN), U26.4 (VIN), U30.4 (EN), U30.6 (IN), U31.4 (EN), U31.6 (IN); also elsewhere on the board
GND: C175.2, C176.2, C177.2, C245.2, C246.2, C248.2, C249.2, C251.2, C252.2, C254.2, C255.2, C286.2, C287.2, C289.2, C290.2, C328.2, C329.2, D3.2 (A), J16.2, R94.2, R99.2, R136.2, R138.2, U17.5 (GND), U17.6 (GND), U17.9 (PAD), U19.4 (GND), U19.E (EPAD), U26.5 (GND), U26.6 (GND), U26.9 (PAD), U27.5 (GND), U27.7 (PAD), U28.5 (GND), U28.7 (PAD), U29.5 (GND), U29.7 (PAD), U30.5 (GND), U30.7 (PAD), U31.5 (GND), U31.7 (PAD); also elsewhere on the board
unnamed: D3.1 (K), R96.2, R97.1
unnamed: J16.1, Q1.3 (D)
unnamed: Q1.1 (G), R94.1, R95.2
unnamed: Q1.2 (S), Q2.2 (S), Q3.2 (E), R95.1, R96.1, R98.1
unnamed: Q2.1 (G), Q3.3 (C), R98.2, R99.1
unnamed: Q3.1 (B), R97.2
unnamed: R135.2, R136.1, U17.7 (FB)
unnamed: R137.2, R138.1, U26.7 (FB)

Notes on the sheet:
reverse current protection
max. 160mA draw
max. 400mA draw
max. 1100mA output draw
max. 190mA draw
max. 320mA draw
max. 376mA draw
rated for 2.5A
max. 133mA draw
output draw rated up to 3A
overvoltage protection, Vth = 5.5V

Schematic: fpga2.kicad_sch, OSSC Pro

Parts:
P1: 5CEFA5F23
R61, R62: 2.2k; R_0402_1005Metric

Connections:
BTN2: P1.U17 (IO_4A); also elsewhere on the board
BTN3: P1.U20 (IO_4A); also elsewhere on the board
DVDD3v3: R61.1, R62.1; also elsewhere on the board
EXP_IO_A_2: P1.V21 (IO_4A); also elsewhere on the board
EXP_IO_A_3: P1.V18 (IO_4A); also elsewhere on the board
EXP_IO_A_4: P1.U16 (IO_4A); also elsewhere on the board
EXP_IO_A_5: P1.U21 (IO_4A); also elsewhere on the board
HDMIRX_B0: P1.V13 (IO_4A); also elsewhere on the board
HDMIRX_B1: P1.AB12 (IO_4A); also elsewhere on the board
HDMIRX_B2: P1.U13 (IO_4A); also elsewhere on the board
HDMIRX_B3: P1.T12 (IO_4A); also elsewhere on the board
HDMIRX_B4: P1.AA14 (IO_4A); also elsewhere on the board
HDMIRX_B5: P1.T13 (IO_4A); also elsewhere on the board
HDMIRX_B6: P1.AA13 (IO_4A); also elsewhere on the board
HDMIRX_B7: P1.AB15 (IO_4A); also elsewhere on the board
HDMIRX_DE: P1.AA22 (IO_4A); also elsewhere on the board
HDMIRX_G0: P1.Y14 (IO_4A); also elsewhere on the board
HDMIRX_G1: P1.AA15 (IO_4A); also elsewhere on the board
HDMIRX_G2: P1.Y15 (IO_4A); also elsewhere on the board
HDMIRX_G3: P1.AB17 (IO_4A); also elsewhere on the board
HDMIRX_G4: P1.AB18 (IO_4A); also elsewhere on the board
HDMIRX_G5: P1.AB20 (IO_4A); also elsewhere on the board
HDMIRX_G6: P1.Y16 (IO_4A); also elsewhere on the board
HDMIRX_G7: P1.AB21 (IO_4A); also elsewhere on the board
HDMIRX_HSYNC: P1.W19 (IO_4A); also elsewhere on the board
HDMIRX_I2S0: P1.Y20 (IO_4A); also elsewhere on the board
HDMIRX_I2S_BCK: P1.Y19 (IO_4A); also elsewhere on the board
HDMIRX_I2S_WS: P1.W22 (IO_4A); also elsewhere on the board
HDMIRX_R0: P1.Y17 (IO_4A); also elsewhere on the board
HDMIRX_R1: P1.T14 (IO_4A); also elsewhere on the board
HDMIRX_R2: P1.AA17 (IO_4A); also elsewhere on the board
HDMIRX_R3: P1.U15 (IO_4A); also elsewhere on the board
HDMIRX_R4: P1.AA18 (IO_4A); also elsewhere on the board
HDMIRX_R5: P1.AA19 (IO_4A); also elsewhere on the board
HDMIRX_R6: P1.V20 (IO_4A); also elsewhere on the board
HDMIRX_R7: P1.AA20 (IO_4A); also elsewhere on the board
HDMIRX_VSYNC: P1.AB22 (IO_4A); also elsewhere on the board
HDMITX_5V_EN: P1.L22 (IO_5B); also elsewhere on the board
HDMITX_B4: P1.K22 (IO_5B); also elsewhere on the board
HDMITX_B5: P1.L18 (IO_5B); also elsewhere on the board
HDMITX_B6: P1.K21 (IO_5B); also elsewhere on the board
HDMITX_B7: P1.L19 (IO_5B); also elsewhere on the board
HDMITX_G0: P1.M21 (IO_5B); also elsewhere on the board
HDMITX_G1: P1.L17 (IO_5B); also elsewhere on the board
HDMITX_G2: P1.M20 (IO_5B); also elsewhere on the board
HDMITX_G3: P1.K17 (IO_5B); also elsewhere on the board
HDMITX_G4: P1.M18 (IO_5B); also elsewhere on the board
HDMITX_G5: P1.N19 (IO_5B); also elsewhere on the board
HDMITX_G6: P1.N21 (IO_5B); also elsewhere on the board
HDMITX_G7: P1.N20 (IO_5B); also elsewhere on the board
HDMITX_I2S0: P1.R14 (IO_4A); also elsewhere on the board
HDMITX_I2S_BCK: P1.U22 (IO_4A); also elsewhere on the board
HDMITX_I2S_WS: P1.W21 (IO_4A); also elsewhere on the board
HDMITX_PCLK: P1.M22 (IO_5B); also elsewhere on the board
HDMITX_R0: P1.P17 (IO_5A); also elsewhere on the board
HDMITX_R1: P1.P18 (IO_5A); also elsewhere on the board
HDMITX_R2: P1.P16 (IO_5A); also elsewhere on the board
HDMITX_R3: P1.P19 (IO_5A); also elsewhere on the board
HDMITX_R4: P1.R17 (IO_5A); also elsewhere on the board
HDMITX_R5: P1.R16 (IO_5A); also elsewhere on the board
HDMITX_R6: P1.R15 (IO_5A); also elsewhere on the board
HDMITX_R7: P1.T15 (IO_5A); also elsewhere on the board
HDMITX_SPDIF: P1.V19 (IO_4A); also elsewhere on the board
HDMI_RESET#: P1.Y22 (IO_4A); also elsewhere on the board
SCL: P1.P14 (IO_4A), R61.2; also elsewhere on the board
SDA: P1.Y21 (IO_4A), R62.2; also elsewhere on the board

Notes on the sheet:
VCCIO = 3.3V

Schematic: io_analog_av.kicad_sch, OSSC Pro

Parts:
C291, C292: 0.1u; C_0402_1005Metric
D27, D28, D31: PESD5V0U4BW; SOT-665
D30: PESD5V0V4UW; SOT-665
D49, D50, D51: PESD12VL2BT; SOT-23
J10: ICD15S13E4GV00LF; VGA_CONN
J11: PJRAN3X1U03X; 3xRCA_CONN
J13: SJ1-3533NG; Jack_3.5mm_CUI_SJ1-3533NG_Horizontal
J14: PJRAN2X1U02X; 2xRCA_CONN
J17: K-SCARTX-022; SCART_CONN
U20: FSA2275UMX

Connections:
/I/O - Analog AV/AV3_AL_MUX: D50.1 (TVS1), J13.T, U20.4 (LOUT)
/I/O - Analog AV/AV3_AR_MUX: D50.2 (TVS2), J13.R, U20.5 (ROUT)
AUDMUX: U20.6 (SEL); also elsewhere on the board
AV1_AL: D49.1 (TVS1), J17.6, U20.12 (L_IN1); also elsewhere on the board
AV1_AR: D49.2 (TVS2), J17.2, U20.10 (R_IN1); also elsewhere on the board
AV1_B: D31.4 (TVS3), J17.7; also elsewhere on the board
AV1_G: D31.3 (TVS2), J17.11; also elsewhere on the board
AV1_HS: D30.1 (IO1), J17.12; also elsewhere on the board
AV1_R: D31.1 (TVS1), J17.15; also elsewhere on the board
AV1_S: D31.5 (TVS4), J17.20; also elsewhere on the board
AV1_VS: D30.3 (IO2), J17.10; also elsewhere on the board
AV2_AL: D51.1 (TVS1), J14.1 (L); also elsewhere on the board
AV2_AR: D51.2 (TVS2), J14.3 (R); also elsewhere on the board
AV2_B: D27.4 (TVS3), J11.5 (B); also elsewhere on the board
AV2_G: D27.3 (TVS2), J11.3 (G); also elsewhere on the board
AV2_R: D27.1 (TVS1), J11.1 (R); also elsewhere on the board
AV3_AL: U20.11 (L_IN2); also elsewhere on the board
AV3_AR: U20.9 (R_IN2); also elsewhere on the board
AV3_B: D28.4 (TVS3), J10.3 (BLUE); also elsewhere on the board
AV3_G: D28.3 (TVS2), J10.2 (GREEN); also elsewhere on the board
AV3_HS: D30.4 (IO3), J10.13 (HSYNC); also elsewhere on the board
AV3_R: D28.1 (TVS1), J10.1 (RED); also elsewhere on the board
AV3_S: D28.5 (TVS4), J10.4 (ID2/RES); also elsewhere on the board
AV3_VS: D30.5 (IO4), J10.14 (VSYNC); also elsewhere on the board
DVDD3v3: C292.1, U20.1 (VDD); also elsewhere on the board
GND: C291.2, C292.2, D27.2 (COM), D28.2 (COM), D30.2 (GND), D31.2 (COM), D49.3 (COM), D50.3 (COM), D51.3 (COM), J10.5 (GND_HSYNC), J10.6 (RED_RTN), J10.7 (GREEN_RTN), J10.8 (BLUE_RTN), J10.10 (GND_VSYNC), J11.2 (R_GND), J11.4 (G_GND), J11.6 (B_GND), J13.S, J14.2 (L_GND), J14.4 (R_GND), J17.4, J17.5, J17.9, J17.13, J17.14, J17.17, J17.18, J17.21, U20.3 (GND), U20.7 (MUTE), U20.8 (GND); also elsewhere on the board
unnamed: C291.1, U20.2 (C_EXT)

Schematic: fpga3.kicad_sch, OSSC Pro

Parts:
P1: 5CEFA5F23
R47, R60: 2.2k; R_0402_1005Metric
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

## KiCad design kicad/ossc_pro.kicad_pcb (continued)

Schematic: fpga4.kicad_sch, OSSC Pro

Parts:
P1: 5CEFA5F23
R45, R46, R49, R50, R51, R53, R54: 10k; R_0402_1005Metric
R52: 1k; R_0402_1005Metric
R82: 240; R_0603_1608Metric

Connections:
AS_DATA0: P1.AB4 (AS_DATA0); also elsewhere on the board
AS_DATA1: P1.AB3 (AS_DATA1); also elsewhere on the board
AS_DATA2: P1.AA5 (AS_DATA2); also elsewhere on the board
AS_DATA3: P1.T4 (AS_DATA3); also elsewhere on the board
AUDMUX: P1.T19 (RZQ1); also elsewhere on the board
BTN4: P1.N9 (CLK1P); also elsewhere on the board
BTN5: P1.V14 (CLK2N); also elsewhere on the board
CLK27_1v2: P1.H16 (CLK11P); also elsewhere on the board
DVDD3v3: P1.F3 (MSEL4), P1.J6 (MSEL1), P1.L6 (MSEL0), R45.1, R46.1, R49.1, R50.1, R51.1, R53.1, R54.1; also elsewhere on the board
EXP_IO_A_0|CLKIN_P: P1.W16 (CLK3P); also elsewhere on the board
EXP_IO_A_1|CLKIN_N: P1.V16 (CLK3N); also elsewhere on the board
EXP_IO_B_18_1v2: P1.G10 (CLK9P); also elsewhere on the board
EXP_IO_B_19_1v2: P1.F10 (CLK9N); also elsewhere on the board
FLASH_SCK: P1.V3 (DCLK); also elsewhere on the board
FLASH_nCSO: P1.R4 (NCSO); also elsewhere on the board
GND: P1.A2 (MSEL2), P1.AB16 (VREFB4AN0), P1.E5 (MSEL3), P1.G5 (NCE), P1.L20 (VREFB5BN0), P1.R20 (VREFB5AN0), P1.Y7 (VREFB3AN0), P1.Y12 (VREFB3BN0), R52.2, R82.2; also elsewhere on the board
HDMIRX_PCLK: P1.V15 (CLK2P); also elsewhere on the board
HDMITX_B0: P1.P22 (IO_5A); also elsewhere on the board
HDMITX_B1: P1.R21 (IO_5A); also elsewhere on the board
HDMITX_B2: P1.R22 (IO_5A); also elsewhere on the board
HDMITX_B3: P1.T22 (IO_5A); also elsewhere on the board
HDMITX_DE: P1.T17 (IO_5A); also elsewhere on the board
HDMITX_HSYNC: P1.T18 (IO_5A); also elsewhere on the board
HDMITX_VSYNC: P1.T20 (IO_5A); also elsewhere on the board
IR_RX: P1.P9 (CLK1N); also elsewhere on the board
ISL_HSYNC: P1.R6 (IO_3A); also elsewhere on the board
ISL_INT#: P1.W8 (IO_3A), R46.2; also elsewhere on the board
ISL_RESET#: P1.P6 (IO_3A), R45.2; also elsewhere on the board
ISL_VSYNC: P1.R5 (IO_3A); also elsewhere on the board
LED0: P1.H15 (CLK11N); also elsewhere on the board
LED1: P1.H13 (CLK10P); also elsewhere on the board
LED2: P1.G13 (CLK10N); also elsewhere on the board
unnamed: P1.B11 (RZQ2), R82.1
unnamed: P1.K6 (CONF_DONE), R50.2
unnamed: P1.A4 (NCONFIG), R49.2
unnamed: P1.H5 (NSTATUS), R51.2
PCM_I2S_BCK: P1.M6 (IO_3A); also elsewhere on the board
PCM_I2S_DATA: P1.M7 (IO_3A); also elsewhere on the board
PCM_I2S_WS: P1.R7 (IO_3A); also elsewhere on the board
SD_CLK: P1.N6 (IO_3A); also elsewhere on the board
SD_CMD: P1.W9 (IO_3A); also elsewhere on the board
SD_DATA0: P1.T7 (IO_3A); also elsewhere on the board
SD_DATA1: P1.U6 (IO_3A); also elsewhere on the board
SD_DATA2: P1.V6 (IO_3A); also elsewhere on the board
SD_DATA3: P1.T8 (IO_3A); also elsewhere on the board
SD_DETECT: P1.AB13 (RZQ0); also elsewhere on the board
SI_CLK_XTRA1: P1.M16 (CLK6N); also elsewhere on the board
SI_PCLK: P1.N16 (CLK6P); also elsewhere on the board
TCK: P1.V5 (TCK), R52.1; also elsewhere on the board
TDI: P1.W5 (TDI), R54.2; also elsewhere on the board
TDO: P1.M5 (TDO); also elsewhere on the board
TMS: P1.P5 (TMS), R53.2; also elsewhere on the board
USB_D+: P1.U8 (IO_3A); also elsewhere on the board
USB_D-: P1.U7 (IO_3A); also elsewhere on the board
VREFDQ_LPDDR2: P1.B8 (VREFB8AN0), P1.C14 (VREFB7AN0); also elsewhere on the board

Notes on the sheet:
VCCIO = 1.2V / 3.3V
VCCIO = 3.3V

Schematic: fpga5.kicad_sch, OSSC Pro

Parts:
P1: 5CEFA5F23
R100: 2k; R_0603_1608Metric
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

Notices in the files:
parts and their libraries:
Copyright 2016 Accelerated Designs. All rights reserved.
